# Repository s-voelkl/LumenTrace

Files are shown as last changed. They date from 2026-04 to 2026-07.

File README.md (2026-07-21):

# LumenTrace

A high-performance MCU-based LED racing simulator. Bringing the classic slot car experience to the world of addressable LEDs with real-time physics and advanced light effects.

> [!IMPORTANT]
>
> The **source code** for this project is available on **GitHub**: [github.com/s-voelkl/LumenTrace](https://github.com/s-voelkl/LumenTrace) [voelkl:2026lumentrace]

<div align="center">
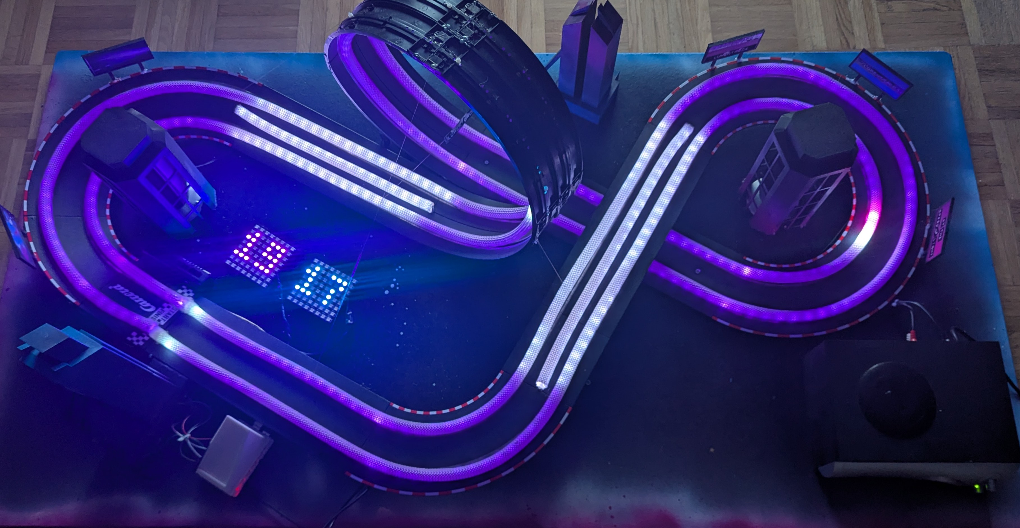
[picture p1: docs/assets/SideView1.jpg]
LumenTrace Game
  
</div>

References are provided in the format `[author:yearidentifier]` and are listed in the [Bibliography](docs/tech-rep/references.bib).

## Used Technologies

- Microcontrollers: Raspberry Pi Pico (Input Controller) and Raspberry Pi 4 (Core Host) [magpi:2024raspberry] with a micro-SD card for data storage.
- Programming Languages: MicroPython [george:2026micropython] for the microcontroller firmware, Python for OOP design, data processing, led display, sound, testing, simulation and visualization.
- Communication Protocols: High-Speed serial communication between Pico and Pi 4 with UART [pena:2020uart,liechti:2020pyserial], LED control via WS2812 [garff:2023rpi].
- Data Storage: Micro-SD card for storing and running the program on the Pi.

<div align="center">
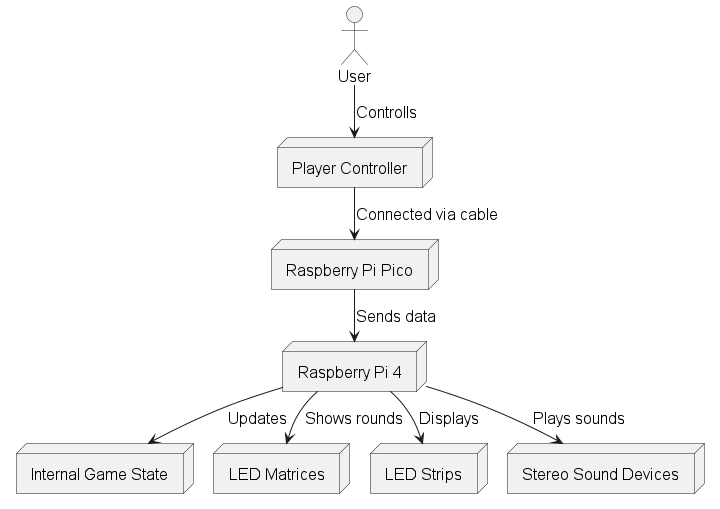
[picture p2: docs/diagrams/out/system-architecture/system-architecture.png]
System Architecture Diagram
  
</div>

## License

This project source code is licensed under the [MIT License](LICENSE). The documentation and assets are licensed under the [Creative Commons Attribution 4.0 International License](docs/LICENSE).

## Maintainers

The contributors and maintainers of this project are:

- Simon Völkl (<s.voelkl2@oth-aw.de>)
- Erik Dombrowsky (<e.dombrowsky@oth-aw.de>)
- Simon Frey (<s.frey@oth-aw.de>)

The project is part of the [Physical Computing Course](https://www.oth-aw.de/forschung/forschungseinrichtungen/labore/fakultaet-elektrotechnik-medien-und-informatik/labor-medieninformatik/physical-computing/) at the [OTH Amberg-Weiden](https://www.oth-aw.de/). The project is supervised by [Prof. Dipl.-Des. Martin Frey](https://www.oth-aw.de/hochschule/ueber-uns/personen/frey-martin/) and [Prof. Dr.-Ing. Ulrich Schäfer](https://www.oth-aw.de/schaefer-ulrich/ueber/).

## Initial Project Requirements

The following represents the original project requirements that evolved and adapted dynamically throughout development:

> Mechanics-free slot car track with: Control system, 3D printing, multiple RGB LED strips, sound, based on Raspberry Pi Pico 2W with PIO.

## Features

- **Realistic Physics Engine** – Experience accurate virtual slot car behavior with collision detection, dynamic acceleration/deceleration, and recovery mechanics that respond to your driving style.
- **Immersive LED Visuals** – Watch your car come alive with adaptive lighting: headlights brighten during acceleration, brake lights glow when decelerating, and dynamic lane indicators guide your racing line.
- **Live Round Counter** – Real-time LED matrix displays show your lap count instantly, keeping you informed of your progress without missing a beat.
- **Intuitive Control System** – Simple button-based controls for throttle and lane switching let you focus on racing, not learning complex mechanics.
- **Spatial Audio Experience** – Engine sounds respond to your speed and acceleration, with stereo positioning that tracks your position on the track for a truly immersive audio environment.
- **Adaptive Track Modules** – Each track section has unique driving characteristics and speed limits. Master different module types to optimize your performance.
- **Customizable Racing Experience** – Adjustable difficulty levels and driving profiles let you tailor the challenge to your skill level, from casual fun to competitive intensity.
- **Multi-Player Racing** – Compete against others in real-time with synchronized physics, collision detection, and dynamic lane management for intense multiplayer action.

## Usage

> [!NOTE]
> **Usage instructions:** For general requirements and usage instructions, please refer to the [Raspberry Pi 4](docs/rpi_4/rpi_4_config.md) and [Raspberry Pi Pico](docs/rpi_pico/rpi_pico_config.md) configuration guides.

**Docker** [merkel:2014docker] is used to provide a consistent, isolated environment for running the LumenTrace application on the Raspberry Pi 4. It automatically handles the installation of required system-level libraries and guarantees necessary privileged access for hardware GPIO [croston:2022raspberry], audio, and UART. By using docker, the application starts up automatically on boot and can be easily adjusted in a system-independent manner.

> [!NOTE]
> **Docker setup:** See the [Docker setup](docs/rpi_4/rpi_4_docker.md) for instructions on how to build and run the Docker container for LumenTrace.

## Hardware

The system is built on a distributed hardware architecture combining a Raspberry Pi 4 (Core Host) and a Raspberry Pi Pico (Input MCU).

- **Raspberry Pi 4 (Core Host):** Runs the main Python application (`src.rpi_4.main`), managing the game logic, physics simulation, LED display buffers, sound mixing, and logging.
- **Raspberry Pi Pico (Input MCU):** Runs MicroPython [george:2026micropython] firmware (`src.rpi_pico.main`) polling inputs from physical controllers (analog throttles via ADCs and digital buttons).
- **Communication:** The Pico transmits the controller states as a serialized format (JSON [json:2026introducing]) to the RPi 4 over UART [pena:2020uart] at high speed, removing the polling overhead from the main host.
- **LED Matrices & Strips:** RPi 4 drives WS2812B LEDs using DMA (PWM on GPIO 18/19), where the LED matrices for lap counting are physically chained before the track strips to minimize occupied hardware channels.
- **Audio:** Real-time engine and event audio is routed out of the Pi to stereo speakers.

<div align="center">
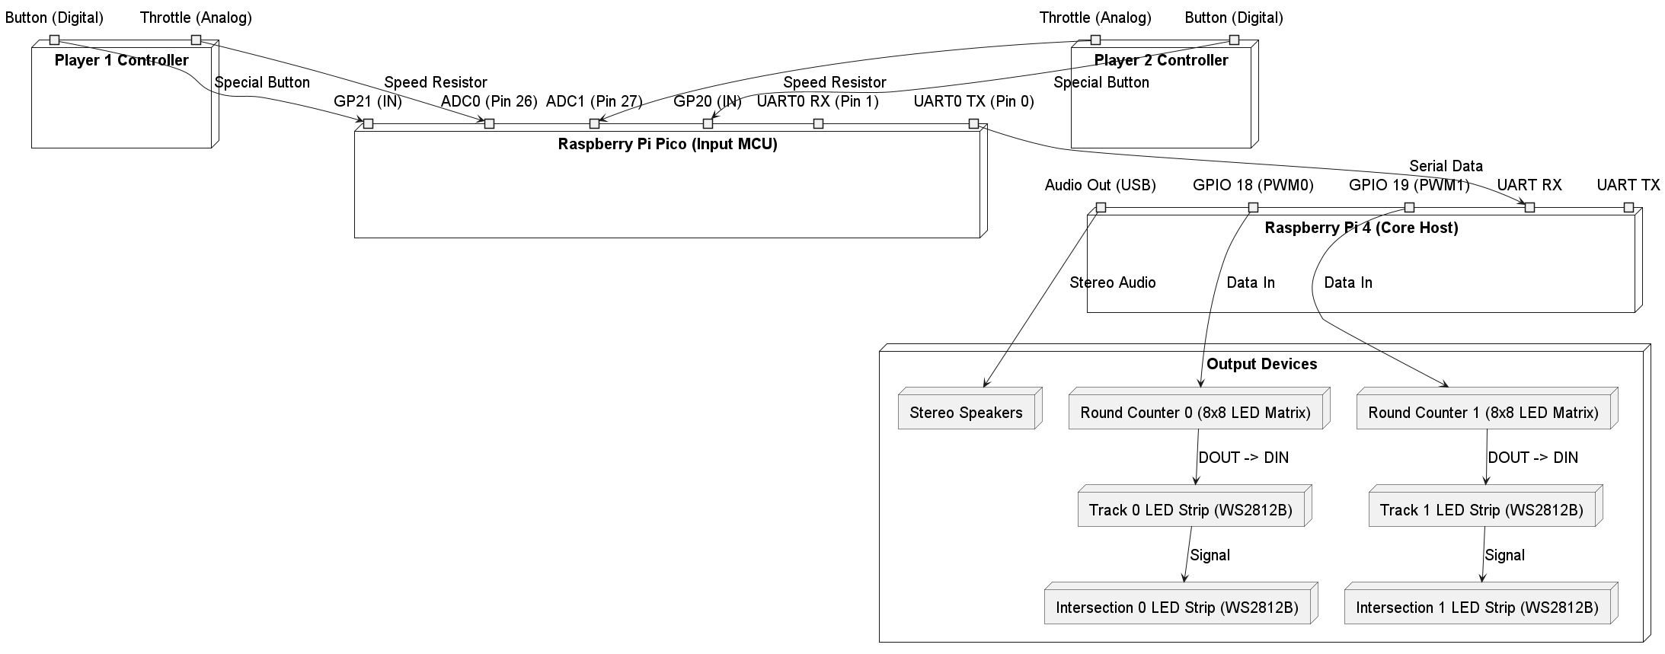
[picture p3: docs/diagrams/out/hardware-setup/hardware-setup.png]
Hardware Setup Diagram
  
</div>

## Architecture

The architecture is designed to be modular and extensible, with clear separation of concerns between different components:

- `Game` package handles the core game logic, including vehicle physics, track management, and players.
- `Simulation` package provides tools for testing and visualizing the game mechanics in Python.
- `Logger` package manages logging and debugging output for log files and MQTT [mqtt:2026mqtt] [light:2026paho]. Our approach to MQTT logging was inspired by the projects [voelkl:2026sensiq] and [voelkl:2026bitebound].
- `Controller` package handles player input and translates it into game actions.
- `Display` package manages the LED effects and visual feedback for the game.
- `Sound` package provides a real-time, threaded audio mixer.

<div align="center">
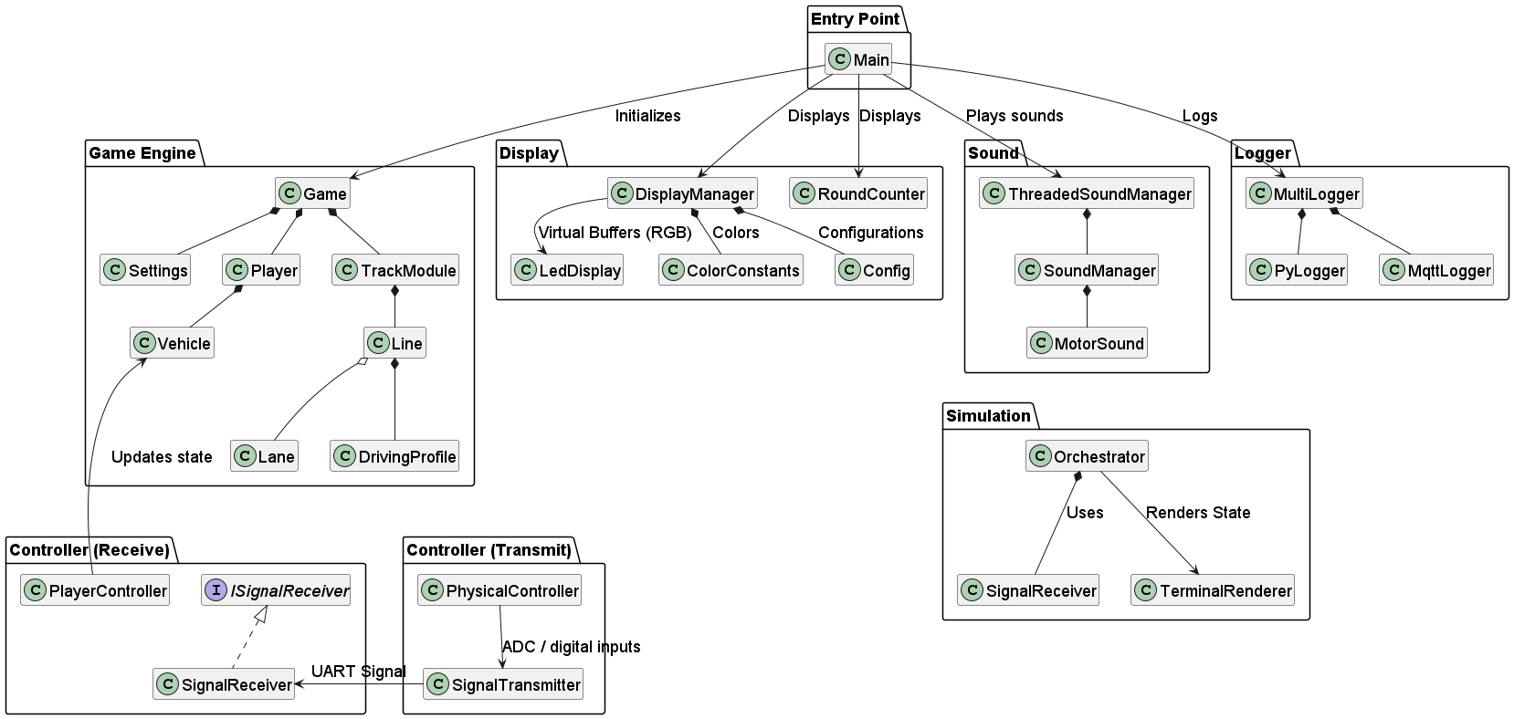
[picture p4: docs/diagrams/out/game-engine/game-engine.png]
Game Engine Architecture
  
</div>
<!-- ![Game Engine Architecture](docs/diagrams/out/game-engine/game-engine.png) -->

## LED Color Management

This project separates LED rendering into two responsibilities: color/buffer management and hardware rendering.

- `src/display/led_display.py`: Maintains per-lane virtual LED buffers and maps them onto physical `PixelStrip` instances. Implements helpers to set single pixels, windows and fill sections with a configurable color ratio.
- `src/display/display_manager.py`: Game-state -> visual logic. Implements the display hierarchy and writes colors into the virtual buffers maintained by the LED display.
- `src/display/color_constants.py`: Central RGB color constants used across the display code.
- `src/display/config.py` (and `DisplayConfig`): Runtime parameters that control blink intervals, round advance timing and other display tuning.

Display hierarchy (applied from low priority -> high priority):

1. **Track module base**: Entire lanes are painted a faint dark gray (ratio ~0.1) and each module's first pixel is emphasized (ratio ~0.3) to make module boundaries visible.
2. **Intersection module**: Track modules with allowed lane changes are painted with a light pink base (ratio ~0.1).
3. **Intersection animation**: When a vehicle is currently on an intersection the lane is temporarily overlaid with light pink (ratio ~0.2) to indicate the interaction.
4. **Start of the track**: The first pixel of every lane is marked as a start/end line (gray).
5. **Round advance**: When a vehicle completes a lap the start pixel blinks between yellow and white for a configured number of ticks.
6. **Inactive vehicles (respawn)**: Vehicles that are inactive or respawning blink between their primary color and gray (40% primary + 60% gray).
7. **Active vehicle**: Final override — vehicle sprite is drawn centered on the vehicle position. Color depends on the driving profile and vehicle speed [meschtscherjakov:2015chaselight]. Speeds near zero use the vehicle's primary color; values beyond thresholds interpolate toward accelerate/decelerate warning colors.
8. **Vehicle front lights**: Overlay front lighting (light gray) for vehicles that are currently accelerating.
9. **Vehicle rear lights**: Overlay rear brake lighting (red) for vehicles that are currently decelerating.

How the strips are controlled:

- Physical output uses the `rpi_ws281x` library (`PixelStrip`, `Color`) [garff:2023rpi]. Two GPIO channels are supported by default: `18` and `19` ([see Library on GitHub](https://github.com/richardghirst/rpi_ws281x))

> [!NOTE]
> **LED Mounting and Physical Chaining:** To map LEDs accurately to the physical track, the main strips were rigidly fastened using zip ties. Because both of the Pi 4's PWM channels were utilized for the primary lanes, the temporary central overtaking lane was physically daisy-chained to the end of a primary lane with connecting wires hidden beneath the track.

- The code uses `VirtualLedStrip` instances to map parts of a physical strip to logical lanes. This abstraction allows the display manager to control each segment (Lap Counter, Main Lane, and Overtaking Lane) independently, resolving the hardware channel constraints and hiding the physical daisy-chain from the game logic.
- At each game tick `Game.display()` calls `DisplayManager.update(game)`. The display manager updates the virtual buffers by writing RGB tuples. Finally `LedDisplay.render()` translates virtual buffers to the physical `PixelStrip` objects and calls `show()`.

Tuning and configuration:

- Colors are defined in `src/display/color_constants.py` so they can be changed globally.
- Timing and blinking behavior is configurable via `DisplayConfig` (e.g. `respawn_tick_color_change`, `round_advance_ticks`, `round_advance_tick_color_change`).
- Module boundary brightness and base-track ratio are implemented as small color ratios applied when filling lanes and pixels.

A current implementation of the LEDs can be found in `src/rpi_4/main.py`.

## Round Counter Hardware Integration

To track player progress, the game integrates 8x8 WS2812B LED matrices to display round numbers (00–99) using a 3x5 font mapping. Initial considerations for small LCD screens were discarded as they lacked readability from a 1-meter distance.

### Initial Bottlenecks

Initially, the round counters were configured on separate physical control lines:

- **Player 1 matrix** on GPIO 10 (SPI)
- **Player 2 matrix** on GPIO 21 (PCM)
- **Track lines** on GPIO 18 and 19 (PWM)

> [!CAUTION]
> **Failed Attempt:** This setup failed due to several hardware and library-level constraints:
>
> - **DMA Conflicts**: Initializing four distinct `PixelStrip` objects on DMA (Direct Memory Access) channel 10 caused register collisions and memory mapping failures (`mmap() failed`).
> - **Peripheral Clashes**: The underlying `rpi_ws281x` C driver cannot mix PWM, SPI, and PCM peripherals concurrently in the same process space.
> - **Channel Caps**: The driver structure is hardware-capped at 2 active physical channels.

### Resolved Design

The solution leverages the existing `VirtualLedStrip` concept by chaining the matrices to the end of the track strips:

> [!TIP]
> **Found Solution:**
>
> 1. **Physical Chaining**: The `Data In` (DI) of each matrix is wired to the `Data Out` (DO) of its corresponding track strip.
> 2. **Single-Driver Coordination**: The `num` parameter of the physical strips is increased to encompass the matrix pixels, keeping the physical control line > count at 2 (GPIO 18 & 19).
> 3. **Index Offsetting**: The `RoundCounter` is refactored to write directly to the track's existing `PixelStrip` starting at the correct pixel offset, > bypassing hardware re-initialization.

## Sound Engineering

LumenTrace features a real-time audio engine that turns the race into an immersive, spatial experience [gardenfors:2003designing]. All sound is mixed live on the Raspberry Pi and played back in stereo [geier:2024sounddevice] [bechtold:2026soundfile], so what you hear reflects what is happening on the track at every moment [gan:2019self].

### Real-time audio mixer

A low-level sound manager (`src/sound/sound_manager.py`) mixes any number of sounds simultaneously through a single stereo output stream. Every sound can be controlled independently while it plays:

- **Volume** – per-sound loudness plus a global master volume.
- **Pitch** – dynamic speed/pitch shifting, used to make the engine rev up and down.
- **Stereo panning** – independent left/right balance so sounds can be placed on the left or right side of the track.

To maximize execution speed and ensure high real-time performance on constrained hardware (like the Raspberry Pi), the audio engine is strictly optimized using a **block-level updates architecture** powered by NumPy vectorization [harris:2020array]:

- **Single Frame Indexing:** Rather than generating index arrays inside loops, a single frame index array (`np.arange`) is created once per callback block.
- **No Cumulative Ramping:** Dynamic playback positions are calculated using linear offsets (`arange_frames * pitch`) instead of sequential cumulative sums (`np.cumsum`), bypassing costly sample-by-sample pitch ramping.
- **Scalar Mixing Operations:** Dynamic parameter arrays are replaced with block-level scalar factors (`left_mult`, `right_mult`). Multiplications in the mixing stage are completed directly as fast scalar-by-array operations, avoiding expensive element-wise array generation and multiplications (such as `np.linspace` calls).
- **Smooth Easing:** The mixer gently adjusts overall volume, pitch, and panning properties block-by-block. This provides smooth, click-free parameter transitions at default block sizes (e.g. 1024 frames, ~23ms) while significantly reducing CPU overhead.

All sounds are referenced through a named catalog (`GameSound`), so each effect has a clear, human-readable name and a single source path.

### Thread Isolation & Concurrency Control

Because real-time audio relies on extremely strict timing guarantees, executing Python-based audio callback routines synchronously alongside high-frequency game ticks, screen rendering, and hardware fetching can lead to Global Interpreter Lock (GIL) starvation and severe lock contention.

> [!CAUTION]
> **Audio Engineering Challenges:** Initially, transmitting audio via the Pi 4's AUX jack produced significant background noise, which was resolved by switching to a USB audio interface. However, integrating the audio playback into the main game loop still caused heavy sound stuttering after ~2 seconds.

To eliminate these bottlenecks, LumenTrace isolates the audio interface using a **Thread-Safe Asynchronous Command Queue** pattern (`src/sound/threaded_sound_manager.py`) and multiprocessing principles [eggen:2019thread]:

- **Non-blocking Wrapper (`ThreadedSoundManager`):** Acts as a transparent proxy wrapping the low-level `SoundManager`. Calling threads (such as `GameTickThread` or input fetchers) never block or wait on the underlying mixer locks.
- **FIFO Command Queue:** Methods like `play()`, `update_sound()`, `stop_sound()`, and `stop_all()` immediately enqueue commands into a non-blocking queue [tsigas:2001simple] as lightweight, fire-and-forget tuples, generating trackable UUIDs instantly on the caller thread.
- **Dedicated Sound Worker Thread:** A background worker thread (`SoundWorkerThread`) continuously consumes the command queue and applies state changes to the actual `SoundManager`. This guarantees that high-frequency engine parameter updates do not block or stutter the physics loop.
- **Persistent Streams across Restarts:** The asynchronous `stop_all` implementation selectively clears active playback instances under lock instead of tearing down the audio stream. This keeps the output stream alive and responsive across multiple game restarts and lobby resets without requiring a full audio stream re-initialization.

> [!TIP]
> **Stability Fix:** Alongside the dedicated audio thread, introducing 1ms sleep intervals within the display logic prevented audio thread starvation, ultimately stabilizing the sound output across concurrent workloads.

### Engine sounds

Each car has its own continuous engine sound (`src/sound/motor_sound.py`) that reacts to how it is being driven:

- **Background rumble** follows the car's current **speed** – the faster the car, the higher and louder the engine note.
- **Acceleration layer** adds extra power and volume while the car is actively **accelerating**, so pressing the throttle is clearly audible.
- **Stereo position** follows the **track module** the car is currently on. Each track module defines a `sound_stereo_ratio_left` value (0.0 = fully right, 0.5 = centered, 1.0 = fully left), letting the engine sound travel between the left and right speakers as the car moves through left and right curves.

### Event sounds

On top of the engine, the game plays positional one-shot effects that respond to key race moments. Where it makes sense, these effects are panned to the position of the car that triggered them:

- **Start sequence** – a "3, 2, 1, GO!" signal plays in sync with the red/yellow/green countdown lights when all players hold their start button.
- **New lap** – a confirmation sound when a car completes a lap.
- **Lane change** – a short cue when a player presses the lane-change button.
- **Crash** – an impact sound when two cars collide or a car falls off the track.
- **Warning** – an alert when a car's speed or acceleration gets close to the limits allowed by the current track module's driving profile, hinting that the car is about to fall.

### Sound Effects Sources

> [!NOTE]
> **Sound Attribution:** All sound effects used in LumenTrace are sourced from free, royalty-free libraries [pixabay:2026pixabay] and are credited below. Please refer to the original sources for licensing details.

- base-engine-1.wav: Created by ourselves.
- startup-sound.mp3: <a href="https://pixabay.com/de/users/make_more_sound-35032787/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">Jesse Grum</a> from <a href="https://pixabay.com/sound-effects//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">Pixabay</a>
- car-crash-1.mp3: <a href="https://pixabay.com/de/users/dragon-studio-38165424/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">DRAGON-STUDIO</a> from <a href="https://pixabay.com//?utm_source=link-attribution&utm_medium=referral&utm_campaign=music&utm_content=376874">Pixabay</a>
- car-crash-2.mp3: <a href="https://pixabay.com/users/dragon-studio-38165424/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">DRAGON-STUDIO</a> from <a href="https://pixabay.com/sound-effects//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">Pixabay</a>
- car-lap-1.mp3: <a href="https://pixabay.com/users/moeeza3-39561198/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">Moeez Ahmad</a> from <a href="https://pixabay.com//?utm_source=link-attribution&utm_medium=referral&utm_campaign=music&utm_content=395038">Pixabay</a>
- car-lap-2.mp3: <a href="https://pixabay.com/users/soundreality-31074404/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">Jurij</a> from <a href="https://pixabay.com//?utm_source=link-attribution&utm_medium=referral&utm_campaign=music&utm_content=151963">Pixabay</a>
- race-finish.mp3: <a href="https://pixabay.com/users/bombinsound-54782632/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">Bomb Sound</a> from <a href="https://pixabay.com/sound-effects//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">Pixabay</a>
- coin-1.mp3: <a href="https://pixabay.com/de/users/u_u9ahoqos39-45535899/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">u_u9ahoqos39</a> from <a href="https://pixabay.com//?utm_source=link-attribution&utm_medium=referral&utm_campaign=music&utm_content=233860">Pixabay</a>
- coin-2.mp3: <a href="https://pixabay.com/users/driken5482-45721595/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">Driken Stan</a> from <a href="https://pixabay.com/sound-effects//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">Pixabay</a>
- warning-1.mp3: <a href="https://pixabay.com/users/dragon-studio-38165424/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">DRAGON-STUDIO</a> from <a href="https://pixabay.com//?utm_source=link-attribution&utm_medium=referral&utm_campaign=music&utm_content=386172">Pixabay</a>
- warning-2.mp3: <a href="https://pixabay.com/users/freesound_community-46691455/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">freesound_community</a> from <a href="https://pixabay.com//?utm_source=link-attribution&utm_medium=referral&utm_campaign=music&utm_content=104576">Pixabay</a>
- game-initialization.mp3: <a href="https://pixabay.com/users/dragon-studio-38165424/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">DRAGON-STUDIO</a> from <a href="https://pixabay.com/sound-effects//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">Pixabay</a>
- vibe-1-retro.mp3: <a href="https://pixabay.com/users/tg14_studios-55924971/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">TG14_Studios</a> from <a href="https://pixabay.com//?utm_source=link-attribution&utm_medium=referral&utm_campaign=music&utm_content=541395">Pixabay</a>
- vibe-2-retro.mp3: <a href="https://pixabay.com/users/freesound_community-46691455/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">freesound_community</a> from <a href="https://pixabay.com/sound-effects//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">Pixabay</a>
- vibe-3-retro.mp3: <a href="https://pixabay.com/users/freesound_community-46691455/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">freesound_community</a> from <a href="https://pixabay.com//?utm_source=link-attribution&utm_medium=referral&utm_campaign=music&utm_content=41048">Pixabay</a>
- punch-1.mp3: From <a href="https://pixabay.com/sound-effects/retro-hurt-sound-03-474780/">Pixabay</a>

## Game Mechanics

The game mechanics are implemented in `src/game` and are designed to provide a realistic and engaging racing experience like in the original slot car games [skaar:2025slot].

### Acceleration and Friction

- Controller input `forward_press` is mapped to vehicle acceleration each game tick. The mapping is configured as inputs [42000, 65536] to outputs [0, 100] with linear interpolation [zheng:2018feature].
- Friction is applied continuously and reduces current speed by a configurable percentage [kane:2022tire].
- Positive and negative movement are supported. If acceleration would invert speed direction in one step, speed is clamped to `0` first to keep transitions stable.

Acceleration mapping formula: $acceleration(forwardPress) = \frac{forwardPress - 42000}{65536 - 42000} * 100$

Sensor measurement transmission must be trustful [voelkl:2026sensiq] for the system handling the incoming data. Although, roughly every 20th controller transmission is lost or unreadable, the game engine is designed to handle this gracefully. Having an update rate of 50Hz, a single lost tick is not critical, the game engine just continues using the last known controller state.

### Speed Update and Limits

- Speed is updated every tick as: `speed += acceleration * acceleration_multiplier`
- Speed is clamped to `[-max_speed, +max_speed]`.
- This allows realistic throttle behavior while preventing unstable values at high update rates.
- A goal is to specify the friction and acceleration multipliers such that the vehicle can't possibly exceed the `max_speed` at all.

### Position and Round (Lap) Handling

- Position is updated from speed using the active game-tick interval.
- Each lane has its own total track length (sum of line lengths across modules).
- When position exceeds lane length, position wraps around and `round` is incremented and the position is reset.
- Reverse movement is also handled, including safe behavior for negative movement near lap boundaries.

### Lane Change

> [!NOTE]
> **Overtaking Mechanics Selection:** We evaluated multiple overtaking approaches: intersecting lanes (ruled out by vertical LED height), converging lanes (abrupt gameplay), and a unidirectional overtaking lane (lacked bidirectional switching). We ultimately chose a **temporary bidirectional center lane** because it offered the optimal balance between playability and realism.
>
> *Challenges solved:* The temporary lane eventually ends, potentially causing unavoidable out-of-bound crashes. We solved this by restricting lane changes beyond a specific point, forcing an automatic merge back to a main lane. We also implemented a cooldown distance (`lane_change_window`) to prevent rapid, successive lane changes and erratic switching.

- Lane changes are triggered by pressing the `special_1` button.
- A lane change is only allowed if the `driving_profile` of the current line has `lane_change_allowed = True`. This is typically used for intersection modules.
- By default, there are two main lanes: the left lane and the right lane. Intersections introduce a temporary middle lane to facilitate the switch.
- A manual lane change from the outer lanes to the middle lane can be initiated anywhere on the module, except for the last `lane_change_window` units before the end of the module.
- After pressing the button, the vehicle switches to the middle lane.
- From the middle lane, the player can switch to the target outer lane manually by pressing the button again, provided the vehicle has travelled at least `lane_change_window` units on the middle lane.
- The vehicle continues on the middle lane until it reaches the end of the module (specifically, `lane_change_window` units before the end). At that point, it automatically switches to the target outer lane, completing the lane change smoothly if the player hasn't already changed lanes manually.

### Position Conversion During Lane Change

- When the vehicle switches to or from the middle lane, it keeps its relative progress within the current track module.
- Conversion is proportional:
  - progress = `source_position / source_line_length`
  - target_position = `progress * target_line_length`
- This keeps cars visually and physically aligned when lane geometries have different lengths.

### Falling, Collision, and Respawn

- A vehicle falls immediately when its current speed or acceleration violates the driving profile of the active line:
  - `speed` must remain within `[min_speed, max_speed]`
  - `acceleration` must remain within `[min_acceleration, max_acceleration]`

> [!NOTE]
> **Track Profile Constraints / Subdivided Modules:** To make difficulty scale smoothly without applying constraints too abruptly upon module entry, specific modules were mathematically subdivided. **Curves** have an Entry (slight restriction), Apex (strongest restriction), and Exit (reduced restriction). **Loops** have an Incline Entry (gravity decelerates), Inverted Apex (high minimum speed required to avoid falling), and Decline Exit (gravity accelerates).

- Collision detection is evaluated for vehicles on the same lane.
  - If two vehicles are within collision distance, the vehicle in front falls.
  - The collision happens, if the position distance between the `settings.__vehicle_crash_distance` is violated.

> [!NOTE]
> **Collision Gameplay Dynamics:** While a real-world collision would likely derail both vehicles, this heavily impacts gameplay negatively. Taking inspiration from other arcade video games, we implemented a system simulating a rear-quarter impact: The leading vehicle loses control and crashes, while the trailing vehicle maintains its trajectory unharmed.

### Respawn System

> [!NOTE]
> **Fair Respawn Logic & The Looping Problem:** Several respawn rules were evaluated:
>
> 1. *Respawn at Start Line:* Harsh penalty causing players to fall too far behind with no chance to interact.
> 2. *Respawn at Exact Crash Location:* Too forgiving, and it introduced the "Looping Problem" (respawning at a standstill inside a loop causes an immediate consecutive crash, as vehicles cannot build the needed momentum).
> 3. *Respawn at Start of Current Module:* Selected for balanced penalization.
>
> A dynamic fallback system handles blocked placements: If a respawn spot is occupied (which would cause an immediate collision upon respawn), the game sequentially checks alternative lanes, then falls back purely to previous modules to grant collision-free placement with enough track length to build momentum for upcoming loops.

- Fallen vehicles become inactive and enter a respawn state (`settings.respawn_ticks`, `vehicle.respawn_ticks`, `vehicle.active`).
- While `vehicle.active` is `False`, vehicles are ignored in the race.
- After the `vehicle.respawn_ticks` count down to `0`, the vehicle attempts to respawn:
  - If the module where the vehicle fell is a LOOPING module, step back one module to avoid respawning in the same looping section (unless it's the only module).
  - Try `position = 0` on the preferred lane within the target respawn module. If not available, try other unoccupied lanes on that module. Unoccupied means no active vehicle is on the module.
  - If no lane is available on the target module, fallback to the previous modules, checking all lanes from outer (most active vehicles) to inner.
  - The vehicle speed and acceleration are reset to `0`, `vehicle.respawn_ticks` to `0`, and its lane change state is cleared.
  - If no lane is available across all candidate modules, the vehicle remains inactive and tries again in the next tick.
- Respawn does not increment `vehicle.round`.

## Design

The design of the LumenTrace system is modular and extensible, allowing for easy integration of new features and components [voelkl:2026bitebound]. In general, the physical design is based on the following components:

- A black wooden plate (150cm × 80cm) as the base for the track layout, sprayed with *blue*, *purple*, and *white* colors for a visually appealing background. All components were rigidly fastened using screws, cyanoacrylate adhesive, and double-sided tape for transportability. The loop module was additionally reinforced with fishing line to reduce vibrations and prevent fractures.
- Carrera GO!!! [carrera:2026carrera] track modules for the physical track layout.
- 2 LED Stripes (WS2812B) for the track lighting and visual effects, mainly in light purple and gray.
- 2 Vehicles in strong blue and purple colors.
- 2 LED Matrizes for round counting in the colors of the vehicles.
- 3D-printed objects as visual enhancements, custom towers to conceal the Raspberry Pi 4, Pico, and internal wiring, and custom audio enclosures to stealthily house the stereo speakers and subwoofer (printed in segments) without breaking the sci-fi aesthetic.

**LED Strip Design Rationale:** The LED stripes do not directly illuminate the user but are housed within a translucent plastic channel, further wrapped with a white fabric strip in a cylindrical configuration. This design approach diffuses light in all directions, creating a uniform and pleasant ambient lighting experience throughout the track environment. Standard LED strips would lack the mechanical flexibility required to conform to the track's varying curvatures and would fail to distribute light evenly across all viewing angles. Additionally, power consumption was carefully constrained, as the system is powered directly from the Raspberry Pi; exceeding safe current limits would necessitate thicker cabling and an external high-capacity power supply, both of which would compromise system safety and transportability. The implementation employs two WS2812B addressable LED strips, each equipped with 50 Neopixel LEDs per meter, totaling 250 LEDs across the entire track lighting system.

The resulting design is a **retro-futuristic** blue-purple racing environment with a focus on immersive lighting and sound effects.

<div align="center">
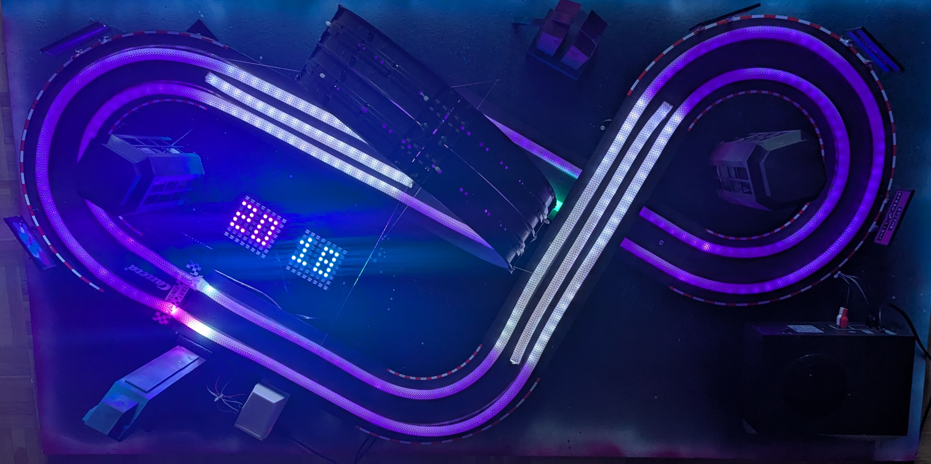
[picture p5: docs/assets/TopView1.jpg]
LumenTrace Top View
  
</div>

### 3D-Printed Objects

All 3D-printed objects were designed in Blender, Fusion 360, TinkerCAD, retrieved from Online Sources, or generated by AI. The files are available in the `3d-models` folder, see the [documentation file](3d-models/3d-models.md) for details.

## Local Simulation and Unit Tests

> [!NOTE]
> **Simulation Runner:** For fast manual validation of game logic, a text-based simulation runner is available at `src/dev/simulation.py`.
> Execution is possible with: `python -m src.dev.main`

A simulation dashboard was developed during the development phase to visualize the game state in real-time without the need for physical hardware. As the code has evolved, the simulation *might not be fully up-to-date* with the current game logic, but it still serves as a useful tool for debugging and understanding the system's behavior.

The simulation dashboard displays:

- Global settings (`max_speed`, friction, lane-change timing, respawn timing, etc.)
- Full player and vehicle telemetry (lane, position, speed, acceleration, lap, respawn state)
- Full track module list including per-lane driving profiles
- Current player module context (`module_index:track_type@local_position`)
- ASCII lane visualization with module boundaries and live player markers

Additionally, unit tests were created to validate the logic of specific components during the development phase, as described in the [test document](tests/tests.md).

<div align="center">
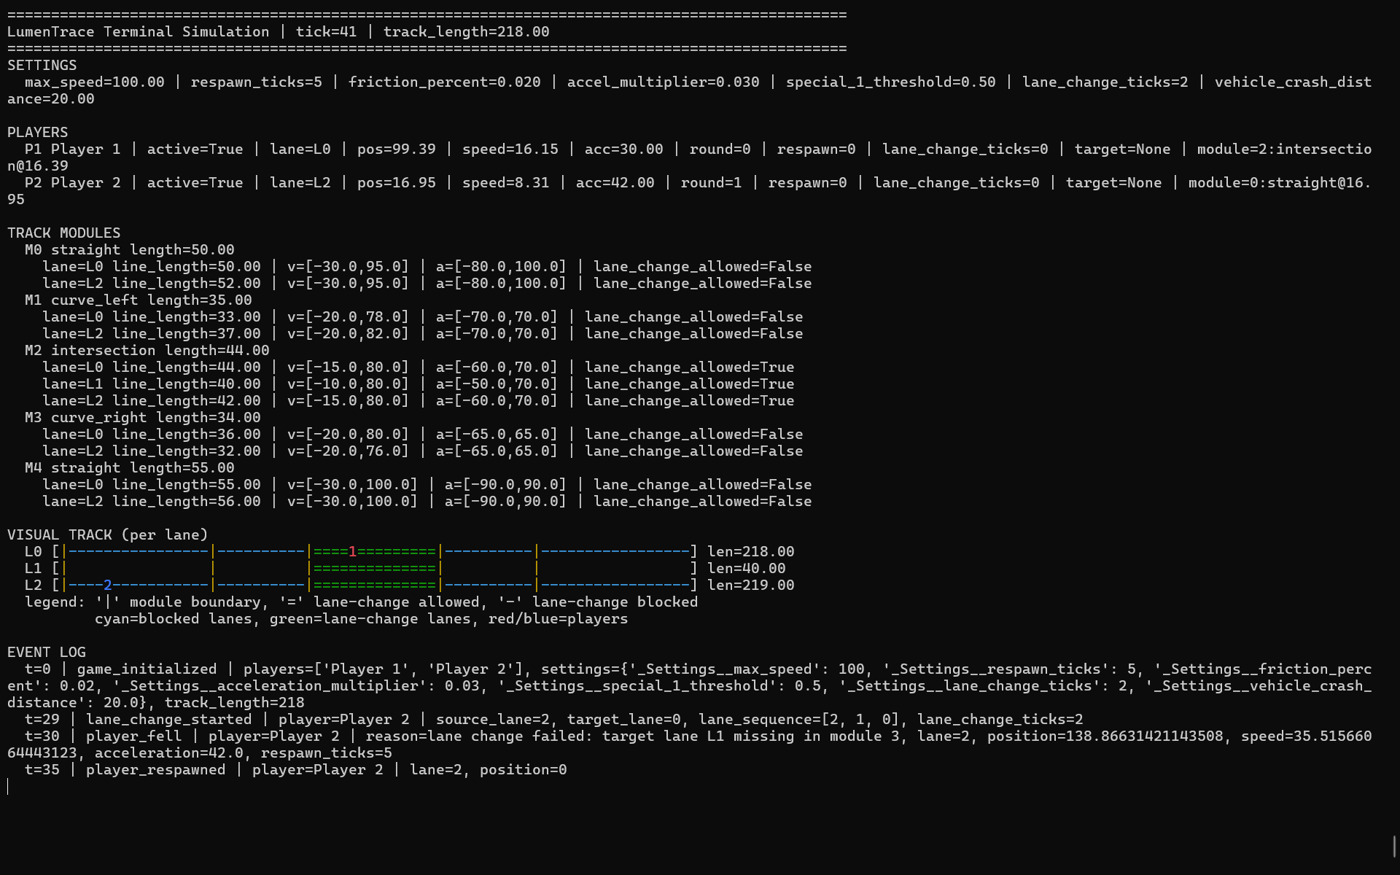
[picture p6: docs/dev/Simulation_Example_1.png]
Simulation Example
  
</div>

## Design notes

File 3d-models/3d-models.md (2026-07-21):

# 3D Models — LumenTrace

## Overview

The 3D model collection supports LumenTrace's physical infrastructure [voelkl:2026lumentrace], combining functional mechanical components with decorative environmental assets. Models are designed for 3D printing in a cohesive sci-fi aesthetic, integrating seamlessly with the racing simulation environment and audio system.
Not all of the proposed models were used in the final build, as some were replaced with alternative solutions during development or were not able to be produced due to time, resource and real-world constraints.

## Model Categories

### Mechanical Components

Functional parts required for the racing track and LED integration, including LED strip mounting fixtures, connectors, and control cable housings. Even though these components are engineered for precision fit and durability under repeated use, they were not used in the final product, as better alternatives were found and implemented.

### Environmental Decoration

Scenery and decorative structures that establish the immersive sci-fi environment surrounding the race track. These include landscape elements, architectural structures, lighting fixtures, and industrial-themed accents that enhance visual immersion without affecting gameplay.

### Audio Equipment Integration

Custom enclosures and housings for the 2.1-channel stereo speaker system, designed to complement the overall aesthetic. These cases provide protection for the audio components while ensuring optimal sound projection and integration with the track environment.

## Design and Production

All 3D-printed objects were designed in Blender, Fusion 360, TinkerCAD, retrieved from Online Sources, or generated by AI. The files are available in the folders `scad` and `stl`.

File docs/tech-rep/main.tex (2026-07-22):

\documentclass[10pt,journal,final,a4paper]{IEEEtran}

% --- 1. Mathematik & Symbole ---
\usepackage{amsmath} 
\usepackage{amssymb}
\usepackage{amsfonts}

% --- 2. Code-Blöcke (Zuerst laden wegen fvextra/lineno-Interaktionen) ---
% \usepackage{minted} 
\usepackage{listings}

% --- 3. Text & Sprache (csquotes MUSS nach minted/fvextra geladen werden) ---
\usepackage{csquotes} 

% --- 4. Tabellen & Grafiken ---
\usepackage{color,array}
\usepackage{graphicx}
\usepackage{multirow} 
\usepackage{booktabs} 
\usepackage{float}
\usepackage{siunitx}
\usepackage{tabularx}

% --- 5. IEEEtran Layout-Helfer (algorithmic gelöscht, da nicht vorhanden/benötigt) ---
\usepackage[caption=false,font=normalsize,labelfont=sf,textfont=sf]{subfig}
\usepackage{textcomp}
\usepackage{stfloats}
\usepackage{verbatim}
\usepackage{balance}

% --- 6. Links & Referenzen (Immer ganz ans Ende der Präambel) ---
\usepackage[colorlinks,urlcolor=blue,linkcolor=blue,citecolor=blue]{hyperref}
\usepackage{orcidlink} % benötigt hyperref, daher danach laden
\usepackage[capitalise,nameinlink,noabbrev]{cleveref} % MUSS als letztes geladen werden

% --- IEEEtran spezifische Definitionen ---
\hyphenation{op-tical net-works semi-conduc-tor IEEE-Xplore}
\def\BibTeX{{\rm B\kern-.05em{\sc i\kern-.025em b}\kern-.08em
    T\kern-.1667em\lower.7ex\hbox{E}\kern-.125emX}}

\newtheorem{theorem}{Theorem}
\newtheorem{lemma}{Lemma}
\setcounter{page}{1}

\begin{document}

\title{LumenTrace: A Mechanics-Free LED Slot Car Racing Game with Real-Time Physics and Immersive Audiovisual Feedback} 

% TODO FOR PUBLICATION: Remove Physical Computing Lecture from author footnote, add ORCID links to all authors.
\author{Simon Völkl\,\orcidlink{0009-0005-5334-9673}, 
        Erik Dombrowsky, 
        and Simon Frey%
\thanks{The authors are with the Department of Electrical Engineering, Media, and Computer Science, Ostbayerische Technische Hochschule Amberg-Weiden, 92224 Amberg, Germany (e-mail: s.voelkl2@oth-aw.de; e.dombrowsky@oth-aw.de; s.frey@oth-aw.de). The project is part of the Physical Computing Course at OTH Amberg-Weiden and is supervised by Prof. Dipl.-Des. Martin Frey and Prof. Dr.-Ing. Ulrich Schäfer.}%
}

% \markboth{TECHNICAL REPORT, 07 2026}
% TODO FOR PUBLICATION: Update date to actual submission date, remove information from lecture.
\markboth{TECHNICAL REPORT FOR PHYSICAL COMPUTING LECTURE AT OTH AMBERG-WEIDEN, 07 2026}
{Völkl \MakeLowercase{\textit{et al.}}: LumenTrace}

\maketitle

\begin{abstract}
    % \textbf{Background:} 
    Classic slot car systems offer an engaging tactile racing experience, yet they remain bound to physical vehicles on mechanical rails and treat light and sound as secondary embellishments. Simultaneously, minimalist LED racers reduce gameplay to button pressing and omit realistic physics, spatial audio and advanced track features.
    % \textbf{Objective:} 
    LumenTrace aims to unite the physical realism and playability of slot cars with the mechanical simplicity and immersive, state-driven audiovisual feedback that individually addressable LEDs make possible.
    % \textbf{Methods:} 
    The system is built on a distributed Raspberry~Pi Pico and Raspberry~Pi~4 architecture. A real-time physics engine models acceleration, friction, collision detection, and crash recovery from throttle and button inputs transmitted over a high-speed UART link. A priority-based LED rendering pipeline displays adaptive, state-dependent track and vehicle effects, complemented by a stereo audio mixer.
    % \textbf{Results:} 
    The system meets its real-time thread budgets and low-latency requirements, resulting in positive user feedback during playtests, though it lacks cost-effectiveness for open-source developers. 
    % \textbf{Conclusion:} 
    LumenTrace closes the gap between commercial slot car systems and minimalist LED racers, while providing highly performant, maintainable and safe system architecture. Future work focuses on cost reduction, improved playability, and game extensions.
\end{abstract}

\begin{IEEEkeywords}
    Distributed Embedded Systems, LED Racing Game, Microcontroller, Real-Time Physics Engine, Slot Car Racing, Spatial Audio, WS2812B
\end{IEEEkeywords}

% \tableofcontents

\section{Introduction}
\label{sec:introduction}

\IEEEPARstart{S}{lot} car racing has entertained enthusiasts for decades, but its classic form ties the experience to physical vehicles running on mechanical rails, where light and sound serve merely as peripheral embellishments. 
LumenTrace reimagines this concept as a mechanics-free racing simulator in which each vehicle is represented directly as a moving point of light on an individually addressable light-emitting diode (LED) strip. 
Built on a distributed architecture of a Raspberry~Pi Pico and a Raspberry~Pi~4~\cite{magpi:2024raspberry}, the system couples a real-time physics engine with a priority-based LED rendering pipeline and a spatial audio mixer to deliver an immersive, state-driven racing experience without any moving mechanical parts. 
The complete source code and documentation are publicly available in the project's GitHub repository~\cite{voelkl:2026lumentrace}.

\begin{figure*}[tb]
    \centering
    
    \caption{LumenTrace: at the speed of light. Full-scale setup of the LED racing game showing the track, vehicles, controllers, and audiovisual system.}
    \label{fig:lumentrace-setup}
\end{figure*}

\subsection{Motivation}
\label{subsec:motivation}

Classic slot car systems deliver an engaging tactile racing experience, but they remain bound to physical vehicles running on mechanical rails. In these systems, light and sound are treated as peripheral add-ons rather than as core gameplay elements: engine sounds are typically monotone and decoupled from the vehicle's actual speed, and illuminated track sections merely blink in fixed patterns instead of responding to the race state~\cite{carrera:2026light}. Even highly digitalized products such as Carrera Digital~132~\cite{carrera:2026digital}, Anki Overdrive~\cite{anki:2026overdrive} or Scalextric ARC~PRO~\cite{scalextric:2026arc} retain physical cars and use audiovisual feedback only as a secondary layer.

LED-based racing games take the opposite approach and represent each vehicle directly as a moving light on an individually addressable strip~\cite{openledrace:2023article,pereira:2023applying}. This removes all moving parts, yet existing projects stay deliberately minimalistic: gameplay is reduced to button mashing, and features such as a realistic physics model, spatially positioned audio, bidirectional lane changing, collision recovery, and modular track profiles are absent. As detailed in~\Cref{sec:related-work}, no existing system combines the physical realism and playability of slot cars with the mechanical simplicity and immersive, state-driven audiovisual feedback that addressable LEDs make possible. LumenTrace is motivated by closing precisely this gap.

\subsection{Problem Statement}
\label{subsec:problem-statement}

The central problem addressed by LumenTrace is the absence of a racing system that simultaneously provides the realistic physics and competitive playability of commercial slot cars and the mechanical simplicity and expressive, state-driven audiovisual feedback of addressable LED strips. 
Commercial slot car systems retain physical vehicles on mechanical rails and relegate light and sound to fixed, speed-decoupled embellishments, whereas existing LED racers reduce gameplay to acceleration pulses and omit a realistic physics model, spatial audio, bidirectional lane changing, collision recovery, and modular track profiles. LumenTrace therefore sets out to design and implement a mechanics-free LED slot car simulator that unifies these two design spaces on a low-latency, maintainable, and safe distributed embedded architecture.

\subsection{Contributions}
\label{subsec:contributions}

LumenTrace contributes a mechanics-free LED slot car simulator that unifies the strengths of both worlds on a distributed Raspberry~Pi Pico and Raspberry~Pi~4 architecture~\cite{magpi:2024raspberry}. 
At its core is a real-time physics engine that models acceleration, friction, speed clamping, collision detection, and crash recovery, driven by analog throttle and digital button inputs transmitted over a high-speed Universal Asynchronous Receiver/Transmitter (UART) link~\cite{pena:2020uart}. On top of this, a priority-based LED rendering pipeline paints the track and vehicles with layered, state-dependent effects, including adaptive vehicle colors, headlights, and brake lights that give the driver ambient feedback about speed~\cite{meschtscherjakov:2015chaselight}, together with round counters realized through physically chained WS2812B matrices~\cite{garff:2023rpi}. 
A vectorized, thread-isolated stereo audio mixer adds per-vehicle engine sounds whose pitch and stereo position follow the car's speed and track position, complemented by positional event sounds. Playability is extended beyond prior LED racers through a temporary bidirectional overtaking lane and modular track modules with individual driving profiles. Finally, the system is packaged for reproducible deployment via Docker~\cite{merkel:2014docker} and ships with a hardwareless simulation interface for development and testing without physical hardware. 

\subsection{Document Outline}
\label{subsec:document-outline}
% TODO FOR PUBLICATION: Remove project management!

The remainder of this report is organized as follows.~\Cref{sec:related-work} surveys commercial slot car systems and open-source LED racing projects.~\Cref{sec:system-requirements-and-architecture} specifies the functional and non-functional requirements and derives the distributed system architecture.~\Cref{sec:hardware-implementation} details the microcontroller setup, the UART communication interface, and the physical design.~\Cref{sec:software-implementation-and-game-mechanics} describes the software architecture and the physics-based game mechanics, while~\Cref{sec:multimedia-subsystems} covers the priority-based LED rendering pipeline and the real-time audio mixer.~\Cref{sec:project-management} reports on the project management and task distribution,~\Cref{sec:evaluation} evaluates the resulting system, and~\Cref{sec:conclusion-and-future-work} concludes and outlines future work.

\section{Related Work}
\label{sec:related-work}

LumenTrace sits at the intersection of two established domains: commercial slot car racing systems and open-source LED strip games. This section surveys both landscapes to contextualize the design decisions presented in the remainder of this report.

\subsection{Existing Slot Car Systems}
\label{subsec:existing-slot-car-systems}

Commercial systems have steadily added electronics while keeping physical cars on mechanical rails. Carrera Hybrid~\cite{carrera:2026hybrid} pushes toward a more digitalized and realistic racing simulation with collisions, overtaking, and modular track assembly. Carrera Digital~132~\cite{carrera:2026digital} offers button-triggered lane changes, lap counters, start lights, driver displays, and wireless controllers, but the vehicles remain fully physical rather than simulated. Scalextric ARC~PRO~\cite{scalextric:2026arc} adds an app-based interface with pit stops, lap-time tracking, weather conditions, and multiple race modes, while reducing the controller to a brake and a lane-change button. Anki Overdrive~\cite{anki:2026overdrive} abandons fixed slots in favor of app-controlled autonomous cars on magnetically connectable, modular track segments.

Across these systems, light and sound serve as secondary embellishments rather than integral gameplay elements. Many hobbyist Carrera GO!!!~\cite{carrera:2026carrera} layouts add track-side lighting such as traffic signals, small LCD readouts, or vehicle head- and tail-lights, yet these effects are neither integrated into the race flow nor used to illuminate the lanes themselves. The Carrera GO!!! Light and Sound Looping Set~\cite{carrera:2026light} is representative: roughly 16~LEDs on each side of the looping blink red and white as a car passes, accompanied by a fixed engine sound effect. Both the blinking and the sound are static and remain decoupled from the actual vehicle speed. Even in the most digital products, audio is dominated by the mechanical friction noise of the miniature cars and is limited to short indicator cues at the start and on completing a lap.

\subsection{LED-Based Projects and Racing Games}
\label{subsec:led-based-projects-and-racing-games}

A parallel line of work explores addressable LED strips as minimalist, one-dimensional game displays driven by simple controllers. Line Wobbler~\cite{baumgarten:2023line} is an award-winning one-dimensional dungeon crawler whose custom controller consists of a spring and a circa \SI{5}{\meter} LED strip; it has been widely exhibited in museums and has inspired follow-up projects such as the Arduino-based crawler TWANG~\cite{critters:2020twang}. These titles demonstrate the appeal of novel input mechanics and physical space, yet they remain single-player experiences without competitive racing elements. 

The most directly related project is the open-source Open LED Race (OLR) developed since 2019~\cite{pereira:2023applying}. OLR simulates a slot car track on a WS2812/WS2813 strip, representing each player as a colored light that advances by one acceleration pulse per button press, and supports up to four cars with optional slopes and gravity, a pit lane, and an electric-car mode requiring recharging~\cite{openledrace:2023article,openledrace:2025project}. The project has evolved through numerous community forks: extended gravity, sound, and lighting effects~\cite{arminjo:2025open}, a layout with 3D-printed track elements focussing on design~\cite{hackerspace:2024open}, an added 16\,$\times$\,16 LED matrix display~\cite{framboise:2024open}, a TinyGo reimplementation~\cite{esteban:2019ledrace}, and wireless ESP-based remote controllers~\cite{gmag11:2020ledrace}.

LumenTrace shares OLR's foundational ingredients of controller input, addressable LED strips, and microcontroller-based execution, but deliberately targets a different point in the design space. It omits OLR features such as gravity slopes, pit-lane recharging, and the electric-car mode, and instead introduces a realistic physics model, bidirectional lane changing, collision detection with crash recovery, priority-based immersive lighting, spatial audio, and modular track profiles. In doing so, LumenTrace bridges the realism and playability of commercial slot car systems with the flexibility and expressive audiovisual potential of LED-based games.

\section{System Requirements and Architecture}
\label{sec:system-requirements-and-architecture}

This section defines the functional and non-functional requirements that guided the development of LumenTrace and derives the system architecture that satisfies them.

\subsection{System Requirements}
\label{subsec:system-requirements}

The system requirements define both functional capabilities and non-functional performance constraints that ensure LumenTrace meets user expectations and technical standards.

\subsubsection*{Functional Requirements}

The initial project scope centered on developing a mechanics-free digital slot car racing system with a real-time control system, individually addressable red, green, and blue (RGB) LED strips for track and vehicle visualization, basic sounds, and utilizing the Raspberry Pi Pico~2~W microcontroller with PIO. Additionally, emphasis on design and playability was laid out to ensure an engaging user experience.

\subsubsection*{Non-Functional Requirements}

The system was designed to meet the following quality and performance attributes:

\begin{itemize}
    \item \textit{Performance:}
    The system must render at greater than \SI{24}{\hertz} for human-perceivable smoothness. Controller inputs must be processed with minimal latency (less than \SI{100}{\milli\second} end-to-end) to provide responsive, immediate feedback during gameplay.
    
    \item \textit{Scalability:}
    The modular software architecture must support straightforward extension with new track modules, driving profiles, light and sound effects without requiring core system modifications.
    
    \item \textit{Safety:}
    All electrical hazards must be mitigated through proper insulation and power management. Mechanical components must be designed to eliminate sharp edges and pinch points accessible to users.
    
    \item \textit{Reliability and Availability:}
    The system must gracefully handle errors and automatically recover or restart. Cold boot initialization must complete within \SI{120}{\second} to minimize user wait time.
    
    \item \textit{Maintainability:}
    The codebase must be well-documented with clear separation of concerns. Hardware and software components must be independently testable and replaceable without system-wide redesign. A simulation interface must be provided for development and testing without requiring physical hardware.
    
    \item \textit{Usability:}
    The user interface must be intuitive and require minimal learning. Controller operation, track physics, and audiovisual feedback must be immediately comprehensible to new players. The game difficulty must be accessible to casual users while remaining engaging for experienced players.
\end{itemize}

\subsection{High-Level Architecture}
\label{subsec:high-level-architecture}

LumenTrace is built on a distributed two-tier architecture that splits the workload between an input-gathering microcontroller and a central core host~\cite{magpi:2024raspberry}, as depicted in~\Cref{fig:system-architecture}. The input controller captures the physical user commands and streams them over a serial connection to the main processing unit. The core host then executes the central application to resolve the game state and drive the output devices.

This separation of concerns offloads the latency-critical, high-frequency input sampling from the core host, allowing it to dedicate its computational resources to processing game state and real-time feedback without incurring polling overhead. Structuring the system into independent, well-defined subsystems also keeps it modular, maintainable, and scalable.

\begin{figure}[h]
    \centering
    
    \caption{High-level system architecture of LumenTrace, showing the distributed setup with the Raspberry~Pi Pico as input microcontroller and the Raspberry~Pi~4 as core host.}
    \label{fig:system-architecture}
\end{figure}

\section{Hardware Implementation}\label{sec:hardware-implementation}

This section describes the hardware realization of LumenTrace, covering the distinct roles of the two microcontrollers, the serial communication interface between them, and the physical construction of the track and controllers.

\subsection{Microcontroller Setup}
\label{subsec:microcontroller-setup}

As illustrated in~\Cref{fig:hardware-setup}, the specific hardware configuration establishes the low-level execution environments for both devices. The Raspberry~Pi Pico acts as the dedicated input microcontroller running MicroPython firmware~\cite{george:2026micropython}. It permanently and latency-free samples the physical controllers, utilizing its internal 12-bit analog-to-digital converters (ADCs) channels to read the analog throttles and its General Purpose Input/Output (GPIO) pins to detect digital button presses.

Conversely, the Raspberry~Pi~4 functions as the core host, booting its operating system and the main Python application from a micro-SD card to enable fully autonomous physical startup. The Pi~4 processes the inputs transmitted by the Pico to maintain the internal game state and execute physics ticks. It translates this game state into audiovisual feedback by actuating the LED strips and matrices~\cite{garff:2023rpi}, and by driving the stereo audio mixer.

\begin{figure*}[tb]
    \centering
    
    \caption{Hardware setup of LumenTrace: The Raspberry~Pi Pico handles controller inputs and transmits them to the Raspberry~Pi~4, which drives the output devices.}
    \label{fig:hardware-setup}
\end{figure*}

\subsection{Communication Interface}
\label{subsec:communication-interface}

The Pico and the Pi~4 communicate over a high-speed UART link~\cite{pena:2020uart,liechti:2020pyserial}. On every polling cycle, the Pico serializes the current state of all connected controllers into a compact JavaScript Object Notation (JSON) structure~\cite{json:2026introducing} and transmits it to the Pi~4. Delegating input acquisition and serialization to the Pico relieves the core host from polling overhead, so that it can consume the most recent controller state directly instead of sampling the hardware itself. As shown in~\Cref{fig:controller-json}, each controller entry reports a unique \texttt{controller\_id}, the raw analog throttle value \texttt{adc\_0}, and the digital button state \texttt{dig\_0}.

\begin{figure}[h]
    \centering
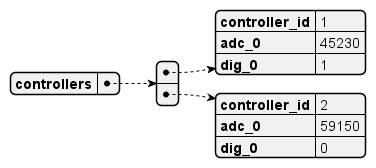
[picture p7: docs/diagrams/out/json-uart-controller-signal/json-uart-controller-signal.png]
    
    \caption{Example of the JSON structure transmitted from the Pico to the Pi~4 over UART, containing the current state of two controllers.}
    \label{fig:controller-json}
\end{figure}

At an update rate of \SI{50}{\hertz}, the protocol tolerates sporadic transmission losses: roughly every twentieth packet is dropped or unreadable, yet a single missing update is uncritical because the game engine simply continues with the last known controller state until the next valid packet arrives.

\subsection{Physical Design and Controllers}
\label{subsec:physical-design-and-controllers}

The physical setup is built on a black wooden base plate of \SI{150}{\centi\meter}~$\times$~\SI{80}{\centi\meter}, spray-painted in blue, purple, and white to create a retro-futuristic backdrop. 
The track layout reuses Carrera~GO!!!~\cite{carrera:2026carrera} track modules, along with two \SI{5}{\meter} highly diffusing LED strips carrying \num{50} LEDs per meter (\num{250} LEDs in total), to visualize the lanes, vehicles and intersections. All components were rigidly fastened using screws, cyanoacrylate adhesive, and double-sided tape to preserve transportability, and the looping module was additionally reinforced with fishing line to prevent fractures.

The original Carrera~GO!!! hand controllers were modified from their built-in variable resistors into signal sources for the Pico. Each throttle is wired as a voltage divider feeding one of the Pico's ADC channels, yielding the raw analog value transmitted as \texttt{adc\_0}, while an added push button provides the digital lane-change signal (\texttt{dig\_0}). 

Custom 3D-printed enclosures, styled to match the sci-fi aesthetic, conceal the Raspberry~Pi~4, the Pico, the internal wiring, and house the stereo speakers. Beyond their visual role, these enclosures also serve a safety function: together with the only \SI{3}{\ampere} power draw per LED strip, they cover the electronics to prevent user contact and eliminate sharp edges and pinch points. The full physical design of the system is shown in~\Cref{fig:physical-design}.

\begin{figure}[h]
    \centering
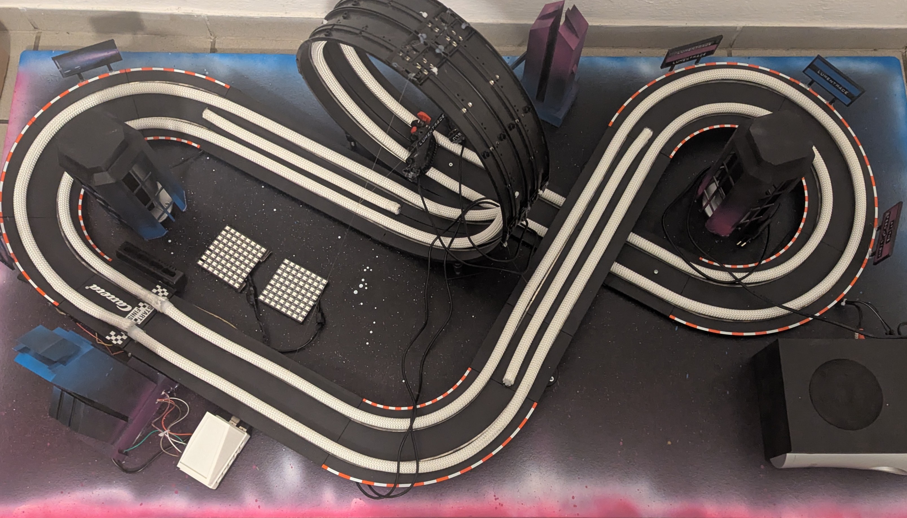
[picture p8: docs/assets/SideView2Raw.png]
    
    \caption{Full physical design of the LumenTrace system in a properly lighted environment.}
    \label{fig:physical-design}
\end{figure}

\section{Software Implementation and Game Mechanics}
\label{sec:software-implementation-and-game-mechanics}

This section describes the modular software architecture of the core application and the physics-based game mechanics it implements.

\subsection{Software Architecture}
\label{subsec:software-architecture}

The core application on the Raspberry~Pi~4 follows an object-oriented design and is decomposed into loosely coupled Python packages, each with a well-defined responsibility, as illustrated in~\Cref{fig:game-engine}. 
The \texttt{Game} package holds the core game logic, comprising vehicle physics, track management, and players. 
The \texttt{Controller} package translates player controller input into game state changes, while the \texttt{Display} package manages the LED effects and visual feedback. 
The \texttt{Sound} package provides the real-time, threaded audio mixer, and the \texttt{Logger} package centralizes debugging output to log files and MQTT~\cite{mqtt:2026mqtt,light:2026paho}. Finally, the \texttt{Simulation} package enables testing and visualization of the game mechanics without physical hardware. This separation of concerns keeps the system modular, maintainable, and straightforward for further extensions.

Python was chosen as the implementation language to maximize development velocity, readability, and access to mature hardware, audio, and testing libraries within the given project timeframe, accepting the Global Interpreter Lock (GIL) as a known trade-off against lower-level alternatives such as C/C++. 

Because real-time audio and high-frequency physics impose strict timing guarantees, the application is partitioned into independent threads to mitigate contention on the GIL~\cite{eggen:2019thread}; where thread-level parallelism proved insufficient, the audio path is further decoupled behind an asynchronous command queue rather than migrated to multiprocessing, keeping the shared game state simple and lock-free across subsystems. The physics loop runs at \SI{50}{\hertz}, the LED display pipeline at \SI{33}{\hertz}, and controller input polling at \SI{50}{\hertz}. 

The latency-critical physics thread is strictly separated from the peripheral driver calls of the controller and display subsystems, and the audio interface is further isolated behind an asynchronous command queue~\cite{tsigas:2001simple}, as detailed in~\Cref{subsec:real-time-audio-mixer}.

\begin{figure*}[tb]
    \centering
    
    \caption{Object-oriented software architecture of the LumenTrace core application, showing the modular package design.}
    \label{fig:game-engine}
\end{figure*}

\subsection{Controller Inputs and Speed Calculation}
\label{subsec:controller-inputs-and-speed-calculation}

Each \SI{20}{\milli\second}, the raw analog throttle value forwardPress reported by the Pico is mapped to a vehicle acceleration through linear interpolation~\cite{zheng:2018feature}, scaling the input range $[42000, 65536]$ onto the output range $[0, 100]$ of the acceleration \(a\):
\begin{equation}
    a(\text{forwardPress}) = \frac{\text{forwardPress} - 42000}{65536 - 42000} \cdot 100.
\end{equation}
The speed \(v\) is then integrated per tick as 
\begin{equation}
    v \mathrel{+}= a \cdot a_\text{mult}
\end{equation}
and clamped to the range \([-v_\text{max}, +v_\text{max}]\) to prevent unstable values at high update rates, where \(a_\text{mult}\) is a configurable acceleration multiplier, and \(v_\text{max}\) is the maximum speed limit for both driving directions.
To emulate realistic driving behavior, an adjustable friction coefficient~\cite{kane:2022tire} continuously dampens the current speed 
\begin{equation}
    v \mathrel{*}= (1 - \text{friction}).
\end{equation}

\subsection{Physics}
\label{subsec:physics}
% TODO: This could be written clearer for better understanding.

LumenTrace models several physics-based mechanics that emulate the behavior of classic slot cars~\cite{skaar:2025slot}. 
The vehicle position is derived from speed using the active game-tick interval. When the position exceeds the length of the full track lane, the \textit{lap counter} is incremented, and the position wraps around to zero. 

\textit{Lane changing} is realized through a temporary bidirectional center lane introduced by intersection modules. A change is only permitted when the driving profile of the current line allows it, but never within the final \texttt{laneChangeWindow} units before a module ends. A vehicle first switches from an outer lane to the middle lane and, after travelling at least one \texttt{laneChangeWindow}, may manually merge onto the target outer lane; otherwise the vehicle merges automatically before the module ends. During a switch, relative progress within the module is preserved by proportional conversion, where the target position equals the source progress ratio scaled by the target line length, keeping vehicles visually and physically aligned across lanes of differing lengths or radii.

\textit{Falling} is triggered immediately when a vehicle's speed or acceleration violates the driving profile of the active line, whose constraints are subdivided across curve and looping segments so that difficulty scales smoothly rather than abruptly at module entry. \textit{Collision detection} is evaluated per lane using a distance metric: if two vehicles come within a configured crash distance, the leading vehicle loses control and falls while the trailing vehicle continues unharmed, simulating a rear-quarter impact that preserves playability.

After a crash, a multi-stage \textit{respawn} procedure grants a collision-free placement with enough track to rebuild momentum for a possible looping in following modules. Fallen vehicles become inactive for a fixed number of respawn ticks and are ignored by the race. On respawn from a position inside a looping, a step back by one module is performed to avoid an immediate consecutive crash; the vehicle then attempts position zero on its preferred lane, falling back to other unoccupied lanes and, if necessary, to the track start. If no lane is available, the vehicle stays inactive and retries on the next tick until a position is free. Speed, acceleration, and the lane-change state are reset.

\subsection{Deployment}
\label{subsec:deployment}

For reproducible and hardware-independent operation, the LumenTrace application is packaged as a Docker container~\cite{merkel:2014docker} on the Raspberry~Pi~4. Running in privileged mode, the container bundles all system-level dependencies and grants the direct hardware access required for GPIO, LED, UART, and audio peripherals~\cite{croston:2022raspberry}, ensuring consistent behavior across deployments. Privileged mode is a deliberate security trade-off: it effectively disables container isolation and grants the container full access to host devices, which is acceptable for this self-contained, single-purpose appliance on a dedicated, non-networked device, but would need to be replaced by fine-grained device and capability mappings (e.g., explicit \texttt{--device} and \texttt{--cap-add} rules) in any multi-tenant or network-exposed deployment. A systemd unit binds the container to the host lifecycle, starting it automatically on boot and restarting it on failure, which satisfies the cold-boot and reliability requirements from~\Cref{subsec:system-requirements}.

\subsection{Simulation and Testing}
\label{subsec:simulation-and-testing}

To validate the game logic without physical hardware, LumenTrace ships a text-based simulation runner that renders the full game state live in the terminal, including player and vehicle telemetry and an ASCII lane visualization. It is complemented by a \texttt{pytest}-based unit test suite~\cite{krekel:2026pytest} covering the core game rules, controller inputs and output devices. Together, they satisfy the maintainability requirement of independent, hardwareless testability from~\Cref{subsec:system-requirements}.

\section{Multimedia Subsystems: LED and Audio Control}
\label{sec:multimedia-subsystems}

This section covers the two multimedia subsystems of LumenTrace: the priority-based LED rendering pipeline and the real-time stereo audio mixer, together with the hardware constraints that shaped their design.

\subsection{LED Rendering}
\label{subsec:led-rendering}

Driving the two round-counter matrices together with the two track strips initially required four independent \texttt{PixelStrip} objects of the \texttt{rpi\_ws281x} library on separate control lines (GPIO~10/SPI, GPIO~21/PCM, and GPIO~18/19/PWM). This approach failed because the underlying C driver~\cite{garff:2023rpi} cannot mix PWM, SPI, and PCM peripherals concurrently within a single process, is hardware-capped at two active channels, and produced DMA register collisions and memory-mapping failures when initializing multiple strips on the same DMA channel.

The bottleneck was resolved by physically daisy-chaining all LED components onto the two PWM channels only. Along each of the two channels, the signal from the Pi~4's GPIO first drives the round-counter matrix, then the main lane strip, and finally the additional intersection strip, with the connecting wires hidden beneath the track, as depicted in~\Cref{fig:hardware-setup}.

A display manager translates the game state into visual output on the track LED strips by composing several layers from low to high priority, so that higher-priority effects override lower ones. The hierarchy is applied in the following order:

\begin{enumerate}
    \item \textit{Track module base:} faint purple main lanes.
    \item \textit{Intersection module:} lanes on intersection modules with a light pink overlay.
    \item \textit{Intersection animation:} stronger pink overlay for indicating a possible lane change.
    \item \textit{Start line:} starting position with a white overlay.
    \item \textit{Round advance:} blinking starting position on lap completion.
    \item \textit{Inactive vehicles:} respawning vehicles displayed as dimmed gray.
    \item \textit{Active vehicle:} custom vehicle color with a speed-dependent color interpolation as speed warning~\cite{meschtscherjakov:2015chaselight}.
    \item \textit{Front lights:} white headlights, disabled by default.
    \item \textit{Rear lights:} red brake lights when no throttle is applied.
\end{enumerate}

To decouple this logic from the constrained hardware, the display layer builds on a virtual led abstraction that maps predefined segments of a physical strip onto logical lanes. This lets the display manager address the lap counter, main lane, and overtaking lane independently while hiding the physical daisy-chain and the two-channel limitation from the game logic. At each tick, the display manager writes RGB tuples into per-lane virtual buffers, and renders them onto the physical \texttt{PixelStrip} objects of the \texttt{rpi\_ws281x} library.

\subsection{Real-Time Audio Mixer}
\label{subsec:real-time-audio-mixer}

Audio in LumenTrace is mixed live and played back in stereo so that the soundscape reflects the race state at every moment~\cite{gardenfors:2003designing,gan:2019self}. 
A low-level sound manager combines sounds through a single output stream, controlling per-sound volume, dynamic pitch, and stereo panning independently~\cite{geier:2024sounddevice,bechtold:2026soundfile,harris:2020array}. Each vehicle owns a continuous engine sound whose pitch and loudness follow its speed, gains an additional layer while accelerating, and pans between the speakers according to the current track module's defined stereo ratio, complemented by positional one-shot effects, e.g., for the start sequence, laps, lane changes, crashes, and warnings~\cite{pixabay:2026pixabay}.

\textit{Problem:} initially, routing audio through the Pi's AUX jack produced significant background noise, which was resolved by switching to a USB audio interface. Moreover, executing the Python audio callbacks synchronously alongside high-frequency game ticks, rendering, and hardware polling caused GIL starvation and lock contention that manifested as severe sound stuttering after just a few seconds running the game. 
\textit{Solution:} the audio interface is isolated behind a thread-safe asynchronous command queue~\cite{tsigas:2001simple,eggen:2019thread}. A non-blocking sound manager proxy enqueues sound commands as fire-and-forget entries without ever blocking the caller, and a dedicated worker thread applies them to the underlying mixer. Together with minimal \SI{1}{\milli\second} sleep intervals in the display loop that prevent audio-thread starvation, this stabilized the output under concurrent workloads.

% TODO FOR PUBLICATION: Remove project management!
\section{Project Management}
\label{sec:project-management}

The LumenTrace project was executed by a three-person team, with each member contributing to different aspects of the project. 
The lead developers for each component are indicated in~\Cref{tab:task_distribution}, while a reviewer was assigned to each task to ensure hardware and software quality. 

The development of LumenTrace followed an incremental path, prioritizing a basic architecture and core functionality before implementing additional features and working on enhancements. 
The project was structured into four distinct milestones to manage dependencies and verify integration at each phase.

\begin{itemize}
    \item \textit{Milestone 1: Proof of Concept (POC):}
          Establishment of the physical Carrera GO!!!~\cite{carrera:2026carrera} track, development of Raspberry Pi Pico firmware using MicroPython, implementation of analog controller input reading, establishment of UART serial communication, and design of the JSON-based data serialization and parsing.

    \item \textit{Milestone 2: Base Game Implementation:}
          Software architecture with modular packages, core physics engine with acceleration, friction, and speed clamping, vehicle lane management and position tracking, collision detection via distance metrics, multithreaded game loop architecture, LED strip control, display rendering pipeline with priority-based layer system, modular track design with individual driving profiles, settings system, unit testing framework, and centralized logging via file and MQTT interfaces.

    \item \textit{Milestone 3: Enhancements and Feature Expansion:}
          Advanced physics for lane changes, respawn system, intersection modules, virtual LED strip abstraction for hardware constraint resolution, round counters, vehicle lighting effects including headlights, rear brake lights, and identification lights, real-time vectorized stereo audio mixer with volume and stereo panning controls, threaded sound manager, per-vehicle engine sounds with speed-responsive pitch, event-driven sound effects, Docker containerization, 3D-printed controller enclosures and component styling, and performance optimization to prevent thread starvation.

    \item \textit{Milestone 4: Documentation and Finalization:}
          Comprehensive technical report with architecture diagrams and system analysis, usage guides, technical report documentation, and project preparation for submission.
\end{itemize}

The division of responsibilities between the three team members is outlined in~\Cref{tab:task_distribution}. In general, Simon Völkl focused on the software implementation, Erik Dombrowsky concentrated on the hardware wiring and physical setup, while Simon Frey contributed mainly to the 3D printing and styling of the components. 

\begin{table*}[htb]
    \centering
    \caption{Task Distribution Matrix}
    \label{tab:task_distribution}
    \footnotesize
    \setlength{\tabcolsep}{4pt}
    \begin{tabularx}{0.68\linewidth}{p{2.5cm} p{4.5cm} c c c}
        \toprule
        \textbf{Milestone} & \textbf{Task} & \textbf{S. Völkl} & \textbf{E. Dombrowsky} & \textbf{S. Frey} \\
        \midrule
        \multirow{5}{2.5cm}{\textbf{M1: POC}}
            & Physical Track Setup & Lead & Lead & - \\
            & Controller Modification & Review & Lead & - \\
            & Pico Setup & Review & Lead & - \\
            & JSON Schema Serialization & Lead & Lead & - \\
            & JSON Schema Parsing & Lead & Review & - \\
            & Microcontroller Wiring with UART & Review & Lead & - \\
        \midrule
        \multirow{11}{2.5cm}{\textbf{M2: Base Game}}
            & Software Architecture & Lead & Review & - \\
            & Logging & Lead & Review & - \\
            & Unit Testing & Lead & - & - \\
            & Console Simulation & Lead & - & - \\
            & Physics Engine & Lead & Review & - \\
            & Track Modules with Driving Profiles & Lead & Lead & Lead \\
            & Settings System & Lead & Review & - \\
            & Vehicle Lane Management & Lead & Review & Review \\
            & Collision Detection & Lead & Review & - \\
            & Multithreading & Lead & Review & - \\
            & LED Strip Control & Lead & Lead & Lead \\
        \midrule
        \multirow{12}{2.5cm}{\textbf{M3: Enhancements}}
            & Advanced Physics & Lead & Review & Review \\
            & Respawn System & Lead & Review & Review \\
            & Physical Intersection Modules & Review & Lead & - \\
            & Virtual LED Strips & Lead & Review & - \\
            & Round Counter Wiring & Review & Lead & Lead \\
            & Round Counter Logic & Lead & Review & - \\
            & Vehicle Lighting Effects & Lead & Review & Review \\
            & Sound Samples & Lead & Lead & Lead \\
            & Sound Engineering & Lead & Lead & - \\
            & Docker Containerization & Lead & - & - \\
            & 3D Printing/Styling & Review & Lead & Lead \\
        \midrule
        \multirow{2}{2.5cm}{\textbf{M4: Documentation}}
            & Technical Report & Lead & Review & Review \\
            & Presentation Preparation & Lead & Lead & Review \\
            & Usage Guides & Lead & - & - \\
        \bottomrule
    \end{tabularx}
\end{table*}

\section{Evaluation}
\label{sec:evaluation}

This section evaluates LumenTrace against its non-functional requirements from~\Cref{subsec:system-requirements}, assessing real-time performance, user experience, cost, and remaining limitations.

\subsection{Performance Analysis}
\label{subsec:performance-analysis}

The LumenTrace system achieves real-time performance across all critical subsystems, meeting or exceeding the specified non-functional requirements.

The system operates three independent processing threads at target frequencies of \SI{50}{\hertz} for the game engine physics, \SI{33}{\hertz} for the LED display pipeline, and \SI{50}{\hertz} for controller input polling. These frequencies are configured setpoints rather than instrumented measurements; they were selected to exceed the human perception threshold of circa \SI{24}{\hertz}~\cite{chen:2007review,pazhoohi:2021effect} and produced smooth, flicker-free visual output perceived as continuous motion during operation. A rigorous quantitative characterization of the frequencies actually sustained under load, including their timing jitter, remains future work.

Controller inputs demonstrate minimal end-to-end latency from physical button press through UART transmission, game logic processing, and LED display update. The system responds in \SI{70}{\milli\second} to \SI{100}{\milli\second} to throttle and lane-change commands with no perceptible delay; these figures were obtained by counting frames during a live run rather than through instrumented profiling. This responsiveness is maintained even during occasional UART transmission failures, which were estimated at approximately \SI{5}{\percent} of packets by counting dropped or unreadable packets over a live run, as the system prioritizes the most recent controller state rather than queuing stale data. A precise, instrumented measurement of the end-to-end latency and packet-loss rate is planned for future evaluation.

The optional file and MQTT logging subsystems introduce measurable performance overhead due to I/O blocking and possible network latencies. Logging should remain disabled in production environments, else performance degradation and occasional \SI{50}{\milli\second}--\SI{200}{\milli\second} lag spikes during log message transmission can occur; these spikes were observed by systematically measuring execution times during live runs. Deferred asynchronous logging could mitigate this overhead in future iterations.

\subsection{User Experience and Feedback}
\label{subsec:user-experience-and-feedback}

The feedback reported here is anecdotal rather than the result of a controlled user study. It was gathered informally from the three developers and a small, unstructured group of casual observers who played the game during development, without a defined task protocol, participant sampling, or standardized questionnaire. Under these conditions, the combination of immersive LED lighting effects, spatially-positioned audio, and responsive physics was consistently perceived as compelling and engaging. The retro-futuristic aesthetic, with its purple and blue color scheme and sci-fi-styled 3D-printed components, resonated well with both casual observers and competitive players. Iterative refinements to speed limit transitions and audio volume levels were reported to improve overall player satisfaction and reduce jarring gameplay moments. A formal usability evaluation with a defined participant sample, structured tasks, and validated questionnaires (e.g., the System Usability Scale) is required to substantiate these observations and to operationalize the usability requirement from~\Cref{subsec:system-requirements}; conducting it is left to future work. Although the system currently relies on Carrera GO!!!~\cite{carrera:2026carrera} track modules, custom modules are planned for future development to enhance flexibility and independence from proprietary track systems. For museum exhibitions or trade show presentations, further concealment of cables is recommended to ensure safety and prevent potential malfunctions like loose connections.

\subsection{Cost Analysis}
\label{subsec:cost-analysis}

\Cref{tab:cost_analysis} summarizes the approximate hardware cost of the LumenTrace prototype per component. A total cost of \textbf{310\,\texteuro} was calculated, indicating a relatively high-cost prototype. Further cost reductions could be achieved by switching to lower-cost LED strips, creating custom track modules, or sourcing components in bulk.   

\begin{table}[htb]
    \centering
    \caption{Hardware Cost Overview}
    \label{tab:cost_analysis}
    \footnotesize
    \begin{tabular}{l r l r}
        \toprule
        \textbf{Component}                       & \textbf{Unit Cost}          & \textbf{Quantity} & \textbf{Total Cost} \\
        \midrule
        Raspberry Pi 4 (Core Host)               & 40\,\texteuro            & 1 & 40\,\texteuro \\
        Raspberry Pi Pico (Input MCU)            & 5\,\texteuro             & 1 & 5\,\texteuro \\
        32GB Micro-SD card                       & 16\,\texteuro            & 1 & 16\,\texteuro \\
        USB sound card                           & 8\,\texteuro             & 1 & 8\,\texteuro \\
        WS2812B diffusing LED strip              & 57\,\texteuro            & 2 & 114\,\texteuro \\
        WS2812B 8x8 LED matrix                   & 4\,\texteuro             & 2 & 8\,\texteuro \\
        Stereo speakers (and subwoofer)          & 25\,\texteuro            & 1 & 25\,\texteuro \\
        Carrera GO!!! track module               & 1\,\texteuro             & 20 & 20\,\texteuro \\
        Carrera GO!!! controller                 & 10\,\texteuro            & 2 & 20\,\texteuro \\
        Wooden base plate                        & 10\,\texteuro            & 1 & 10\,\texteuro \\
        3D-printing PLA filament                 & 6\,\texteuro             & 1 & 6\,\texteuro \\
        Wiring and mounting equipment            & 2\,\texteuro             & 3 & 6\,\texteuro \\
        Paint (spray and brush)                  & 8\,\texteuro             & 4 & 32\,\texteuro \\
        \midrule
        \textbf{Total}                           &                          &   & \textbf{310\,\texteuro}    \\
        \bottomrule
    \end{tabular}
\end{table}

\subsection{Challenges and Limitations}
\label{subsec:challenges-and-limitations}

% TODO: Further limitations?
Beyond the display, audio, and logging bottlenecks addressed earlier, a few conceptual limitations remain. 
The vertical height of the diffusing LED channel ruled out physically intersecting overtaking lanes, which is why overtaking relies on a temporary bidirectional center lane rather than true crossing paths. 
The abrupt transitions between the speed limits of adjacent track modules can still provoke unavoidable crashes when a vehicle enters a stricter profile at excessive speed, a shortcoming, which a smoothed limit interpolation could mitigate. 
The system is further bound to the two physical LED channels imposed by the \texttt{rpi\_ws281x} driver~\cite{garff:2023rpi}, which the daisy-chained virtual LED design accommodates but does not eliminate, capping the number of independently wired strips.
These constraints do not affect core gameplay but define the current envelope of the prototype.
Enabling others to participate on the project, as in the OLR project~\cite{openledrace:2025project}, would require a more cost-effective and modular system design.

\section{Conclusion and Future Work}
\label{sec:conclusion-and-future-work}

LumenTrace demonstrates that the tactile appeal of classic slot car racing can be reproduced without moving parts by representing each vehicle as a light on an addressable LED strip. On a distributed Raspberry~Pi Pico and Raspberry~Pi~4 architecture~\cite{magpi:2024raspberry}, the system unifies a real-time physics engine featuring acceleration, friction, collision detection, and crash recovery, a priority-based LED rendering pipeline with adaptive, state-driven effects~\cite{meschtscherjakov:2015chaselight}, and a vectorized, thread-isolated stereo audio mixer that positions engine and event sounds in space. Packaged for reproducible deployment via Docker~\cite{merkel:2014docker} and validated through a hardwareless simulation interface and unit tests, the prototype meets its performance targets and delivers a smooth, immersive, and low-latency racing experience that closes the gap between commercial slot car systems and minimalist LED racers.

Besides cost reduction and playability enhancements, future work on the system should include a rigorous empirical evaluation, comprising instrumented measurements of the sustained thread frequencies, end-to-end latency, and packet-loss rate under load, as well as a formal usability study with a defined participant sample and standardized questionnaires. 
Beyond evaluation, additional game features are envisioned. 
Physical controllers with vibration modules would add haptic feedback, while the collected MQTT telemetry could be visualized on a companion web or mobile dashboard~\cite{voelkl:2026sensiq,voelkl:2026bitebound}. 
Gameplay could be enriched with special abilities beyond the overtaking lane, such as nitro boosts or projectiles, collectible coins, and additional game modes with environmental effects like storms or rain~\cite{scalextric:2026arc}. On the technical side, AI opponents trained with reinforcement learning, smoothed speed-limit transitions to prevent abrupt collisions, further ambient enhancements through additional 3D-printed components, and custom, magnetically connectable track modules~\cite{anki:2026overdrive} would extend both playability and independence from proprietary track systems.

% --- References ---
% The \balance command ensures that the two columns on the last
% page end cleanly at the same height. Uncomment as soon as the text is finished!
\balance 
\bibliographystyle{IEEEtran}
\bibliography{references}

\end{document}

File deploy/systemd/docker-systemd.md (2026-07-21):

# Docker and Systemd Integration Architecture

LumenTrace uses Docker [merkel:2014docker] for containerized deployment and systemd for service management on the Raspberry Pi 4 [magpi:2024raspberry], ensuring consistent runtime environments and automated lifecycle control.

## Docker Architecture

**Container Image**: Built from Python 3.14 slim with native C extensions (GPIO/LED libraries) and ALSA audio support. Dependencies are cached independently to accelerate rebuilds.

**Runtime Configuration**:

- Runs in privileged mode with access to `/dev` hierarchy for GPIO, SPI, UART, and PCM control
- Volume mounts: `/dev:/dev`, `/dev/snd:/dev/snd`, `/run/dbus:/run/dbus` (read-only)
- Cgroup device rules restrict access to ALSA (device 116) and USB devices (device 189)
- Environment: `ALSA_CARD=0` (USB sound card), optional PulseAudio socket

**Image Optimization**: `.dockerignore` excludes documentation, logs, archived code, tests, and development modules while preserving ``assets/`` (sound files)

## Systemd Service Integration

The `lumentrace.service` unit file manages the Docker container as a system service:

- **Type**: `oneshot` — executes `docker compose up -d` on start and `docker compose down` on stop
- **Dependencies**:
  - `Requires=docker.service` (hard dependency)
  - `After=docker.service network-online.target` (ordering)
- **Working Directory**: `/home/lumentrace/Documents/repos/LumenTrace`
- **Boot Integration**: `WantedBy=multi-user.target` enables auto-start; `RemainAfterExit=yes` maintains active state
- **Restart Policy**: Configured in docker-compose.yaml as `restart: unless-stopped`

## Hardware Access and Device Binding

The container accesses Raspberry Pi hardware through Linux device files:

- **GPIO**: GPIO 18/19 (LED control), GPIO 10 (SPI), GPIO 21 (PCM) via `/dev/mem` and `/dev/gpiomem`
- **Serial**: UART to Pico controller via `/dev/ttyAMA0` or `/dev/ttyUSB0`
- **Audio**: ALSA through `/dev/snd/*` devices for USB sound card output
- **Privilege**: Container runs as root to maintain necessary device access permissions

## Deployment Characteristics

**Service Model**: Single-service, stateless deployment with one instance per Raspberry Pi. Container restarts are automatic via Docker's restart policy; systemd monitors the docker-compose process for overall health.

**Resource Management**: Memory limits are disabled due to Raspberry Pi 4 cgroup constraints. Device access is controlled through fine-grained cgroup rules. The container shares the host network namespace for UART and GPIO control.

**Resilience**: Auto-restart on failure, boot-time dependency ordering, graceful shutdown via `ExecStop`, and state isolation through fresh container restarts prevent state pollution.

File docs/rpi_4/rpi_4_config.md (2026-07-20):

# Raspberry Pi 4 Config

## OS

- Raspberry Pi OS (64-bit): A port of Debian Trixie with Raspberry Pi Desktop (Recommended).
- Micro-SD: 32 GB.
- Country/Capital: Germany/Berlin
- Timezone: Europe/Berlin
- Keyboard Layout: de
- WLAN: Use "BND-Spionage 5" (SimonV)
- Enable SSH: Yes, with password (`lumentrace`)
- Raspberry Pi Connect: Yes, using a Raspberry Pi account. See private message for login credentials.

## Connection (SSH)

- Hostname: `lumentrace`
- Username: `lumentrace`
- Password: `lumentrace`
- ssh lumentrace@lumentrace

## Code Execution

- Navigate to folder: `cd /home/lumentrace/Documents/repos/LumenTrace`
- Create virtual environment: `python3 -m venv .venv`
- Activate virtual environment: `source .venv/bin/activate`
- Install pip packages: `pip install -r ./src/rpi_4/requirements.txt`
- Verify package list: `pip list`
- Run application: `sudo .venv/bin/python -m src.rpi_4.main` (Crucial for physical memory access required by the `rpi_ws281x` library)

```shell
source .venv/bin/activate
sudo .venv/bin/python -m src.rpi_4.main
```

## Hardware Preparation (SPI & PCM)

The round counters use **GPIO 10 (SPI)** and **GPIO 21 (PCM)**. You must configure your Raspberry Pi host to enable these modules and prevent onboard audio drivers from blocking them.

### 1. Enable SPI (Player 1 Round Counter)

Run `sudo raspi-config` on the host, go to **Interface Options** -> **SPI**, select **Yes** to enable it, and reboot.
Alternatively, verify that the following parameter is present in `/boot/firmware/config.txt`:

```ini
dtparam=spi=on
```

### 2. Disable Onboard Audio (Player 2 Round Counter / PCM)

Onboard audio drives analog jack/PWM sounds via PCM, which conflicts with GPIO 21 [3]. Open `/boot/firmware/config.txt` on the host:

```bash
sudo nano /boot/firmware/config.txt
```

Locate `dtparam=audio=on` and change it to `off`:

```ini
dtparam=audio=off
```

Reboot the Raspberry Pi to apply changes.

---

## Installations

### Sound with USB Sound Card

Disabling onboard audio means your USB Sound Card will shift to default index **0** instead of **3**.

```bash
# List all audio devices to verify that USB Audio is now Card 0
aplay -l

# Set your USB sound card as the system default:
echo "defaults.pcm.card 0" | sudo tee -a /etc/asound.conf
echo "defaults.ctl.card 0" | sudo tee -a /etc/asound.conf

# Verify the changes
cat /etc/asound.conf

# Test audio output on Raspberry Pi (before Docker)
sudo speaker-test -c 2 -t sine -f 1000 -l 1 -D sysdefault:CARD=2
```

For instructions on how to install and run the application with **Docker**, please see:
[docs/rpi_4/rpi_4_docker.md](rpi_4_docker.md)

## Hardware Set

- Raspberry Pi 4 Model B 4GB RAM, with 4 mounted heatsinks, original packaging included
- Official USB-C Power Supply
- Two-part enclosure (black base, transparent top cover)
- Raspberry Pi HDMI D/Male to HDMI A/Male 1m cable
- Power supply to USB-C cable, 15.3W black, original packaging included
- Raspberry Pi Micro-SD card 16GB with SD adapter
- Manuals (2x)

From Makerspace:

- SanDisk Extreme 32GB V30 U3 A1 with adapter --> inserted in RPI 4

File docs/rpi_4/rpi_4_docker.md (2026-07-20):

# Docker on Raspberry Pi 4

This document describes how to use Docker to run LumenTrace on a Raspberry Pi 4. Docker provides a consistent, isolated environment and automatically handles system-level dependencies and privileged hardware access.

## Installation

To install Docker and Docker Compose on your Raspberry Pi:

```bash
sudo apt update && sudo apt upgrade -y
curl -fsSL https://get.docker.com -o get-docker.sh
sudo sh get-docker.sh
```

After installation, reboot the Raspberry Pi and verify the version:

```bash
docker --version
docker compose version
```

## Usage

Use the following commands to stop, remove, build, and start the Docker container. The `-d` flag runs the container in detached mode.

```bash
sudo docker compose -f docker-compose.yaml stop
sudo docker compose -f docker-compose.yaml down
sudo docker compose -f docker-compose.yaml build
sudo docker compose -f docker-compose.yaml up -d
```

## Autostart on Boot

To ensure LumenTrace starts automatically after a reboot, enable the Docker daemon and use the provided systemd service.

1. **Enable Docker daemon:**

    ```bash
    sudo systemctl enable docker
    sudo systemctl start docker
    ```

2. **Install and enable the systemd unit:**

    Ensure the container is built and started once (as described above), then run:

    ```bash
    sudo cp deploy/systemd/lumentrace.service /etc/systemd/system/lumentrace.service
    sudo systemctl daemon-reload
    sudo systemctl enable lumentrace.service
    sudo systemctl start lumentrace.service
    ```

3. **Verify status:**

    ```bash
    sudo systemctl status lumentrace.service
    sudo docker compose -f docker-compose.yaml ps
    ```

> [!IMPORTANT]
> If your repository path is not `/home/lumentrace/Documents/repos/LumenTrace`, update the `WorkingDirectory`, `ExecStart`, and `ExecStop` paths in `deploy/systemd/lumentrace.service` before copying the file.

## Audio Troubleshooting

If the game starts without sound:

1. **Check Logs:**

    ```bash
    sudo docker compose -f docker-compose.yaml logs lumentrace | grep -i "audio\|device"
    ```

2. **Verify Device Access:**

    ```bash
    # List audio devices inside the container
    sudo docker compose -f docker-compose.yaml exec -T lumentrace aplay -l

    # Test audio output (sine wave)
    sudo docker compose -f docker-compose.yaml exec -T lumentrace speaker-test -c 2 -t sine -f 1000 -l 1
    ```

3. **Fix "Playback open error: -524":**
    If audio device files cannot be accessed, restart the container to reapply device mount permissions:

    ```bash
    sudo docker compose -f docker-compose.yaml restart
    ```

4. **Rebuild from Scratch:**

    ```bash
    sudo docker compose -f docker-compose.yaml build --no-cache
    ```

For general system-level audio configuration (USB sound cards, etc.), see [docs/rpi_4/rpi_4_config.md](docs/rpi_4/rpi_4_config.md#sound-mit-usb-soundkarte).

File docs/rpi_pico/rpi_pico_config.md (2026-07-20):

# Raspberry Pi Pico Config

Run Thonny on Raspberry Pi 4, with a USB connection to the Raspberry Pi Pico (standard variant). In Thonny, select "MicroPython (Raspberry Pi Pico)" as the interpreter, then run the file `src/rpi_pico/pico_config.py` to configure the Raspberry Pi Pico. This will set up the necessary configurations for the Pico to communicate with the Raspberry Pi 4.

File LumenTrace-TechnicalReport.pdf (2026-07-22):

TECHNICAL REPORT FOR PHYSICAL COMPUTING LECTURE AT OTH AMBERG-WEIDEN, 07 2026 | 1

# LumenTrace: A Mechanics-Free LED Slot Car Racing Game with

# Real-Time Physics and Immersive Audiovisual Feedback

Simon Volkl ¨ , Erik Dombrowsky, and Simon Frey

Abstract—Classic slot car systems offer an engaging tactile racing experience, yet they remain bound to physical vehicles on mechanical rails and treat light and sound as secondary embellishments. Simultaneously, minimalist LED racers reduce gameplay to button pressing and omit realistic physics, spatial audio and advanced track features. LumenTrace aims to unite the physical realism and playability of slot cars with the mechanical simplicity and immersive, state-driven audiovisual feedback that individually addressable LEDs make possible. The system is built on a distributed Raspberry Pi Pico and Raspberry Pi 4 architecture. A real-time physics engine models acceleration, friction, collision detection, and crash recovery from throttle and button inputs transmitted over a high-speed UART link. A priority-based LED rendering pipeline displays adaptive, state-dependent track and vehicle effects, complemented by a stereo audio mixer. The system meets its real-time thread budgets and low-latency requirements, resulting in positive user feedback during playtests, though it lacks cost-effectiveness for open-source developers. LumenTrace closes the gap between commercial slot car systems and minimalist LED racers, while providing highly performant, maintainable and safe system architecture. Future work focuses on cost reduction, improved playability, and game extensions.

Index Terms—Distributed Embedded Systems, LED Racing Game, Microcontroller, Real-Time Physics Engine, Slot Car Racing, Spatial Audio, WS2812B

I. INTRODUCTION
S

LOT car racing has entertained enthusiasts for decades, but its classic form ties the experience to physical vehicles running on mechanical rails, where light and sound serve merely as peripheral embellishments. LumenTrace reimagines this concept as a mechanics-free racing simulator in which each vehicle is represented directly as a moving point of light on an individually addressable light-emitting diode (LED) strip. Built on a distributed architecture of a Raspberry Pi Pico and a Raspberry Pi 4 [1], the system couples a real-time physics engine with a priority-based LED rendering pipeline and a spatial audio mixer to deliver an immersive, state-driven racing experience without any moving mechanical parts. The complete source code and documentation are publicly available in the project’s GitHub repository [2].

A. Motivation
Classic slot car systems deliver an engaging tactile racing experience, but they remain bound to physical vehicles running

The authors are with the Department of Electrical Engineering, Media, and Computer Science, Ostbayerische Technische Hochschule Amberg-Weiden, 92224 Amberg, Germany (e-mail: s.voelkl2@oth-aw.de; e.dombrowsky@oth-aw.de; s.frey@oth-aw.de). The project is part of the Physical Computing Course at OTH Amberg-Weiden and is supervised by Prof. Dipl.-Des. Martin Frey and Prof. Dr.-Ing. Ulrich Schafer. ¨

on mechanical rails. In these systems, light and sound are treated as peripheral add-ons rather than as core gameplay elements: engine sounds are typically monotone and decoupled from the vehicle’s actual speed, and illuminated track sections merely blink in fixed patterns instead of responding to the race state [3]. Even highly digitalized products such as Carrera Digital 132 [4], Anki Overdrive [5] or Scalextric ARC PRO [6] retain physical cars and use audiovisual feedback only as a secondary layer.
LED-based racing games take the opposite approach and represent each vehicle directly as a moving light on an individually addressable strip [7], [8]. This removes all moving parts, yet existing projects stay deliberately minimalistic: gameplay is reduced to button mashing, and features such as a realistic physics model, spatially positioned audio, bidirectional lane changing, collision recovery, and modular track profiles are absent. As detailed in Section II, no existing system combines the physical realism and playability of slot cars with the mechanical simplicity and immersive, state-driven audiovisual feedback that addressable LEDs make possible. LumenTrace is motivated by closing precisely this gap.
B. Problem Statement
The central problem addressed by LumenTrace is the absence of a racing system that simultaneously provides the realistic physics and competitive playability of commercial slot cars and the mechanical simplicity and expressive, state-driven audiovisual feedback of addressable LED strips. Commercial slot car systems retain physical vehicles on mechanical rails and relegate light and sound to fixed, speed-decoupled embellishments, whereas existing LED racers reduce gameplay to acceleration pulses and omit a realistic physics model, spatial audio, bidirectional lane changing, collision recovery, and modular track profiles. LumenTrace therefore sets out to design and implement a mechanics-free LED slot car simulator that unifies these two design spaces on a low-latency, maintainable, and safe distributed embedded architecture.
C. Contributions
LumenTrace contributes a mechanics-free LED slot car simulator that unifies the strengths of both worlds on a distributed Raspberry Pi Pico and Raspberry Pi 4 architecture [1]. At its core is a real-time physics engine that models acceleration, friction, speed clamping, collision detection, and crash recovery, driven by analog throttle and digital button inputs transmitted over a high-speed Universal Asynchronous Receiver/Transmitter (UART) link [9]. On top of this, a priority-based LED rendering pipeline paints the track and

TECHNICAL REPORT FOR PHYSICAL COMPUTING LECTURE AT OTH AMBERG-WEIDEN, 07 2026 | 2


Fig. 1. LumenTrace: at the speed of light. Full-scale setup of the LED racing game showing the track, vehicles, controllers, and audiovisual system.

vehicles with layered, state-dependent effects, including adaptive vehicle colors, headlights, and brake lights that give
the driver ambient feedback about speed [10], together with round counters realized through physically chained WS2812B matrices [11]. A vectorized, thread-isolated stereo audio mixer adds per-vehicle engine sounds whose pitch and stereo position follow the car’s speed and track position, complemented by positional event sounds. Playability is extended beyond prior LED racers through a temporary bidirectional overtaking lane and modular track modules with individual driving profiles. Finally, the system is packaged for reproducible deployment via Docker [12] and ships with a hardwareless simulation interface for development and testing without physical hardware.
D. Document Outline
The remainder of this report is organized as follows. Section II surveys commercial slot car systems and open-source LED racing projects. Section III specifies the functional and non-functional requirements and derives the distributed system architecture. Section IV details the microcontroller setup, the UART communication interface, and the physical design. Section V describes the software architecture and the physics-based game mechanics, while Section VI covers the priority-based LED rendering pipeline and the real-time audio mixer. Section VII reports on the project management and task distribution, Section VIII evaluates the resulting system, and Section IX concludes and outlines future work.

II. RELATED WORK
LumenTrace sits at the intersection of two established domains: commercial slot car racing systems and open-source LED strip games. This section surveys both landscapes to contextualize the design decisions presented in the remainder of this report.
A. Existing Slot Car Systems
Commercial systems have steadily added electronics while keeping physical cars on mechanical rails. Carrera Hybrid [13] pushes toward a more digitalized and realistic racing simulation with collisions, overtaking, and modular track assembly. Carrera Digital 132 [4] offers button-triggered lane changes, lap counters, start lights, driver displays, and wireless controllers, but the vehicles remain fully physical rather than simulated. Scalextric ARC PRO [6] adds an app-based interface with pit stops, lap-time tracking, weather conditions, and multiple race modes, while reducing the controller to a brake and a lane-change button. Anki Overdrive [5] abandons fixed slots in favor of app-controlled autonomous cars on magnetically connectable, modular track segments.
Across these systems, light and sound serve as secondary embellishments rather than integral gameplay elements. Many hobbyist Carrera GO!!! [14] layouts add track-side lighting such as traffic signals, small LCD readouts, or vehicle headand tail-lights, yet these effects are neither integrated into the race flow nor used to illuminate the lanes themselves. The Carrera GO!!! Light and Sound Looping Set [3] is representative: roughly 16 LEDs on each side of the looping blink red and white as a car passes, accompanied by a fixed engine sound effect. Both the blinking and the sound are static and remain decoupled from the actual vehicle speed. Even in the most digital products, audio is dominated by the mechanical friction noise of the miniature cars and is limited to short indicator cues at the start and on completing a lap.
B. LED-Based Projects and Racing Games
A parallel line of work explores addressable LED strips as minimalist, one-dimensional game displays driven by simple controllers. Line Wobbler [15] is an award-winning one-dimensional dungeon crawler whose custom controller consists

TECHNICAL REPORT FOR PHYSICAL COMPUTING LECTURE AT OTH AMBERG-WEIDEN, 07 2026 | 3

of a spring and a circa 5 m LED strip; it has been widely
exhibited in museums and has inspired follow-up projects
such as the Arduino-based crawler TWANG [16]. These titles demonstrate the appeal of novel input mechanics and physical space, yet they remain single-player experiences without competitive racing elements.
The most directly related project is the open-source Open LED Race (OLR) developed since 2019 [8]. OLR simulates a slot car track on a WS2812/WS2813 strip, representing each player as a colored light that advances by one acceleration pulse per button press, and supports up to four cars with optional slopes and gravity, a pit lane, and an electric-car mode requiring recharging [7], [17]. The project has evolved through numerous community forks: extended gravity, sound, and lighting effects [18], a layout with 3D-printed track elements focussing on design [19], an added 16 × 16 LED matrix display [20], a TinyGo reimplementation [21], and wireless ESP-based remote controllers [22].
LumenTrace shares OLR’s foundational ingredients of controller input, addressable LED strips, and microcontrollerbased execution, but deliberately targets a different point in the design space. It omits OLR features such as gravity slopes, pit-lane recharging, and the electric-car mode, and instead introduces a realistic physics model, bidirectional lane changing, collision detection with crash recovery, priority-based immersive lighting, spatial audio, and modular track profiles. In doing so, LumenTrace bridges the realism and playability of commercial slot car systems with the flexibility and expressive audiovisual potential of LED-based games.

III. SYSTEM REQUIREMENTS AND ARCHITECTURE

This section defines the functional and non-functional requirements that guided the development of LumenTrace and derives the system architecture that satisfies them.

A. System Requirements

The system requirements define both functional capabilities and non-functional performance constraints that ensure LumenTrace meets user expectations and technical standards. Functional Requirements: The initial project scope centered on developing a mechanics-free digital slot car racing system with a real-time control system, individually addressable red, green, and blue (RGB) LED strips for track and vehicle visualization, basic sounds, and utilizing the Raspberry Pi Pico 2 W microcontroller with PIO. Additionally, emphasis on design and playability was laid out to ensure an engaging user experience.
Non-Functional Requirements: The system was designed to meet the following quality and performance attributes:
- Performance: The system must render at greater than 24 Hz for human-perceivable smoothness. Controller inputs must be processed with minimal latency (less than 100 ms end-to-end) to provide responsive, immediate feedback during gameplay.
- Scalability: The modular software architecture must support straightforward extension with new track modules, driving profiles, light and sound effects without requiring core system modifications.
- Safety: All electrical hazards must be mitigated through proper insulation and power management. Mechanical components must be designed to eliminate sharp edges and pinch points accessible to users.
- Reliability and Availability: The system must gracefully handle errors and automatically recover or restart. Cold boot initialization must complete within 120 s to minimize user wait time.
- Maintainability: The codebase must be well-documented with clear separation of concerns. Hardware and software components must be independently testable and replaceable without system-wide redesign. A simulation interface must be provided for development and testing without requiring physical hardware.
- Usability: The user interface must be intuitive and require minimal learning. Controller operation, track physics, and audiovisual feedback must be immediately comprehensible to new players. The game difficulty must be accessible to casual users while remaining engaging for experienced players.
B. High-Level Architecture
LumenTrace is built on a distributed two-tier architecture that splits the workload between an input-gathering microcontroller and a central core host [1], as depicted in Figure 2. The input controller captures the physical user commands and streams them over a serial connection to the main processing unit. The core host then executes the central application to resolve the game state and drive the output devices.
This separation of concerns offloads the latency-critical, high-frequency input sampling from the core host, allowing it to dedicate its computational resources to processing game state and real-time feedback without incurring polling overhead. Structuring the system into independent, well-defined subsystems also keeps it modular, maintainable, and scalable.

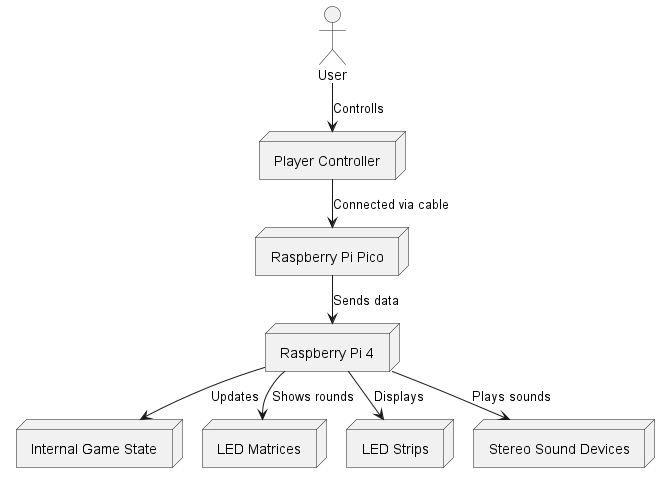
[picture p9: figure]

Fig. 2. High-level system architecture of LumenTrace, showing the distributed setup with the Raspberry Pi Pico as input microcontroller and the Raspberry Pi 4 as core host.

TECHNICAL REPORT FOR PHYSICAL COMPUTING LECTURE AT OTH AMBERG-WEIDEN, 07 2026 | 4

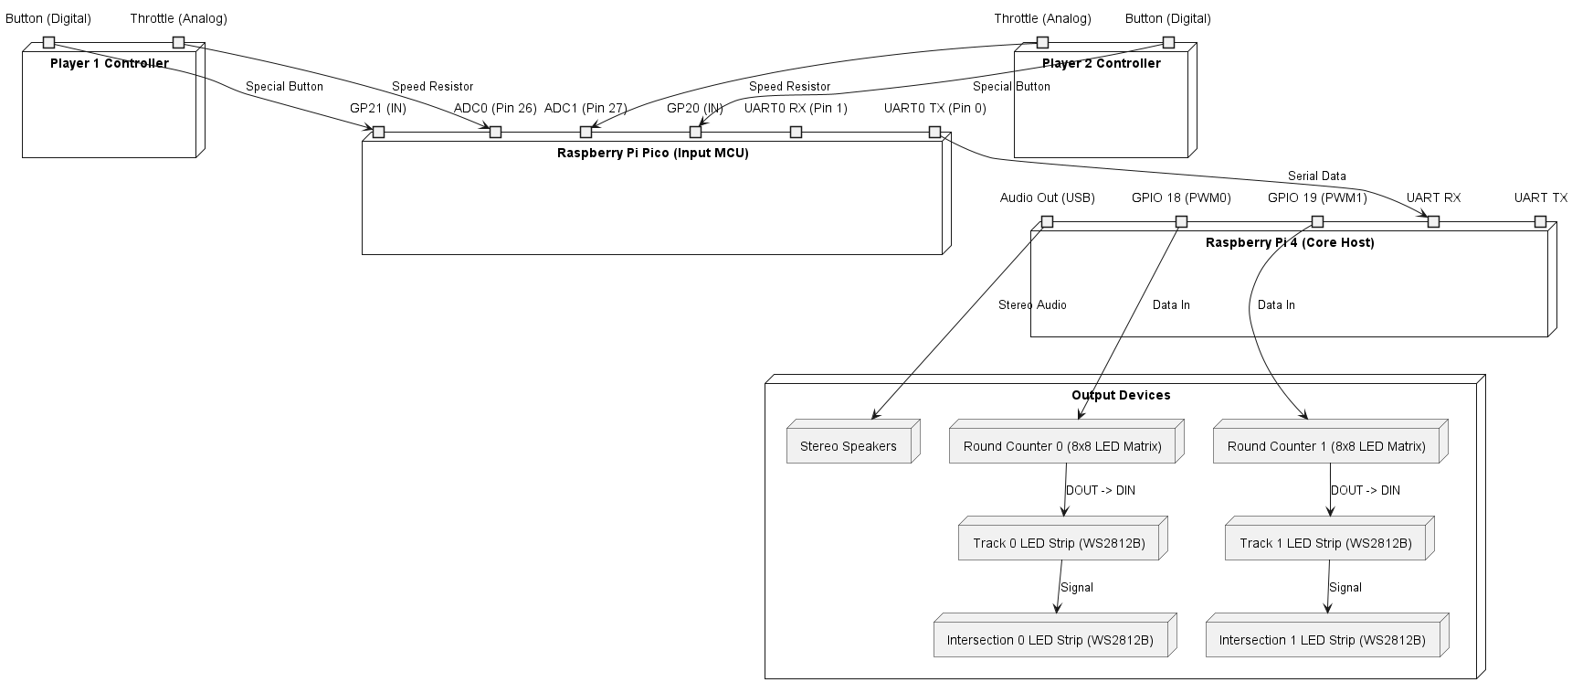
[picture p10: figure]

Fig. 3. Hardware setup of LumenTrace: The Raspberry Pi Pico handles controller inputs and transmits them to the Raspberry Pi 4, which drives the output devices.

IV. HARDWARE IMPLEMENTATION

This section describes the hardware realization of Lumen-Trace, covering the distinct roles of the two microcontrollers, the serial communication interface between them, and the physical construction of the track and controllers.

A. Microcontroller Setup

As illustrated in Figure 3, the specific hardware configuration establishes the low-level execution environments for both devices. The Raspberry Pi Pico acts as the dedicated input microcontroller running MicroPython firmware [23]. It permanently and latency-free samples the physical controllers, utilizing its internal 12-bit analog-to-digital converters (ADCs) channels to read the analog throttles and its General Purpose Input/Output (GPIO) pins to detect digital button presses. Conversely, the Raspberry Pi 4 functions as the core host, booting its operating system and the main Python application from a micro-SD card to enable fully autonomous physical startup. The Pi 4 processes the inputs transmitted by the Pico to maintain the internal game state and execute physics ticks. It translates this game state into audiovisual feedback by actuating the LED strips and matrices [11], and by driving the stereo audio mixer.

B. Communication Interface

The Pico and the Pi 4 communicate over a high-speed UART link [9], [24]. On every polling cycle, the Pico serializes the current state of all connected controllers into a compact JavaScript Object Notation (JSON) structure [25] and transmits it to the Pi 4. Delegating input acquisition and serialization to the Pico relieves the core host from polling overhead, so that it can consume the most recent controller state directly instead of sampling the hardware itself. As shown in Figure 4, each controller entry reports a unique controller_id, the raw analog throttle value adc_0, and the digital button state dig_0.

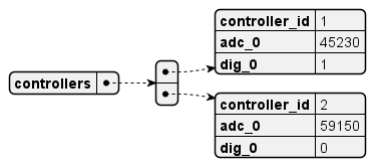
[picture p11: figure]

Fig. 4. Example of the JSON structure transmitted from the Pico to the Pi 4 over UART, containing the current state of two controllers.

At an update rate of 50 Hz, the protocol tolerates sporadic transmission losses: roughly every twentieth packet is dropped or unreadable, yet a single missing update is uncritical because the game engine simply continues with the last known controller state until the next valid packet arrives.

C. Physical Design and Controllers

The physical setup is built on a black wooden base plate of 150 cm × 80 cm, spray-painted in blue, purple, and white to create a retro-futuristic backdrop. The track layout reuses Carrera GO!!! [14] track modules, along with two 5 m highly diffusing LED strips carrying 50 LEDs per meter (250 LEDs in total), to visualize the lanes, vehicles and intersections. All components were rigidly fastened using screws, cyanoacrylate adhesive, and double-sided tape to preserve transportability, and the looping module was additionally reinforced with fishing line to prevent fractures.
The original Carrera GO!!! hand controllers were modified from their built-in variable resistors into signal sources for the Pico. Each throttle is wired as a voltage divider feeding one

TECHNICAL REPORT FOR PHYSICAL COMPUTING LECTURE AT OTH AMBERG-WEIDEN, 07 2026 | 5

of the Pico’s ADC channels, yielding the raw analog value
transmitted as adc_0, while an added push button provides
the digital lane-change signal (dig_0).
Custom 3D-printed enclosures, styled to match the sci-fi aesthetic, conceal the Raspberry Pi 4, the Pico, the internal wiring, and house the stereo speakers. Beyond their visual role, these enclosures also serve a safety function: together with the only 3 A power draw per LED strip, they cover the electronics to prevent user contact and eliminate sharp edges and pinch points. The full physical design of the system is shown in Figure 5.


Fig. 5. Full physical design of the LumenTrace system in a properly lighted environment.

V. SOFTWARE IMPLEMENTATION AND GAME MECHANICS
This section describes the modular software architecture of the core application and the physics-based game mechanics it implements.
A. Software Architecture
The core application on the Raspberry Pi 4 follows an object-oriented design and is decomposed into loosely coupled Python packages, each with a well-defined responsibility, as illustrated in Figure 6. The Game package holds the core game logic, comprising vehicle physics, track management, and players. The Controller package translates player controller input into game state changes, while the Display package manages the LED effects and visual feedback. The Sound package provides the real-time, threaded audio mixer, and the Logger package centralizes debugging output to log files and MQTT [26], [27]. Finally, the Simulation package enables testing and visualization of the game mechanics without physical hardware. This separation of concerns keeps the system modular, maintainable, and straightforward for further extensions.
Python was chosen as the implementation language to maximize development velocity, readability, and access to mature hardware, audio, and testing libraries within the given project timeframe, accepting the Global Interpreter Lock (GIL) as a known trade-off against lower-level alternatives such as C/C++.
Because real-time audio and high-frequency physics impose strict timing guarantees, the application is partitioned into independent threads to mitigate contention on the GIL [28]; where thread-level parallelism proved insufficient, the audio path is further decoupled behind an asynchronous command queue rather than migrated to multiprocessing, keeping the shared game state simple and lock-free across subsystems. The physics loop runs at 50 Hz, the LED display pipeline at 33 Hz, and controller input polling at 50 Hz.
The latency-critical physics thread is strictly separated from the peripheral driver calls of the controller and display subsystems, and the audio interface is further isolated behind an asynchronous command queue [29], as detailed in Section VI-B.
B. Controller Inputs and Speed Calculation
Each 20 ms, the raw analog throttle value forwardPress reported by the Pico is mapped to a vehicle acceleration through linear interpolation [30], scaling the input range [42000, 65536] onto the output range [0, 100] of the acceleration a:
a(forwardPress) = forwardPress − 42000
65536 − 42000
- 100. (1)

The speed v is then integrated per tick as

v += a · amult | (2)

and clamped to the range [−vmax, +vmax] to prevent unstable values at high update rates, where amult is a configurable acceleration multiplier, and vmax is the maximum speed limit for both driving directions. To emulate realistic driving behavior, an adjustable friction coefficient [31] continuously dampens the current speed

v ∗= (1 − friction). | (3)
C. Physics
LumenTrace models several physics-based mechanics that emulate the behavior of classic slot cars [32]. The vehicle position is derived from speed using the active game-tick interval. When the position exceeds the length of the full track lane, the lap counter is incremented, and the position wraps around to zero.
Lane changing is realized through a temporary bidirectional center lane introduced by intersection modules. A change is only permitted when the driving profile of the current line allows it, but never within the final laneChangeWindow units before a module ends. A vehicle first switches from an outer lane to the middle lane and, after travelling at least one laneChangeWindow, may manually merge onto the target outer lane; otherwise the vehicle merges automatically before the module ends. During a switch, relative progress within the module is preserved by proportional conversion, where the target position equals the source progress ratio scaled by the target line length, keeping vehicles visually and physically aligned across lanes of differing lengths or radii.
Falling is triggered immediately when a vehicle’s speed or acceleration violates the driving profile of the active line, whose constraints are subdivided across curve and looping segments so that difficulty scales smoothly rather than abruptly at module entry. Collision detection is evaluated per lane using

TECHNICAL REPORT FOR PHYSICAL COMPUTING LECTURE AT OTH AMBERG-WEIDEN, 07 2026 | 6

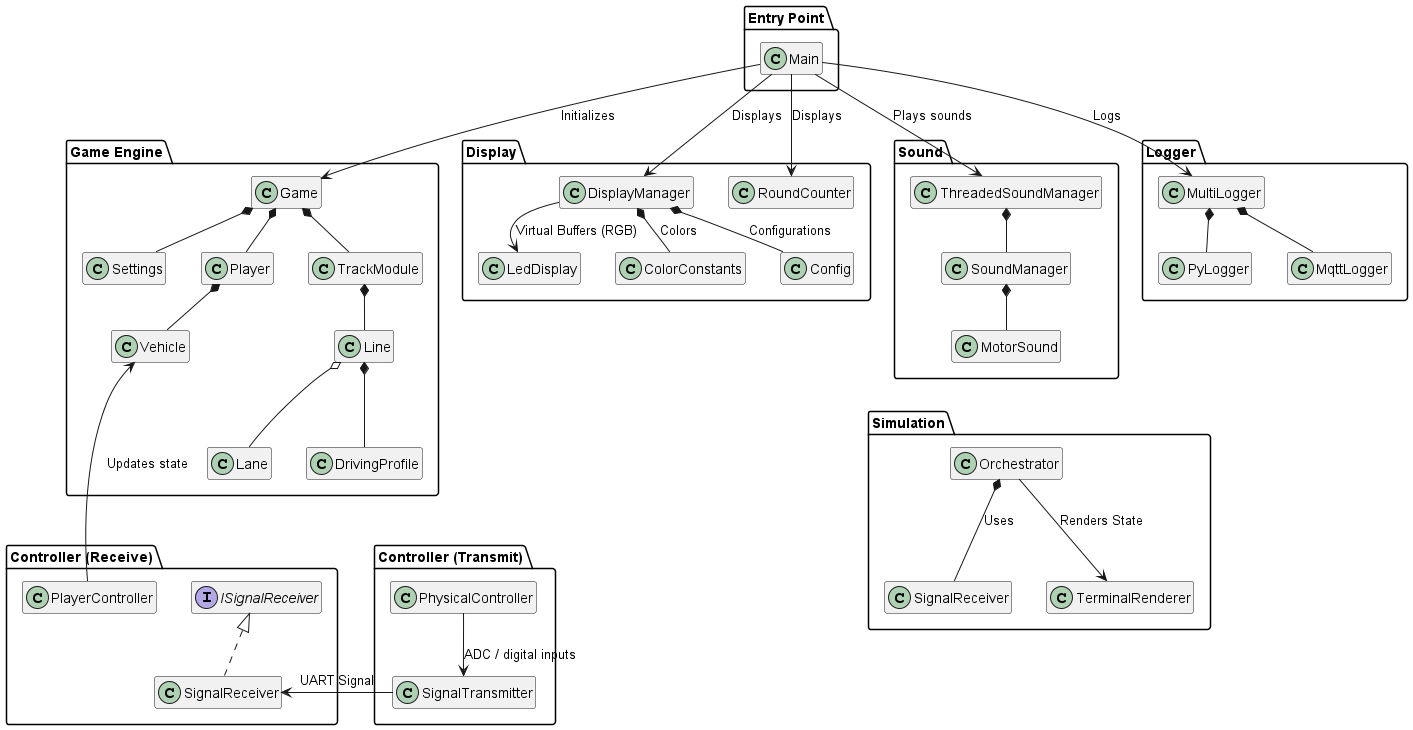
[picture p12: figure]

Fig. 6. Object-oriented software architecture of the LumenTrace core application, showing the modular package design.

a distance metric: if two vehicles come within a configured
crash distance, the leading vehicle loses control and falls while
the trailing vehicle continues unharmed, simulating a rearquarter impact that preserves playability.
After a crash, a multi-stage respawn procedure grants a collision-free placement with enough track to rebuild momentum for a possible looping in following modules. Fallen vehicles become inactive for a fixed number of respawn ticks and are ignored by the race. On respawn from a position inside a looping, a step back by one module is performed to avoid an immediate consecutive crash; the vehicle then attempts position zero on its preferred lane, falling back to other unoccupied lanes and, if necessary, to the track start. If no lane is available, the vehicle stays inactive and retries on the next tick until a position is free. Speed, acceleration, and the lane-change state are reset.
D. Deployment
For reproducible and hardware-independent operation, the LumenTrace application is packaged as a Docker container [12] on the Raspberry Pi 4. Running in privileged mode, the container bundles all system-level dependencies and grants the direct hardware access required for GPIO, LED, UART, and audio peripherals [33], ensuring consistent behavior across deployments. Privileged mode is a deliberate security trade-off: it effectively disables container isolation and grants the container full access to host devices, which is acceptable for this self-contained, single-purpose appliance on a dedicated, non-networked device, but would need to be replaced by fine-grained device and capability mappings (e.g., explicit --device and --cap-add rules) in any multitenant or network-exposed deployment. A systemd unit binds the container to the host lifecycle, starting it automatically on boot and restarting it on failure, which satisfies the cold-boot and reliability requirements from Section III-A.
E. Simulation and Testing

To validate the game logic without physical hardware, LumenTrace ships a text-based simulation runner that renders the full game state live in the terminal, including player and vehicle telemetry and an ASCII lane visualization. It is complemented by a pytest-based unit test suite [34] covering the core game rules, controller inputs and output devices. Together, they satisfy the maintainability requirement of independent, hardwareless testability from Section III-A.

VI. MULTIMEDIA SUBSYSTEMS: LED AND AUDIO CONTROL

This section covers the two multimedia subsystems of LumenTrace: the priority-based LED rendering pipeline and the real-time stereo audio mixer, together with the hardware constraints that shaped their design.

A. LED Rendering

Driving the two round-counter matrices together with the two track strips initially required four independent PixelStrip objects of the rpi_ws281x library on separate control lines (GPIO 10/SPI, GPIO 21/PCM, and GPIO 18/19/PWM). This approach failed because the underlying C driver [11] cannot mix PWM, SPI, and PCM peripherals concurrently within a single process, is hardware-capped at two active channels, and produced DMA register collisions

TECHNICAL REPORT FOR PHYSICAL COMPUTING LECTURE AT OTH AMBERG-WEIDEN, 07 2026 | 7

and memory-mapping failures when initializing multiple strips
on the same DMA channel.
The bottleneck was resolved by physically daisy-chaining all LED components onto the two PWM channels only. Along each of the two channels, the signal from the Pi 4’s GPIO first drives the round-counter matrix, then the main lane strip, and finally the additional intersection strip, with the connecting wires hidden beneath the track, as depicted in Figure 3.
A display manager translates the game state into visual output on the track LED strips by composing several layers from low to high priority, so that higher-priority effects override lower ones. The hierarchy is applied in the following order:
1) Track module base: faint purple main lanes.
2) Intersection module: lanes on intersection modules with a light pink overlay.
3) Intersection animation: stronger pink overlay for indicating a possible lane change.
4) Start line: starting position with a white overlay.
5) Round advance: blinking starting position on lap completion.
6) Inactive vehicles: respawning vehicles displayed as dimmed gray.
7) Active vehicle: custom vehicle color with a speeddependent color interpolation as speed warning [10].
8) Front lights: white headlights, disabled by default.
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

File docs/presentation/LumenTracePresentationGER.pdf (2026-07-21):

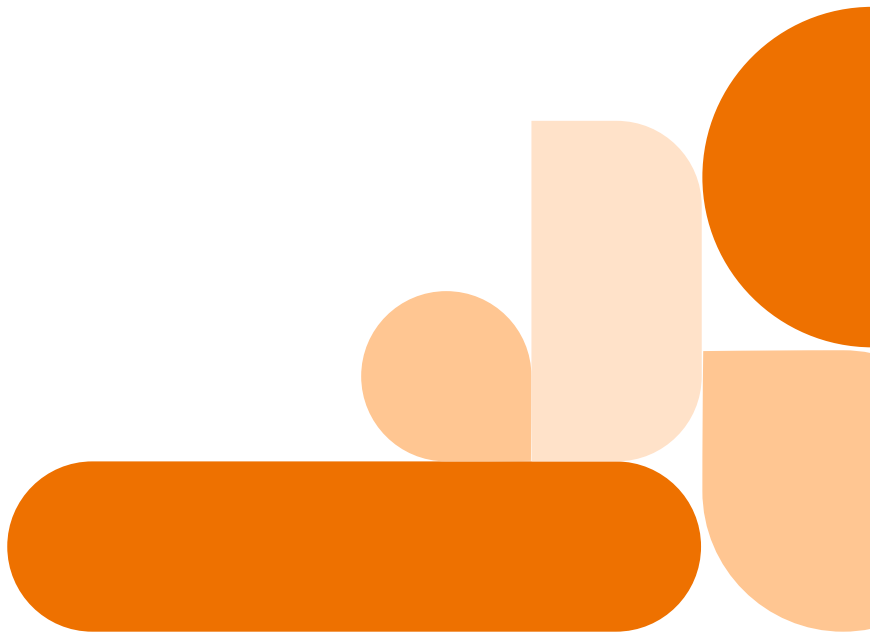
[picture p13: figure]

© 2024 OTH Amberg-Weiden

# LUMENTRACE AT THE SPEED OF LIGHT

Simon Völkl, Erik Dombrowsky, Simon Frey

Physical Computing | OTH Amberg-Weiden

Repository: github.com/s-voelkl/LumenTrace

Simon Völkl, Johannes Schieder | BiteBound

Quellen: Bild Carrera Bahn https://th.bing.com/th/id/R.87136c5a2e1a8c6b8662643d5c8fb11a?rik=JOzO0v0DOGJLzQ&pid=ImgRaw&r=0; Bild Kurvenelement https://static.fnacstatic.com/multimedia/Images/AE/AE/6C/42/4353198-1505-1540-1/tsp20201120194810/Carrera-Go-courbe-morceau-de-la-piste-1-90-degres-2-pieces.jpg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

Mechanik-freie Carrera-Bahn mit:

- Steuerung
- 3D-Druck
- 3-4 RGB-LED-Streifen
- Sound
- Auf Basis eines Raspberry Pi Pico 2W mit PIO

## Anforderungen und Ground Truth

## Showcase

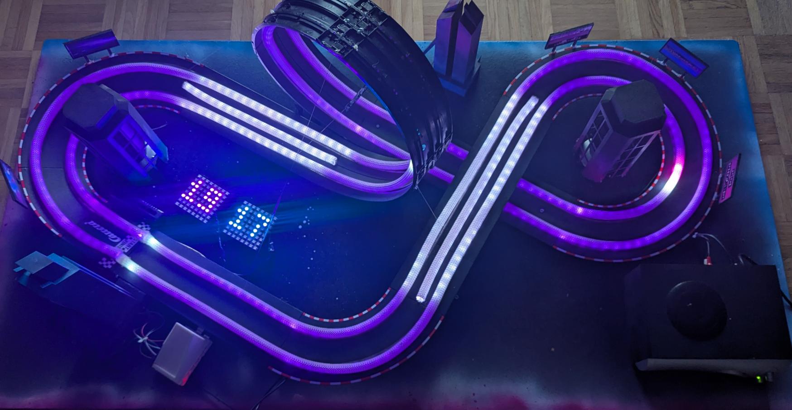
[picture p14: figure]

## Systemarchitektur

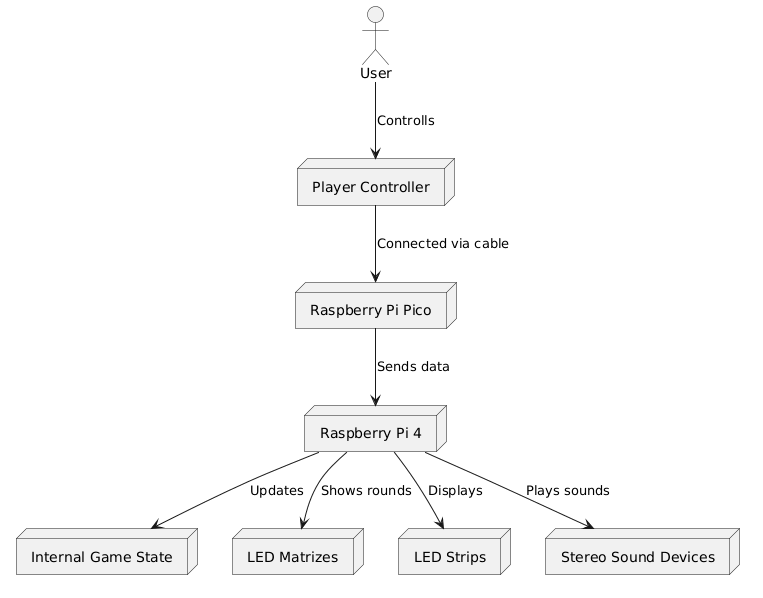
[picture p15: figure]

## Softwarearchitektur

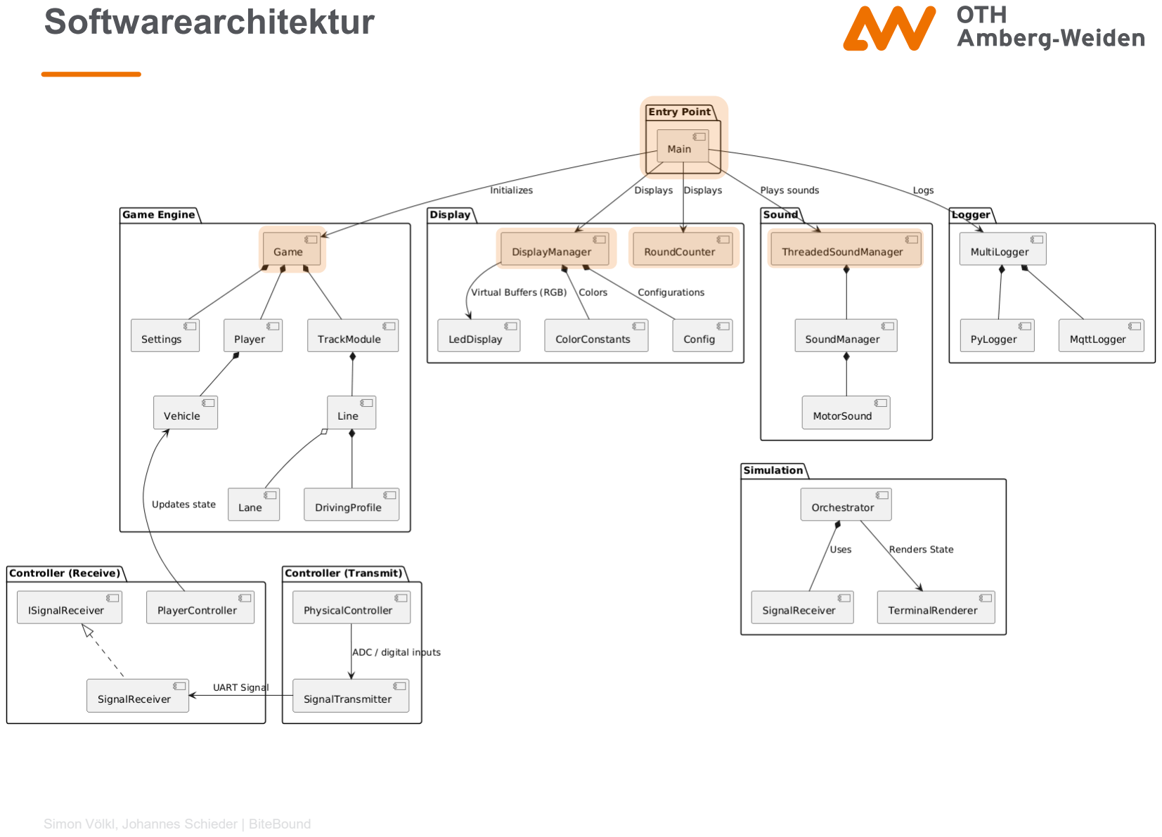
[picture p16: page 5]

## Hardwareaufbau

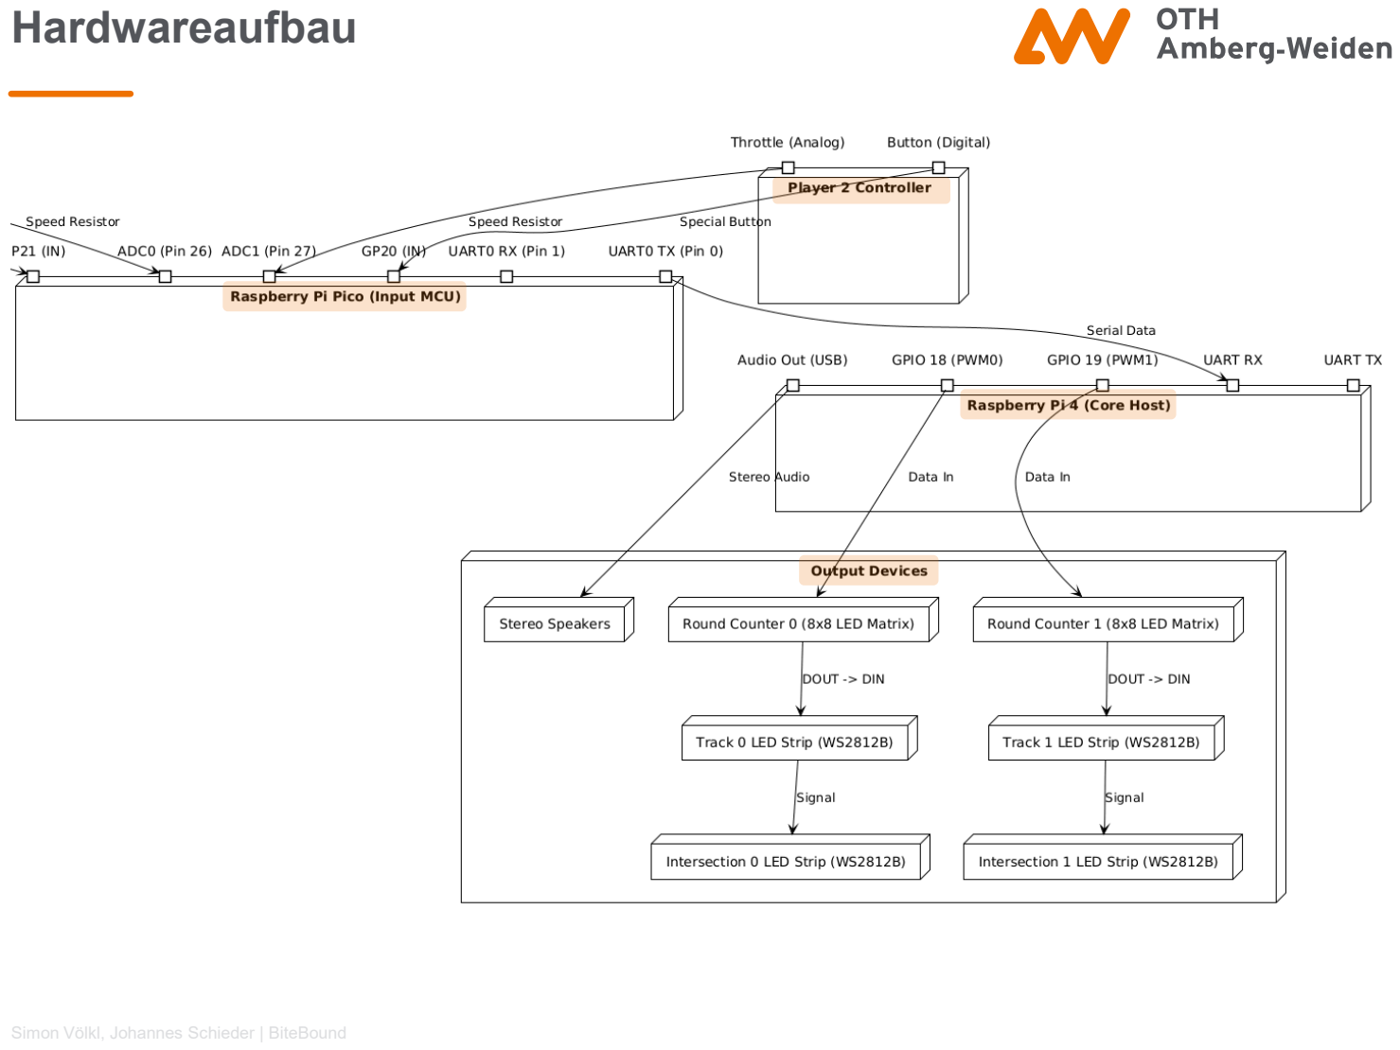
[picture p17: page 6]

## 3D-Druck

4 Meilensteine

## Projektmanagement

Proof of Concept

Enhancements
- Sound

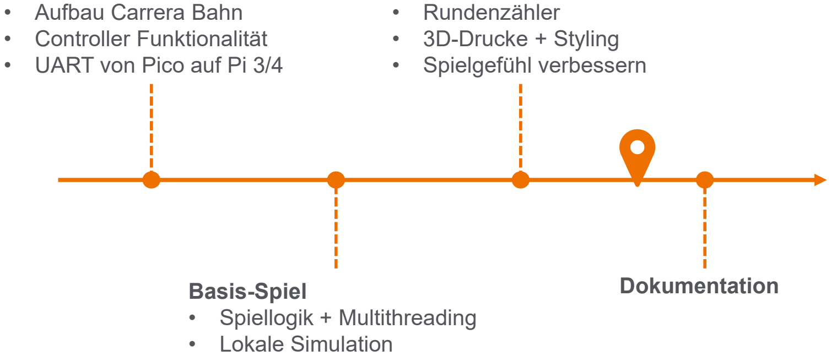
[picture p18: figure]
• Aufbau Carrera Bahn • Controller Funktionalität • UART von Pico auf Pi 3/4; • Rundenzähler • 3D-Drucke + Styling • Spielgefühl verbessern; Basis-Spiel; Dokumentation; • Spiellogik + Multithreading • Lokale Simulation

- Ansteuerung LED-Strips

- Physische Controller mit Vibrationsmodul für haptisches Feedback
- Display der MQTT-Telemetriedaten auf Webpanel
- Spezialfähigkeiten (außerhalb der Überholspuren, z.B. Nitro, Feuerball, …)
- Münzen zum Einsammeln
- Spielmodi/Umgebungseffekte (Sturm, Regen, …)
- KI-Gegner (Reinforcement Learning)
- Weitere Ambience-Effekte (3D-Drucke, Scheinwerfer, Sound in den Modulen, …)
- Eigene Module (Carrera-Unabhängigkeit, Abzweigungen, …)
- Geglättete Geschwindigkeitslimits gegen abrupte Kollisionen
- Business Case entwickeln
- …

## Future Work

© 2024 OTH Amberg-Weiden

# LUMENTRACE AT THE SPEED OF LIGHT

Simon Völkl, Erik Dombrowsky, Simon Frey

Physical Computing | OTH Amberg-Weiden

Repository: github.com/s-voelkl/LumenTrace

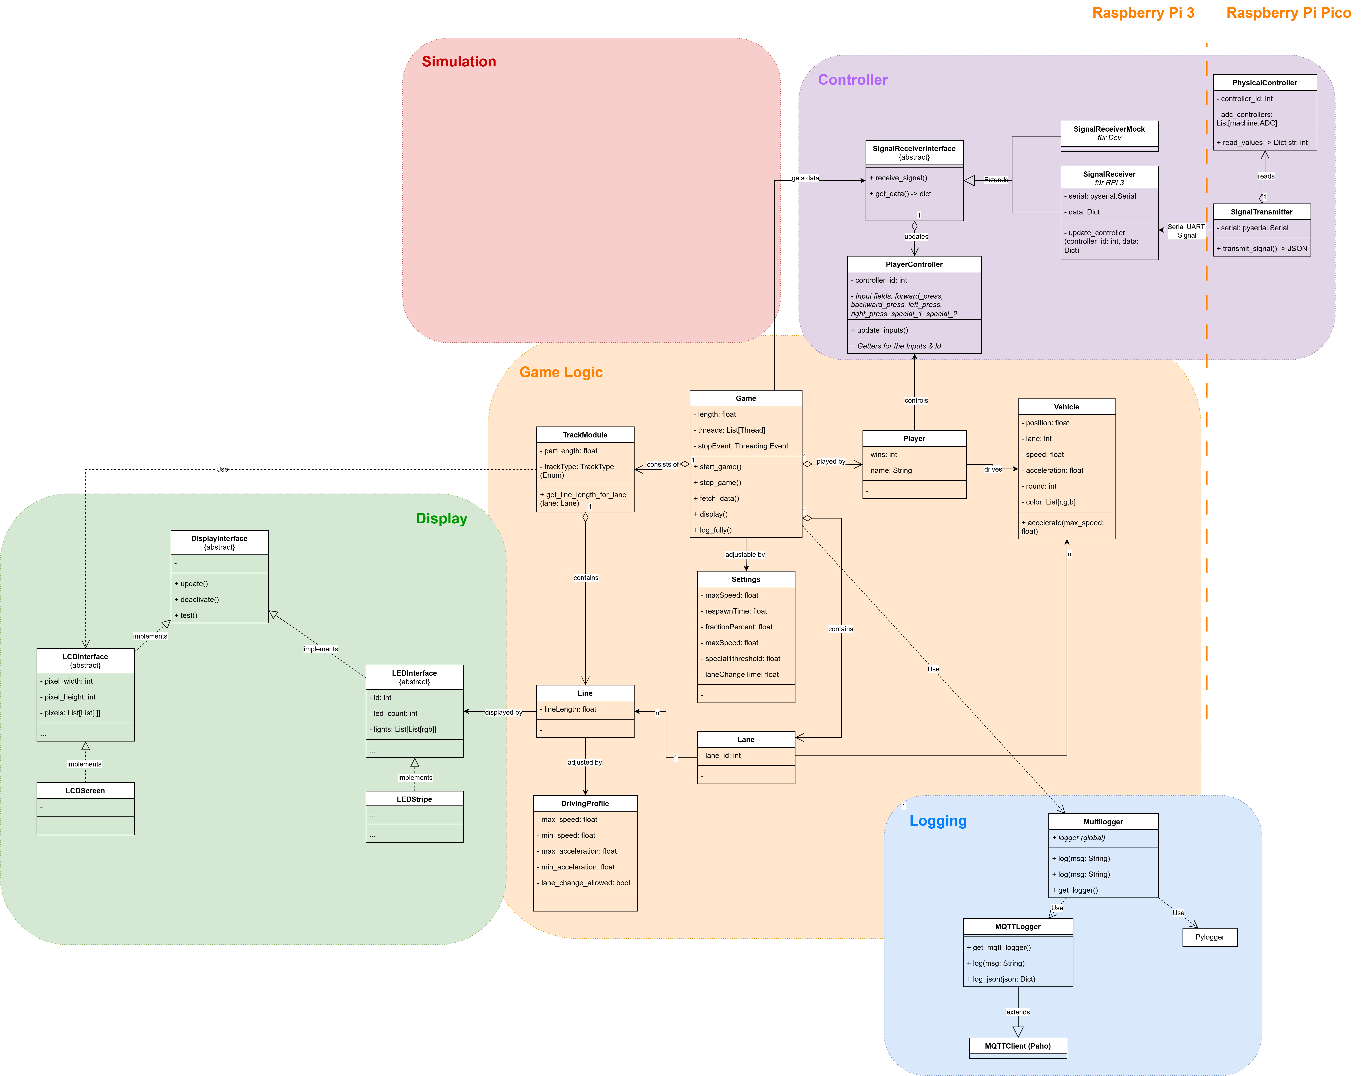
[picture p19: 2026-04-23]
docs/architecture.png

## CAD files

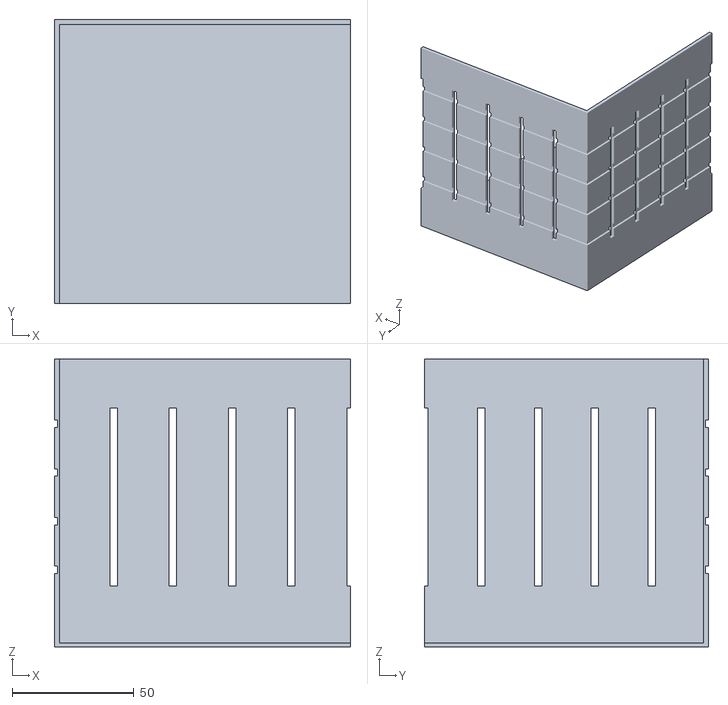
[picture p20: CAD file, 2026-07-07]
3d-models/stl/subcover_q1.stl
121.5 x 116.5 x 118.1

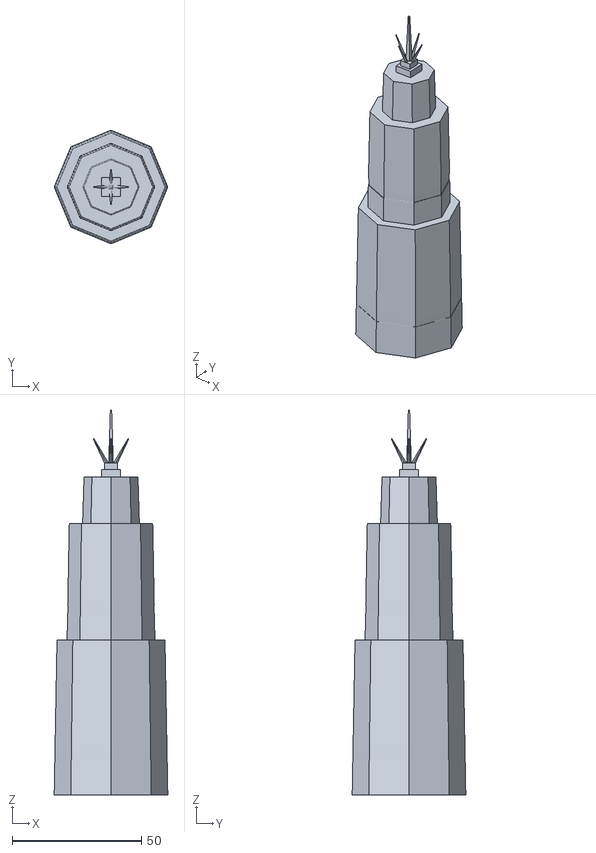
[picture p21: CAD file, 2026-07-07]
3d-models/stl/building_t5.stl
44.0 x 44.0 x 149.0

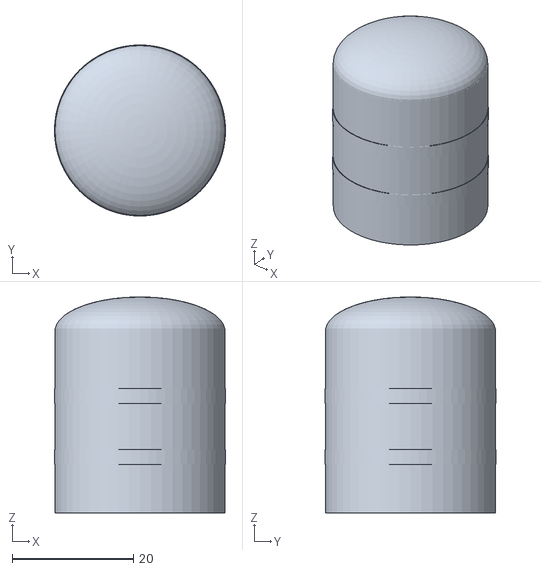
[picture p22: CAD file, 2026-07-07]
3d-models/stl/sf_tank.stl
28.2 x 28.2 x 35.6

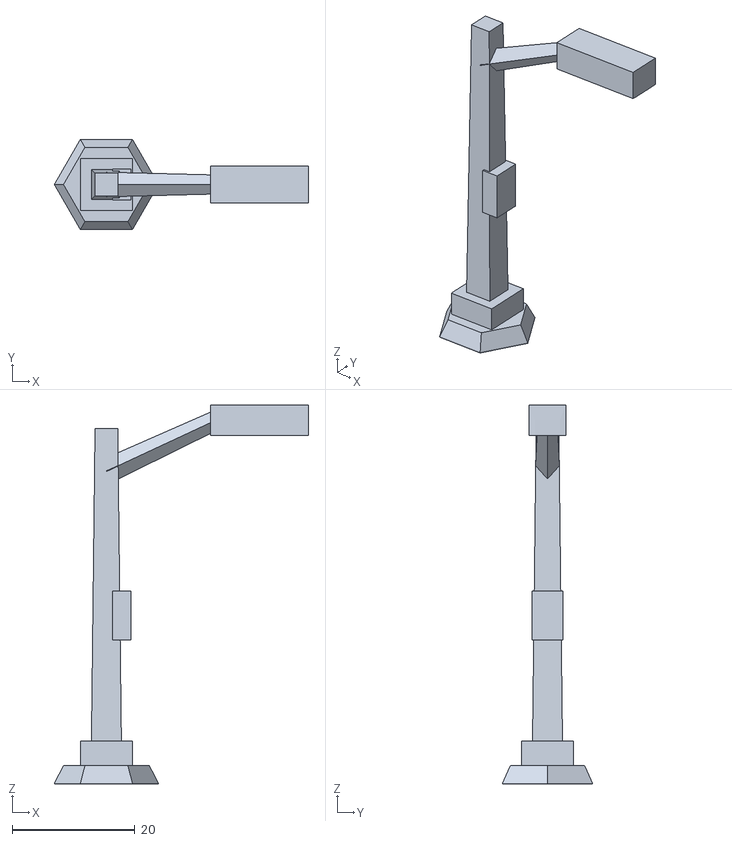
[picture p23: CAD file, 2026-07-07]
3d-models/stl/lamp_a.stl
41.5 x 14.7 x 61.8

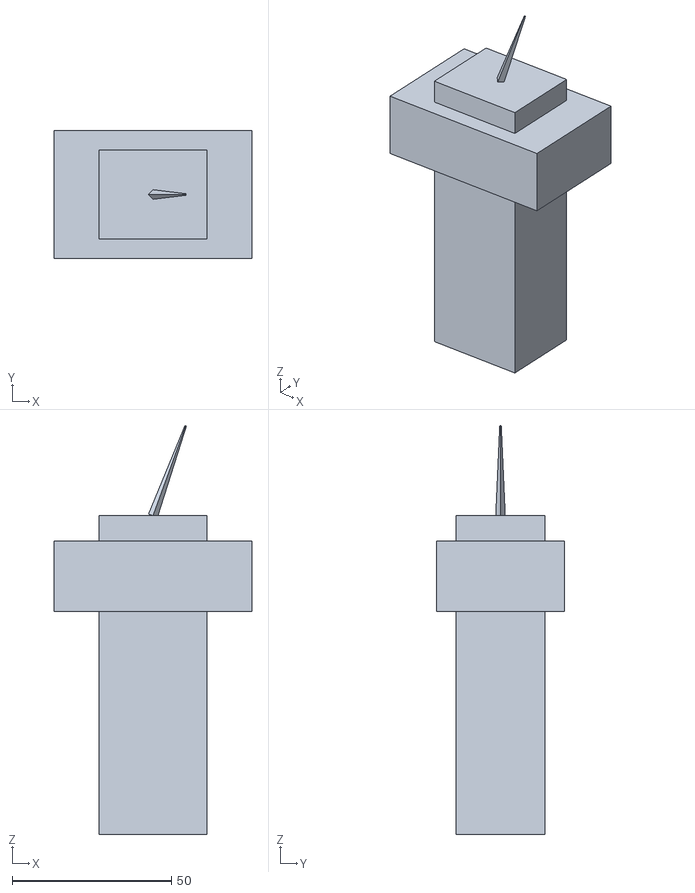
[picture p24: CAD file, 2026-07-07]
3d-models/stl/sf_cantilever_tower.stl
62.0 x 40.0 x 128.3

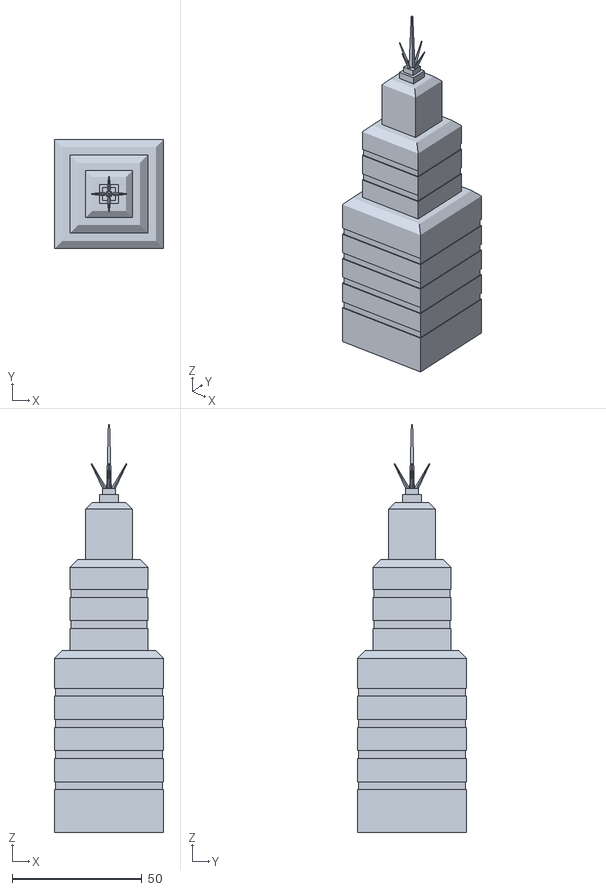
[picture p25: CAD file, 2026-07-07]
3d-models/stl/building_t1.stl
42.0 x 42.0 x 157.0

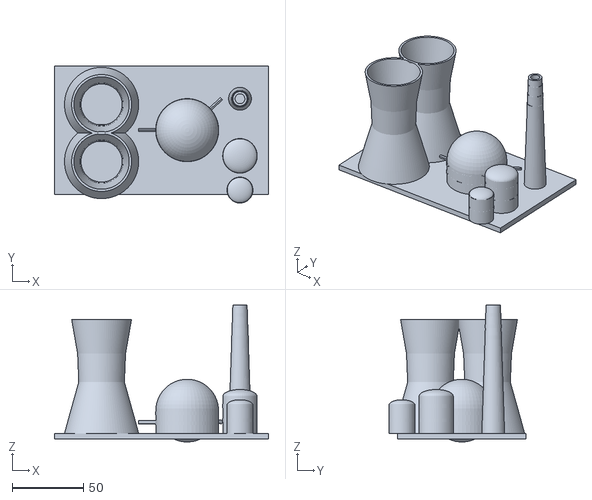
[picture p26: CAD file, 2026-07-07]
3d-models/stl/sf_power_plant.stl
150.0 x 96.1 x 96.0

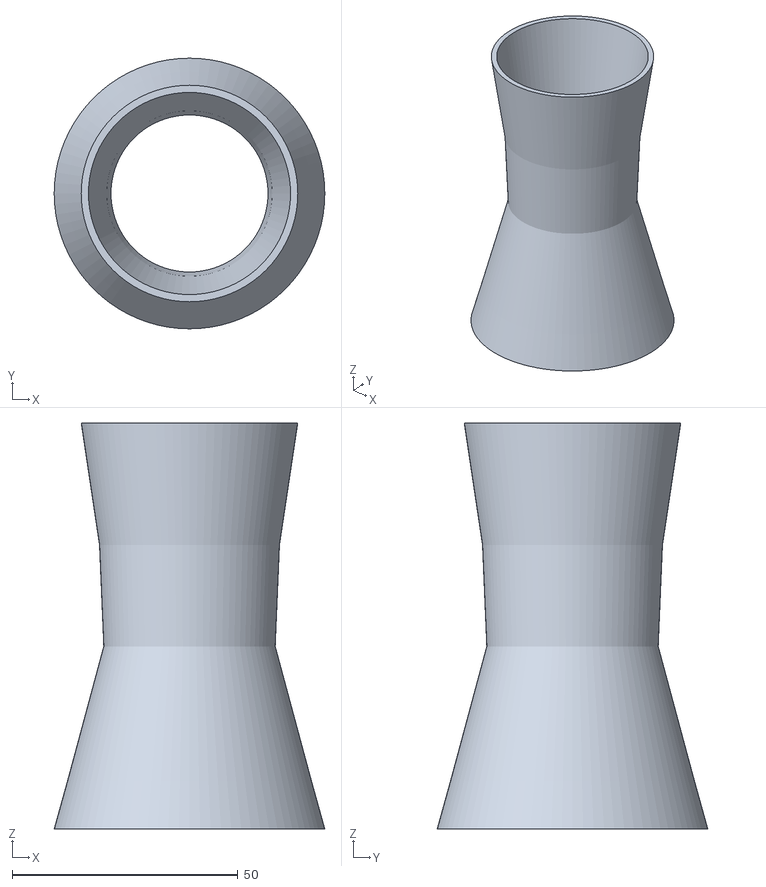
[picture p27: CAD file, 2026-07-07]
3d-models/stl/sf_cooling_tower.stl
60.0 x 60.0 x 90.0

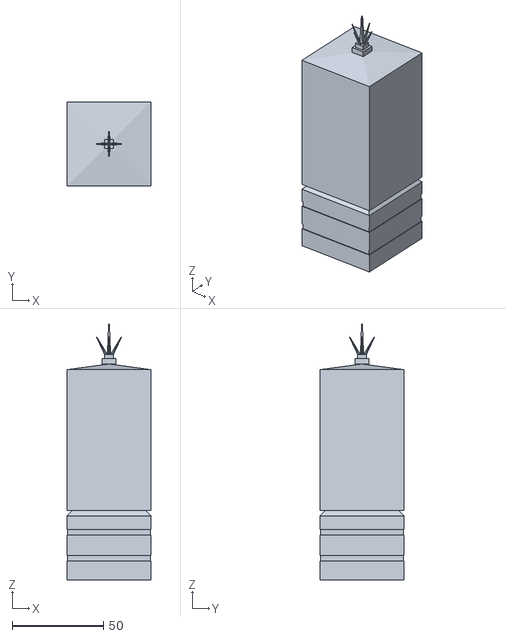
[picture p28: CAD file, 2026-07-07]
3d-models/stl/building_t7.stl
46.0 x 46.0 x 140.0

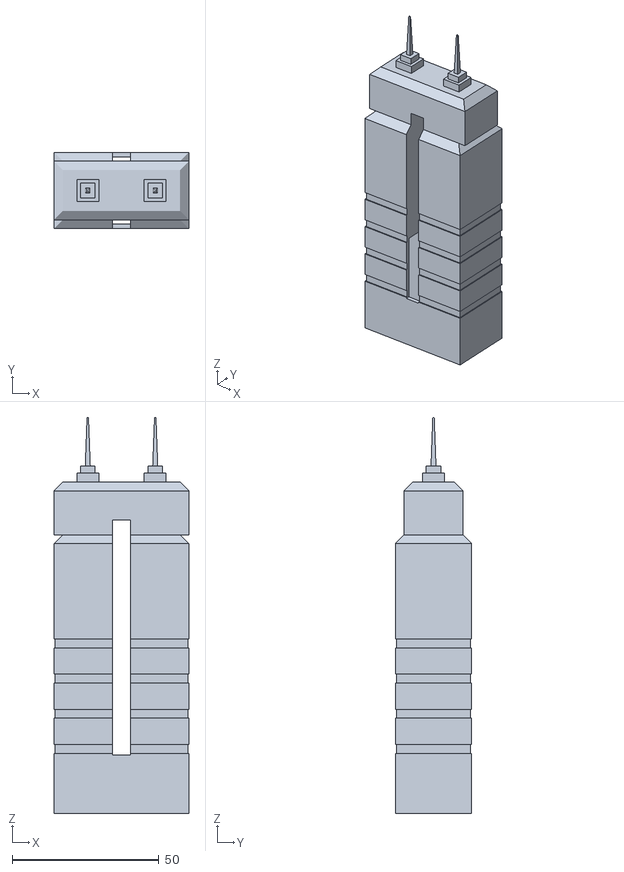
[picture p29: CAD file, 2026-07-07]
3d-models/stl/building_t4.stl
46.0 x 26.0 x 135.0

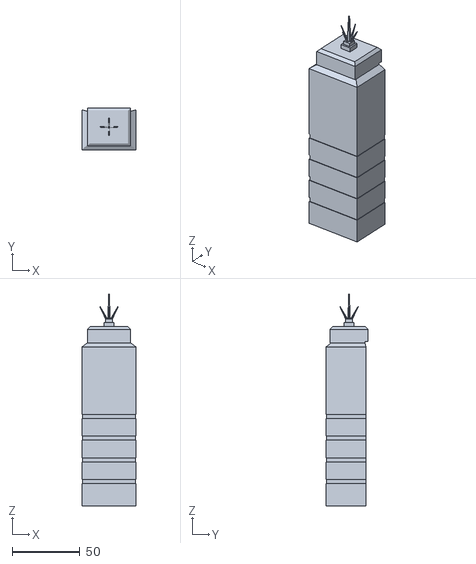
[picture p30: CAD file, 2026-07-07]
3d-models/stl/building_t6.stl
40.0 x 31.0 x 156.0

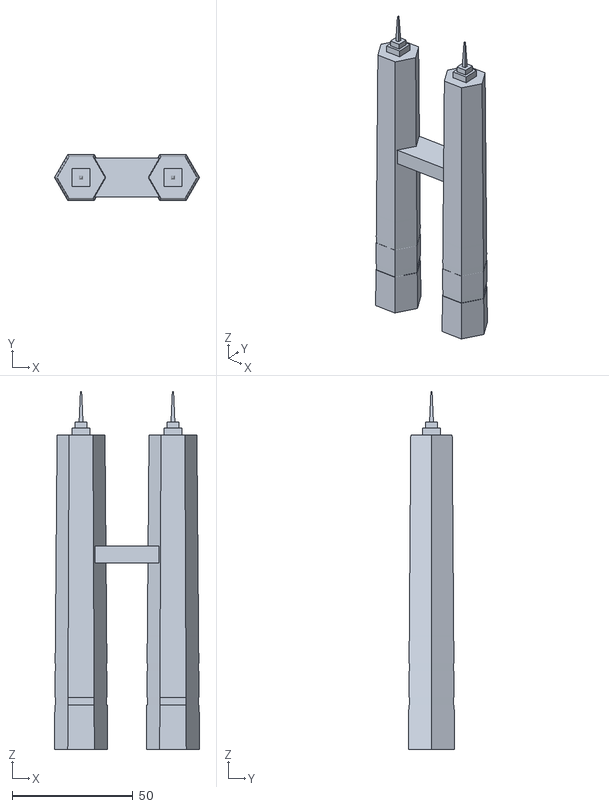
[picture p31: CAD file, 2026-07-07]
3d-models/stl/building_t8.stl
60.0 x 19.1 x 148.0

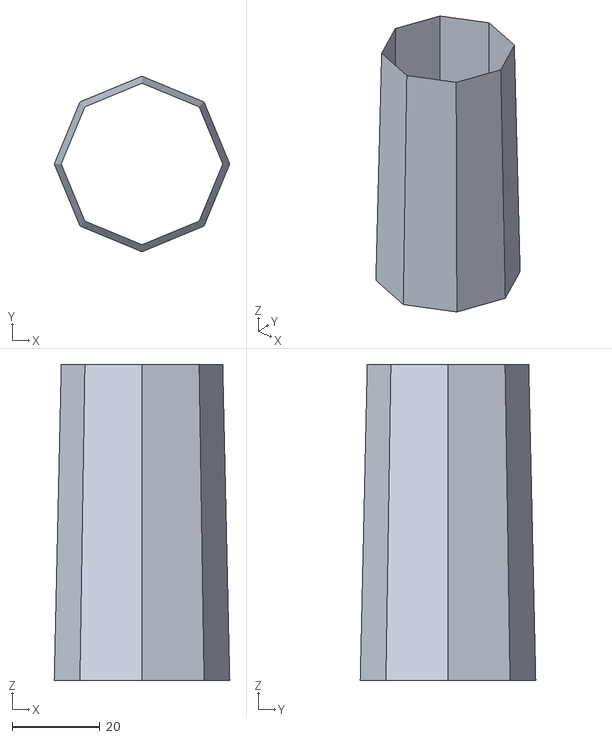
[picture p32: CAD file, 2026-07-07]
3d-models/stl/building_t3.stl
40.0 x 40.0 x 72.0

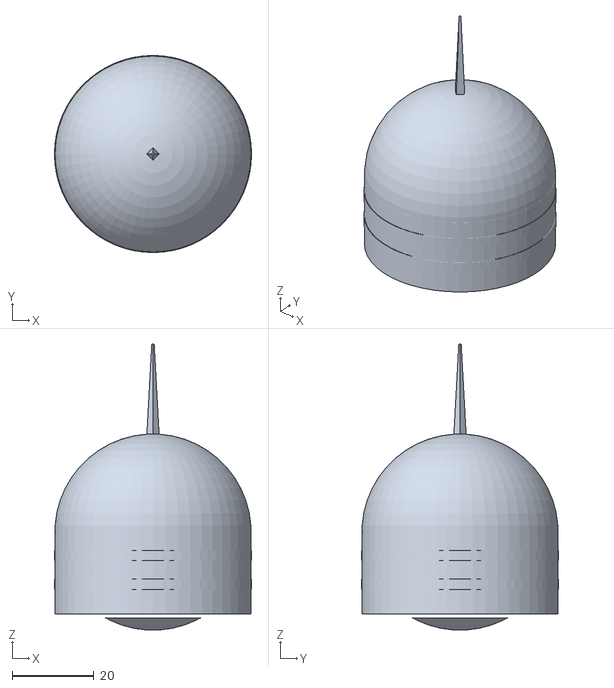
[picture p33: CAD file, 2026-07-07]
3d-models/stl/sf_reactor_spire.stl
48.2 x 48.2 x 69.9

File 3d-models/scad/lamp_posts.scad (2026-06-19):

// --- LumenTrace Cyberpunk Street Lamp Posts ---
// Kantige Sci-Fi-Strassenlaternen als Deko entlang der Bahn auf der
// schwarzen Platte. Passend zum Skyline-Stil (skyline_buildings.scad).
// Alle Masse in Millimetern (mm). Massstab passend zur Carrera-Bahn.
//
// Jede Laterne hat eine NUT bzw. eingelassene Flaeche als "LED-Leuchte".
// Mit transparentem Filament gedruckt leuchtet sie im Bahn-Ambiente mit.
// Alle Masten eckig (Diamant-/Quadrat-Querschnitt) fuer den kantigen Look.

// ============================ PARAMETER ============================
post_h      = 55;     // Hoehe des Mastes
post_w      = 5;      // Mast-Schluesselweite (eckig)
base_w      = 14;     // Grundplatte Breite
base_h      = 3;      // Grundplatte Hoehe
arm_len     = 22;     // Auslegerlaenge
glow_depth  = 0.8;    // Tiefe der Leucht-Nut
$fn         = 32;

// Welche Laterne: "lamp_a" | "lamp_b" | "lamp_c" | "all"
show_lamp = "all";

// ============================ HELFER ===============================

// Eckiger Mast (Diamant-Querschnitt), leicht verjuengt.
module post(h = post_h, w = post_w) {
    rotate([0, 0, 45])
        cylinder(h = h, d1 = w*1.41, d2 = w*1.05, $fn = 4);
}

// Kantige Grundplatte mit abgeschraegten Ecken + Tech-Sockel.
module base() {
    hull() {
        cylinder(h = base_h, d = base_w, $fn = 6);
        cylinder(h = 0.1, d = base_w + 3, $fn = 6);
    }
    // Tech-Sockel
    translate([0, 0, base_h]) rotate([0,0,45])
        cylinder(h = 4, d = post_w*2.4, $fn = 4);
}

// Leuchtkopf-Box mit eingelassener Glow-Flaeche an der Unterseite.
module lamp_head(l = 16, w = 6, t = 5) {
    difference() {
        // kantiger Kopf, vorne angeschraegt
        hull() {
            cube([l, w, t], center = true);
            translate([l/2, 0, -t/4]) cube([0.1, w-2, t/2], center = true);
        }
        // Glow-Nut unten
        translate([0, 0, -t/2 + glow_depth/2 - 0.01])
            cube([l - 3, w - 2, glow_depth], center = true);
    }
}

// ============================ LATERNEN =============================

// Lamp A — Klassischer Ausleger (single arm), kantig
module lamp_a() {
    union() {
        base();
        translate([0, 0, base_h]) post();
        // Auslegerarm schraeg nach oben
        translate([0, 0, post_h - 4]) {
            rotate([0, 65, 0])
                cylinder(h = arm_len, d1 = 4, d2 = 3, $fn = 4);
            // Leuchtkopf am Armende (rotate Z->X: x=h*sin, z=h*cos)
            arm_end_x = arm_len * sin(65);
            arm_end_z = arm_len * cos(65);
            translate([arm_end_x + 5, 0, arm_end_z - 1])
                lamp_head();
        }
        // kleine Tech-Box am Mast
        translate([post_w/2, 0, post_h*0.5]) cube([3, 5, 8], center = true);
    }
}

// Lamp B — Doppelausleger (beidseitig), symmetrisch
module lamp_b() {
    union() {
        base();
        translate([0, 0, base_h]) post(post_h + 6);
        for (m = [0, 1]) mirror([m, 0, 0])
            translate([0, 0, post_h]) {
                rotate([0, 72, 0])
                    cylinder(h = arm_len*0.8, d1 = 3.5, d2 = 2.5, $fn = 4);
                ax = arm_len*0.8 * sin(72);
                az = arm_len*0.8 * cos(72);
                translate([ax + 4, 0, az - 1]) lamp_head(13, 5, 4);
            }
        // Querstrebe / Funkmodul oben
        translate([0, 0, post_h + 6]) cube([4, 4, 6], center = true);
        translate([0, 0, post_h + 12]) rotate([0,0,45]) cylinder(h = 8, d1 = 2, d2 = 0.4, $fn = 4);
    }
}

// Lamp C — Monolith-Pylon mit vertikaler Leuchtleiste (sehr cyberpunk)
module lamp_c() {
    pw = 8; ph = 50;
    union() {
        base();
        difference() {
            // kantiger Pylon, oben schraeg angeschnitten
            difference() {
                translate([0, 0, base_h]) rotate([0,0,45])
                    cylinder(h = ph, d1 = pw*1.5, d2 = pw*1.1, $fn = 4);
                // schraeger Kopfschnitt
                translate([0, 0, base_h + ph - 6])
                    rotate([20, 0, 0]) translate([-20,-20,0]) cube([40,40,20]);
            }
            // vertikale Leucht-Nut auf zwei Seiten
            for (a = [0, 90])
                rotate([0,0,a])
                    translate([0, pw*0.6, base_h + ph/2])
                        cube([2.5, glow_depth*2, ph*0.7], center = true);
        }
        // auskragendes Tech-Modul
        translate([pw*0.6, 0, base_h + ph*0.4])
            cube([6, 8, 12], center = true);
    }
}

// ============================ AUSGABE =============================
if      (show_lamp == "lamp_a") lamp_a();
else if (show_lamp == "lamp_b") lamp_b();
else if (show_lamp == "lamp_c") lamp_c();
else {
    lamp_a();
    translate([45, 0, 0]) lamp_b();
    translate([90, 0, 0]) lamp_c();
}

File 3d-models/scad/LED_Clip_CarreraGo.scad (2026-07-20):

// --- Carrera Go LED Clip (Flach & Offen / Sichtfeld-Style) ---
// Alle Maße in Millimetern (mm). 
// Passt diese Werte an eure exakten Messungen an!

// --- PARAMETER ---
// 1. Der Pin für die Carrera-Schiene
slot_width = 4.0;      // Breite der Rille (Carrera Go ca. 3mm)
slot_depth = 5.0;      // Wie tief der Pin in die Rille ragt
clip_length = 5.0;     // Wie lang der Clip in Fahrtrichtung ist

// 2. Der LED-Streifen (Horizontal liegend)
strip_width_flat = 13.0; // Breite des flach liegenden Streifens (meist 10-12mm)
strip_thickness = 1.0;  // Dicke des Streifens inkl. Klebeband/Chips
// Diese Nase greift *nur* die alleräußerste Kante des Streifens!
snap_lip_width = 2;  // Wie weit die Nase nach innen ragt (sehr fein)

// 3. Stabilität & Toleranz
wall = 1.6;            // Wandstärke der Basisplatte (die auf der Fahrbahn liegt)
gap_clearance = 0.5;   // Minimaler Freiraum zum Streifen für Toleranz

// --- GENERATOR (Völlig neu konstruiert) ---
module led_clip_flat_sichtfeld() {
    union() {
        // 1. Der Pin (Steckt in der Bahn)
        // Zentriert um den Ursprung für Symmetrie
        translate([0, 0, -slot_depth/2])
            cube([slot_width, clip_length, slot_depth], center=true);
            
        // 2. Die flache Basis (Liegt auf der Fahrbahn auf)
        // Muss breiter sein als der Pin und der Streifen, um Stabilität zu geben
        translate([0, 0, wall/2])
            cube([strip_width_flat + 2*wall + 2*gap_clearance, clip_length, wall], center=true);
            
        // 3. Die sehr niedrigen Halterwände (knapp über Streifendicke)
        wall_height = strip_thickness + gap_clearance; // Etwas höher als Dicke für Halt
        
        // Rechte Wand
        translate([(strip_width_flat/2 + gap_clearance + wall/2), 0, wall + wall_height/2])
            cube([wall, clip_length, wall_height], center=true);
            
        // Linke Wand
        translate([-(strip_width_flat/2 + gap_clearance + wall/2), 0, wall + wall_height/2])
            cube([wall, clip_length, wall_height], center=true);
            
        // 4. Die ultra-feinen Halte-Nasen (Klick-Mechanismus oben)
        // Diese greifen nur die alleräußerste PCB-Kante!
        lip_thickness = 0.8;
        
        // Rechte Nase
        translate([(strip_width_flat/2 + gap_clearance - snap_lip_width/2), 0, wall + wall_height - lip_thickness/2])
            cube([snap_lip_width, clip_length, lip_thickness], center=true);
            
        // Linke Nase
        translate([-(strip_width_flat/2 + gap_clearance - snap_lip_width/2), 0, wall + wall_height - lip_thickness/2])
            cube([snap_lip_width, clip_length, lip_thickness], center=true);
    }
}

// Modell rendern
led_clip_flat_sichtfeld();

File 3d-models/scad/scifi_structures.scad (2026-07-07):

// --- LumenTrace Sci-Fi-Strukturen: Kraftwerke & Strommasten ---
// Erweiterung der Skyline: Kuehltuerme, Reaktorkuppel, Tanks, ein
// kompletter Kraftwerks-Komplex, Hochspannungsmasten und ein
// auskragendes Sci-Fi-Hochhaus. Diese duerfen Stuetzen brauchen.
// Alle Masse in Millimetern (mm).

$fn = 48;
wall = 1.6;

// Ausgabe-Auswahl:
// "all" | "cooling_tower" | "reactor" | "chimney" | "tank"
// | "power_plant" | "pylon" | "cantilever_tower" | "reactor_spire"
show = "all";

// ============================ HELFER ==============================

// Strebe (Zylinder) zwischen zwei Punkten p1 und p2
module strut(p1, p2, d = 1.6) {
    v = [p2[0]-p1[0], p2[1]-p1[1], p2[2]-p1[2]];
    len = norm(v);
    if (len > 0.01) {
        translate(p1)
            // ausrichten entlang v
            rotate([0, acos(v[2]/len), atan2(v[1], v[0])])
                cylinder(h = len, d = d, $fn = 6);
    }
}

// Umlaufende Nut (Deko-Band) auf einem Zylinder
module ring_groove(z, r, depth = 1.0, h = 2.5) {
    translate([0, 0, z])
        rotate_extrude($fn = 64)
            translate([r - depth, 0]) square([depth + 0.1, h]);
}

// ============================ KUEHLTURM ===========================
// Hyperboloid-Schale (breit unten, Taille, leicht ausgestellt oben).
module cooling_tower(h = 90, r_base = 30, r_waist = 19, r_top = 24) {
    // Profil-Stuetzpunkte (radius, hoehe)
    pts_out = [
        [r_base,        0],
        [r_base*0.9,    h*0.12],
        [r_waist,       h*0.45],
        [r_waist*1.05,  h*0.7],
        [r_top,         h]
    ];
    pts_in = [ for (i = [len(pts_out)-1 : -1 : 0]) [max(pts_out[i][0]-wall, 0.5), pts_out[i][1]] ];
    rotate_extrude($fn = 80)
        polygon(concat(pts_out, pts_in));
}

// ============================ REAKTORKUPPEL =======================
module reactor_dome(r = 24, base_h = 20) {
    // Sockel-Zylinder + Halbkugel-Kuppel, hohl
    difference() {
        union() {
            cylinder(h = base_h, r = r);
            translate([0, 0, base_h]) sphere(r = r);
        }
        // aushoehlen
        translate([0, 0, -1]) cylinder(h = base_h + 1, r = r - wall);
        translate([0, 0, base_h]) sphere(r = r - wall);
        // unten offen bleibt durch die Bohrung
    }
    // Deko-Ringe am Sockel
    for (z = [6, 13]) ring_groove(z, r);
}

// Kuppel mit Antennenspitze (Variante)
module reactor_spire() {
    reactor_dome();
    translate([0, 0, 20 + 24]) cylinder(h = 22, d1 = 3, d2 = 0.6, $fn = 4);
}

// ============================ SCHORNSTEIN =========================
module chimney(h = 95, r1 = 9, r2 = 6) {
    difference() {
        cylinder(h = h, r1 = r1, r2 = r2);
        translate([0, 0, -1]) cylinder(h = h + 2, r1 = r1 - wall, r2 = r2 - wall);
    }
    // Warnstreifen als Ringe oben
    for (z = [h-8, h-16, h-24]) ring_groove(z, r2 + (r1-r2)*(h-z)/h);
}

// ============================ TANK ================================
module tank(h = 30, r = 14) {
    difference() {
        union() {
            cylinder(h = h, r = r);
            translate([0, 0, h]) scale([1, 1, 0.4]) sphere(r = r); // gewoelbter Deckel
        }
        translate([0, 0, -1]) cylinder(h = h, r = r - wall);
    }
    for (z = [8, 18]) ring_groove(z, r);
}

// ============================ KRAFTWERK-KOMPLEX ===================
module power_plant() {
    // Grundplatte
    plate = [150, 90];
    translate([-plate[0]/2, -plate[1]/2, 0]) cube([plate[0], plate[1], 4]);

    // zwei Kuehltuerme
    translate([-42,  18, 4]) cooling_tower(h = 80, r_base = 26, r_waist = 16, r_top = 21);
    translate([-42, -22, 4]) cooling_tower(h = 80, r_base = 26, r_waist = 16, r_top = 21);
    // Reaktorkuppel
    translate([18, 0, 4]) reactor_dome(r = 22, base_h = 16);
    // Schornstein
    translate([55, 22, 4]) chimney(h = 90, r1 = 8, r2 = 5);
    // Tankgruppe
    translate([55, -18, 4]) tank(h = 26, r = 12);
    translate([55, -42, 4]) tank(h = 20, r = 9);
    // ein paar Verbindungsrohre (Streben)
    strut([18, 0, 14], [42, 22, 12], 2.5);
    strut([-16, 0, 12], [10, 0, 12], 2.5);
}

// ============================ STROMMAST (PYLON) ===================
// Stilisierter Gittermast: 4 verjuengte Beine, X-Streben in Ebenen,
// zwei Ausleger-Kreuze mit Isolator-Stummeln, Spitze.
module power_pylon(h = 120) {
    base = 22;   // halbe Fussbreite
    topw = 6;    // halbe Kopfbreite
    levels = 6;

    // Beinpositionen als Funktion der Hoehe (lineare Verjuengung)
    function half_at(z) = base + (topw - base) * (z/h);
    corners = [[1,1],[1,-1],[-1,-1],[-1,1]];

    // 4 Beine
    for (c = corners)
        for (i = [0 : levels-1]) {
            z0 = h * i/levels;   z1 = h * (i+1)/levels;
            p0 = [c[0]*half_at(z0), c[1]*half_at(z0), z0];
            p1 = [c[0]*half_at(z1), c[1]*half_at(z1), z1];
            strut(p0, p1, 2.4);
        }

    // X-Streben in jeder Ebene auf allen 4 Seiten
    for (i = [0 : levels-1]) {
        z0 = h * i/levels;   z1 = h * (i+1)/levels;
        for (s = [0:3]) {
            a = corners[s]; b = corners[(s+1)%4];
            pa0 = [a[0]*half_at(z0), a[1]*half_at(z0), z0];
            pa1 = [a[0]*half_at(z1), a[1]*half_at(z1), z1];
            pb0 = [b[0]*half_at(z0), b[1]*half_at(z0), z0];
            pb1 = [b[0]*half_at(z1), b[1]*half_at(z1), z1];
            strut(pa0, pb1, 1.5);
            strut(pb0, pa1, 1.5);
            strut(pa1, pb1, 1.5); // horizontale Verbindung oben
        }
    }

    // zwei Ausleger-Ebenen (Cross-Arms) mit Isolator-Stummeln
    for (z = [h*0.62, h*0.82]) {
        arm = (z < h*0.7) ? 34 : 26;
        hw = half_at(z);
        for (sgn = [-1, 1]) {
            tip = [sgn*arm, 0, z];
            strut([sgn*hw, hw, z], tip, 2.0);
            strut([sgn*hw, -hw, z], tip, 2.0);
            strut([sgn*hw, 0, z+5], tip, 2.0);
            // Isolator am Auslegerende (Stummel + haengende Kugel)
            translate([sgn*arm, 0, z]) cylinder(h = 5, d = 3, $fn = 6);
            translate([sgn*arm, 0, z-5]) sphere(d = 4);
        }
    }
    // Spitze
    translate([0, 0, h]) cylinder(h = 16, d1 = 5, d2 = 0.6, $fn = 4);
    translate([0, 0, h]) cube([2*topw+2, 1.5, 1.5], center = true);
}

// ============================ AUSKRAGENDES HOCHHAUS ===============
// Sci-Fi-Turm mit auskragendem Obergeschoss (braucht Stuetzen).
module cantilever_tower() {
    w = 34; d = 28;
    // Schaft
    difference() {
        cube([w, d, 90]);
        translate([wall, wall, -1]) cube([w-2*wall, d-2*wall, 90]);
    }
    // auskragendes Obergeschoss (ragt seitlich heraus -> Support)
    translate([-14, -6, 70])
        difference() {
            cube([w+28, d+12, 22]);
            translate([wall, wall, -1]) cube([w+28-2*wall, d+12-2*wall, 22]);
        }
    // Dachaufbau + schraege Antenne
    translate([0, 0, 92]) cube([w, d, 8]);
    translate([w/2, d/2, 100]) rotate([0, 20, 0]) cylinder(h = 30, d1 = 3, d2 = 0.5, $fn = 4);
}

// ============================ AUSGABE =============================
if (show == "cooling_tower")      cooling_tower();
else if (show == "reactor")       reactor_dome();
else if (show == "reactor_spire") reactor_spire();
else if (show == "chimney")       chimney();
else if (show == "tank")          tank();
else if (show == "power_plant")   power_plant();
else if (show == "pylon")         power_pylon();
else if (show == "cantilever_tower") cantilever_tower();
else {
    cooling_tower();
    translate([75, 0, 0])  reactor_spire();
    translate([130, 0, 0]) chimney();
    translate([165, 0, 0]) tank();
    translate([240, 0, 0]) power_pylon();
    translate([320, 0, 0]) cantilever_tower();
}

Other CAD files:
3d-models/stl/subcover_q3.stl
3d-models/stl/building_t9.stl
3d-models/stl/sf_chimney.stl
3d-models/stl/lamp_b.stl
3d-models/scad/skyline_buildings.scad
3d-models/scad/speaker_enclosures.scad
3d-models/scad/subwoofer_cover.scad
3d-models/stl/LED_Clip_CarreraGo.stl
3d-models/stl/building_t10.stl
3d-models/stl/building_t2.stl
3d-models/stl/lamp_c.stl
3d-models/stl/satellite_baseplate.stl
3d-models/stl/satellite_lower.stl
3d-models/stl/satellite_upper.stl
3d-models/stl/sf_pylon.stl
3d-models/stl/subcover_q2.stl
3d-models/stl/subcover_q4.stl
3d-models/stl/subwoofer_baseplate.stl
3d-models/stl/subwoofer_lower.stl
3d-models/stl/subwoofer_upper.stl

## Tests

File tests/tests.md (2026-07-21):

# Unit Tests Overview

This document provides an overview of the test suite for the LumenTrace project. The tests validate core functionality across the game engine, display system, input handling, and audio components.

These tests were instrumental during the development phase for validating physics behavior, LED rendering logic, and controller integration. While some tests may require maintenance due to code evolution, they remain a valuable reference for understanding the intended behavior of core systems.

## Test Structure

The test suite is organized by module, mirroring the source code architecture:

### Controller Tests (`controller_test/`)

Tests for the input signal handling and controller interface:

- **Signal receiver initialization and data structure validation**
- Controller state management and signal payload formats
- Mock controller behavior for deterministic testing

### Display Tests (`display_test/`)

Tests for LED display rendering and visual effects:

- **Display hierarchy validation** - Verifies correct layering of track modules, vehicles, and visual effects
- Virtual LED strip buffer management and color mapping
- Vehicle position rendering with speed-based color indicators
- Round advance animations and lane change visual feedback
- Intersection lane rendering

### Game Tests (`game_test/`)

High-fidelity physics and game logic validation:

- **Lane change mechanics** - Multi-hop changes, position conversion proportionality, end-window blocking
- **Vehicle kinematics** - Friction, acceleration, speed updates, and position wrapping
- **Driving profile enforcement** - Speed and acceleration boundary checking across module transitions
- **Lane gap detection** - Fall triggering when crossing missing lanes between modules
- **Collision detection** - Same-lane rear-end collision handling
- **Respawn behavior** - Lane occupation checks, round preservation, and spawn position selection

These tests provide high-signal validation of core game rules described in the project README.

### Display Manager Tests (`display_test/`)

Integration tests for game state to visual representation:

- Vehicle active state and respawn ticking color blending
- Track module boundary visualization
- Round advance cycle animations with timing verification

### Sound Tests (`sound_test/`)

Audio system validation:

- Sound manager initialization and audio stream setup
- Master volume clamping and control
- Active sound tracking and playback management

### Simulation Tests (`simulation_test/`)

*Note: Most simulation tests are currently commented out. They were used during development for local terminal visualization and deterministic behavior validation but may require updates due to API changes.*

## Running the Tests

Execute tests using pytest [krekel:2026pytest]:

```bash
pytest tests/
```

To run tests for a specific module:

```bash
pytest tests/game_test/
pytest tests/display_test/
pytest tests/controller_test/
```

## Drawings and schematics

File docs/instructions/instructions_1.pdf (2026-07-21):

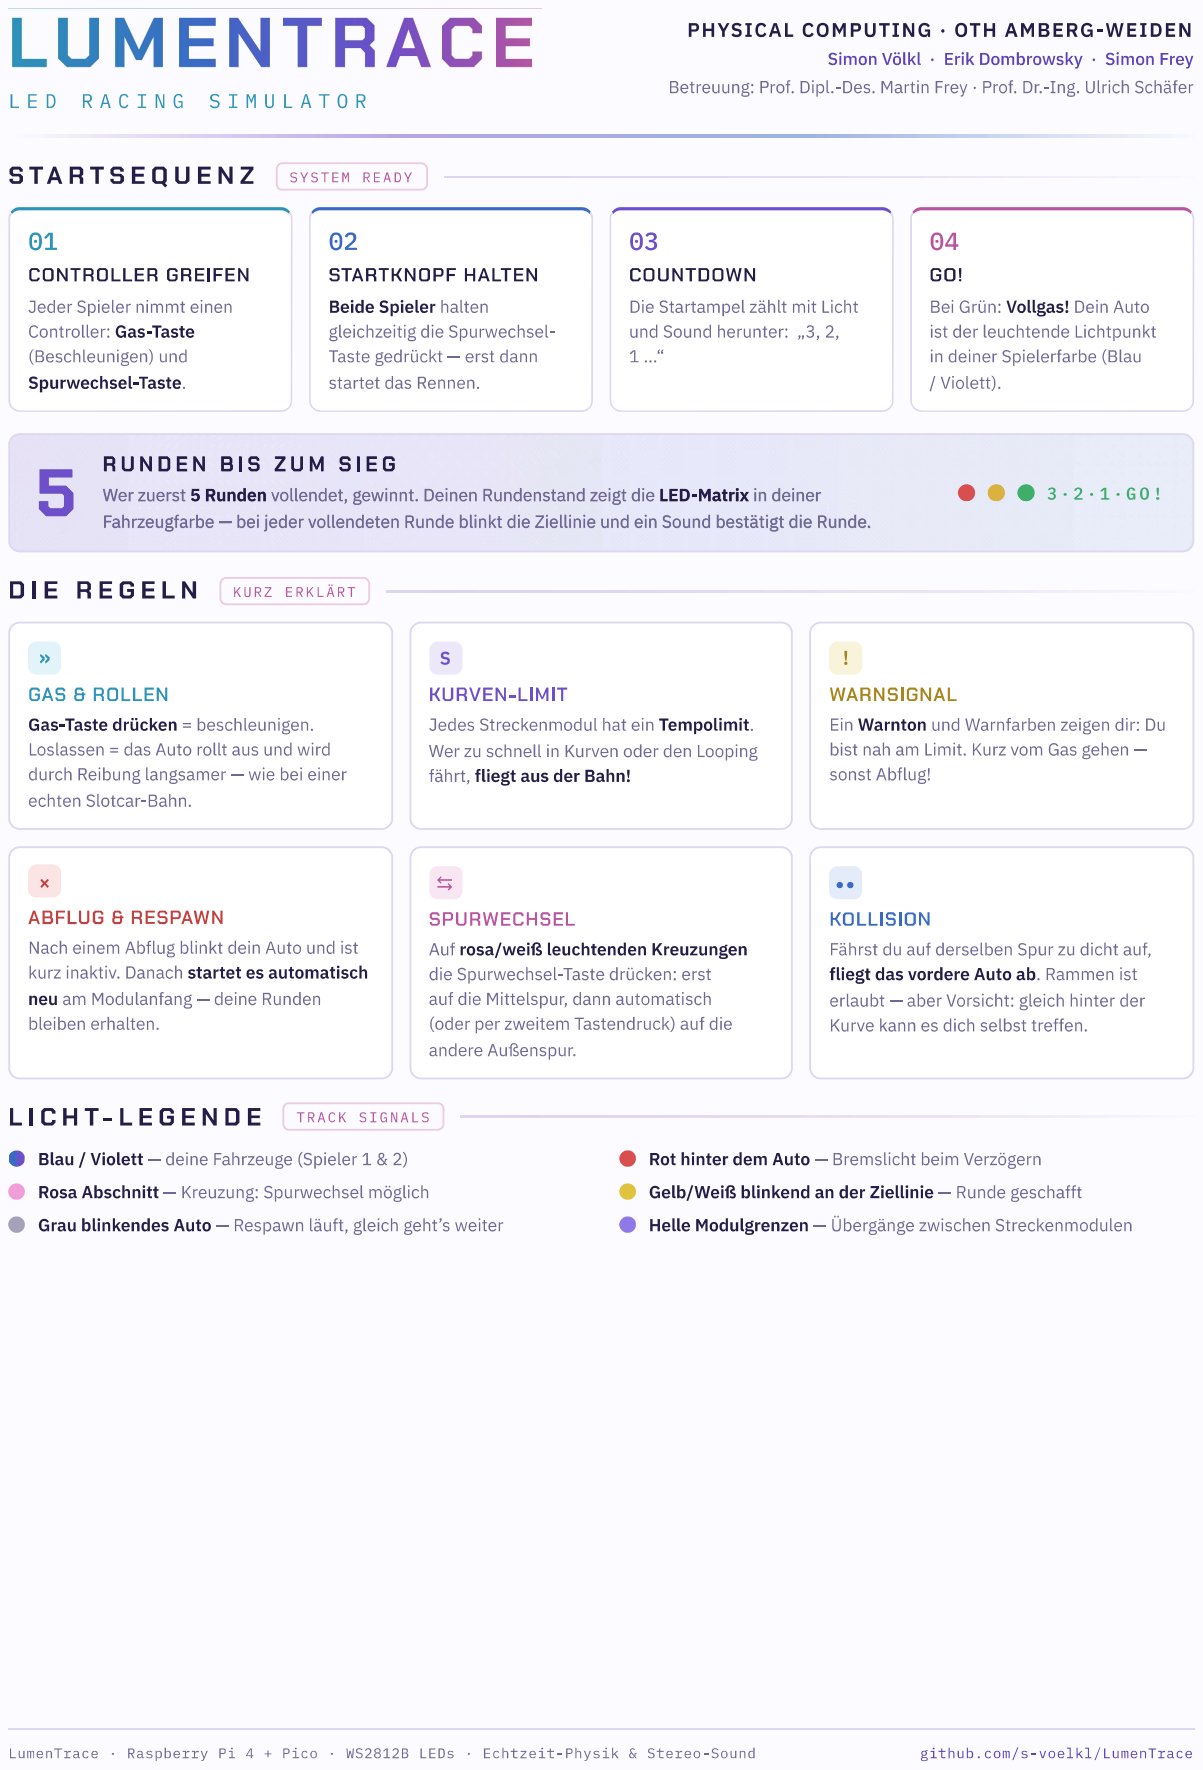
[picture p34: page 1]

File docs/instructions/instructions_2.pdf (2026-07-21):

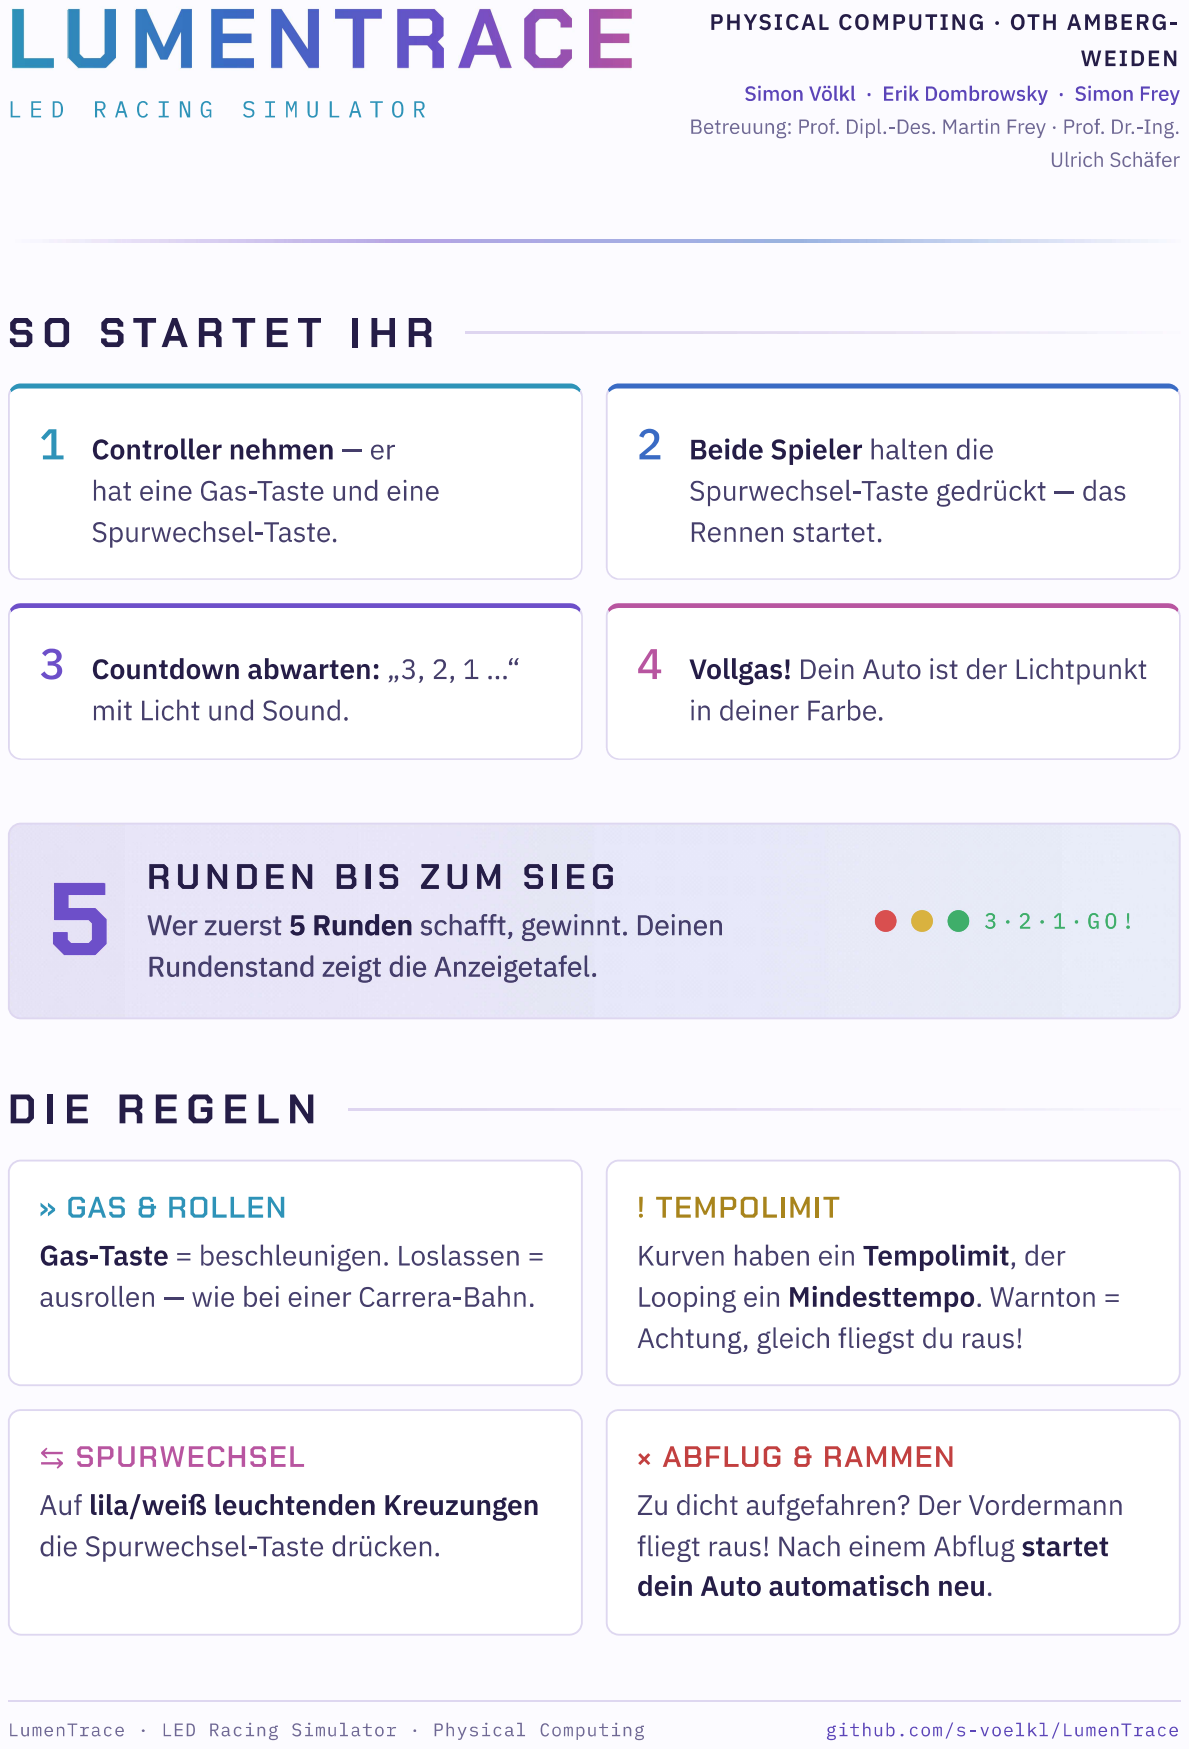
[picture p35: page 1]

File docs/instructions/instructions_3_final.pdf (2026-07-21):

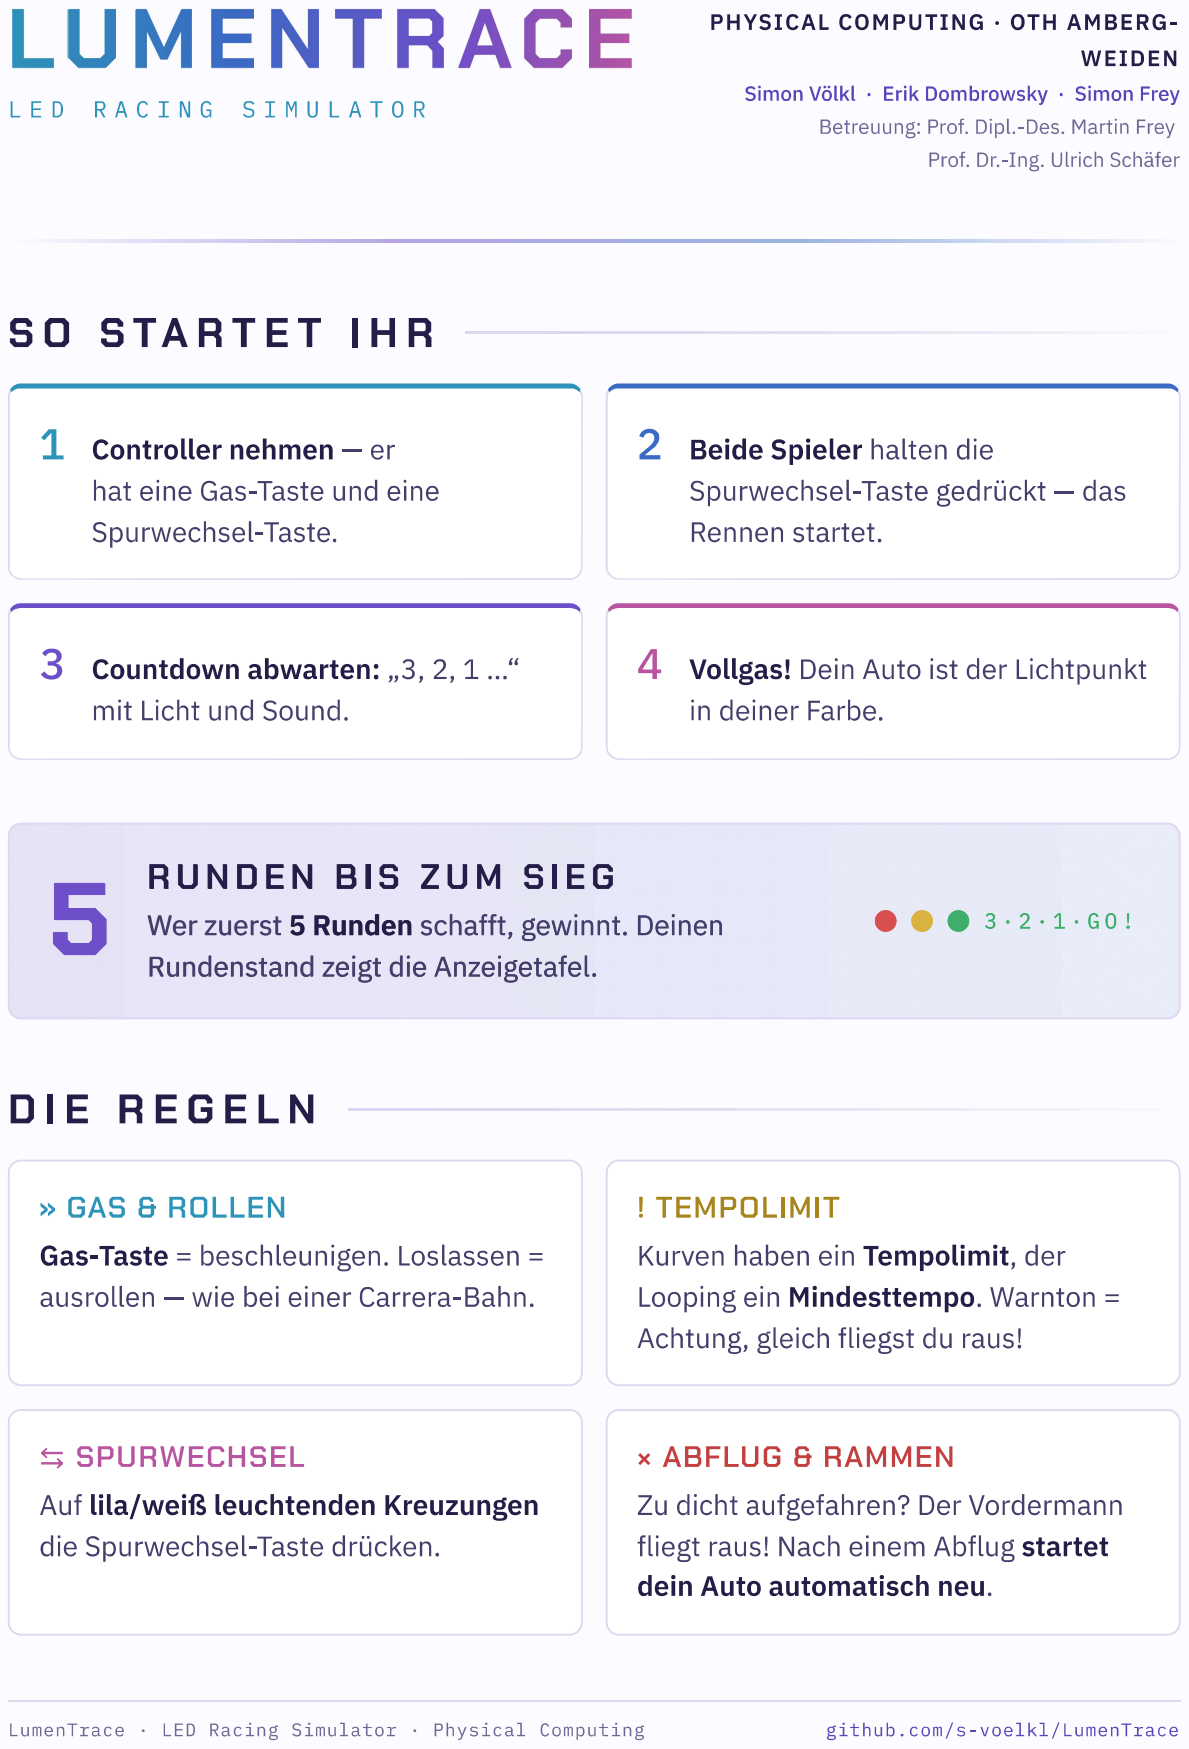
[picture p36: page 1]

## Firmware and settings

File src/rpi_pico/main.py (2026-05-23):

import time
import json
import machine as ma

def main():
    physical_controllers = [
        PhysicalController(adc_pins=[26], digital_pins=[21]),
        PhysicalController(adc_pins=[27], digital_pins=[20])
    ]
    signal_transmitter = SignalTransmitter(controllers=physical_controllers)
    while True:
        # print("Transmitting signal...")
        # time.sleep(0.05)
        signal_transmitter.transmit_signal()


class SignalTransmitter:
    '''Handles the outgoing UART-signal as the transmitter for further processing.'''

    __BAUD_RATE = 115200

    def __init__(self,
        tx_pin=0,
        rx_pin=1,
        baud_rate=__BAUD_RATE,
        bits=8,
        parity=None,
        stop=1,
        controllers = None):
        '''Initializes the SignalTransmitter with the specified UART configuration and a list of physical controllers to read values from.

        Args:
            tx_pin (int, optional): The GPIO pin number for the UART transmit pin. Defaults to 0.
            rx_pin (int, optional): The GPIO pin number for the UART receive pin. Defaults to 1.
            baud_rate (_type_, optional): The baud rate for the UART communication. Defaults to __BAUD_RATE.
            bits (int, optional): The number of data bits for the UART communication. Defaults to 8.
            parity (_type_, optional): The parity setting for the UART communication. Defaults to None.
            stop (int, optional): The number of stop bits for the UART communication. Defaults to 1.
            controllers (list[PhysicalController], optional): A list of physical controllers to read values from. Defaults to [].
        '''

        self.serial = ma.UART(0, baudrate=baud_rate, tx=ma.Pin(tx_pin), rx=ma.Pin(rx_pin),
            bits=bits, parity=parity, stop=stop)
        self.controllers = controllers if controllers is not None else []

    def transmit_signal(self, sleep_s = 0.05):
        '''Transmits the current values of the physical controllers as a JSON object via UART.
        Even if no change in the values of the physical controllers is detected, 
        the current values will be transmitted at regular intervals.

        Args:
            sleep_s (float, optional): The time to sleep between transmissions, in seconds. Defaults to 0.05.
        '''

        # read value(s) from ADCs of the physical controllers
        controllers_data = []
        
        for controller in self.controllers:
            values = controller.read_values()
            # Combine ID and data
            entry = {"controller_id": controller.controller_id}
            entry.update(values)
            controllers_data.append(entry)
            

        # build complete json
        data = {"controllers": controllers_data}
        
        # send via UART as JSON string
        self.serial.write((json.dumps(data) + "\n").encode('utf-8'))
        time.sleep(sleep_s)

class PhysicalController:
    '''
    Represents a physical controller with multiple ADC pins.
    Each controller can have multiple ADC pins, that can be read.
    
    Args:
        controller_id (int): The unique identifier for the controller.
        adc_pins (list[int]): A list of GPIO pin numbers for the ADC pins.
    '''
    
    # static controller count to generate default controller ids
    _controller_count = 0

    def __init__(self, adc_pins, digital_pins):
        '''Initializes the physical controller with a unique identifier and a list of ADC pins.

        Args:
            controller_id (int): The unique identifier for the controller.
            adc_pins (list[int]): A list of GPIO pin numbers for the ADC pins. 
                E.g., [26, 27] for ADC0 and ADC1 on Raspberry Pi Pico.
            digital_pins (list[int]): A list of GPIO pin numbers for the digital input pins.
        '''
        
        PhysicalController._controller_count += 1
        self.controller_id = PhysicalController._controller_count
        self.adc_controllers = []
        
        # multiple pins allowed per controller, e.g. for multiple sensors
        for pin in adc_pins:
            self.adc_controllers.append(ma.ADC(pin))
            
        self.dig_inputs = []
        for pin in digital_pins:
            self.dig_inputs.append(ma.Pin(pin, ma.Pin.IN))
            
    def __del__(self):
        # decrement controller count when a controller instance is deleted
        PhysicalController._controller_count -= 1
                    
    def read_values(self):
        """Read all ADC values from the controller's pins.
        
        Returns:
            dict[str, int]: Dictionary with ADC values keyed by pin index (e.g., "adc_0", "adc_1").
        """
        # read values of adc_0..n and save in self.data
        data = {}
        
        for i, adc_controller in enumerate(self.adc_controllers):
            data["adc_{}".format(i)] = adc_controller.read_u16()
            
        for i, dig in enumerate(self.dig_inputs):
            data["dig_" + str(i)] = dig.value()
            
        return data
    
if __name__ == "__main__":
    main()

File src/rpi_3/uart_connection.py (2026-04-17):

# Aufbau: Pico 
# - UART0-TX (1) mit UART1-RX (12)
# - UART0-RX (2) mit UART1-TX (11)

# Baudrate: typischerweise 9600
# Anzahl der Datenbits: typischerweise 8
# Anzahl der Stopbits: Typischerweise 1
# Parität: Typischerweise None oder 0

# Bibliotheken laden
from machine import UART, Pin
from time import sleep

# adc
adc_controller = machine.ADC(26)

# UART0 initialisieren
uart0 = UART(0, baudrate=9600, tx=Pin(0), rx=Pin(1), bits=8, parity=None, stop=1)
print('UART0:', uart0)
print()

# UART1 initialisieren
uart1 = UART(1, baudrate=9600, tx=Pin(8), rx=Pin(9), bits=8, parity=None, stop=1)
print('UART1:', uart1)
print()

# Hauptprogramm
while True:
    gas_wert = adc_controller.read_u16()
    
    # Daten senden
    print('Gaswert:', gas_wert)
    uart0.write(str(gas_wert).encode('utf-8'))
    sleep(0.001)
    
    # Daten empfangen und ausgeben
    rxData = uart1.readline()
    try:
        print('Daten empfangen:', rxData.decode('utf-8'))
    except (AttributeError):
        print('Verbindung prüfen')
    sleep(0.001)
    print()

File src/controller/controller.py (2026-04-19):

class Controller:
    '''Virtual player controller with multiple inputs (e.g. forward, backward, left, right, special_1, special_2).
    These inputs get updated by the signal receiver based on the received UART signal 
    of the original physical controller via the signal transmitter. 

    Returns:
        Controller: A virtual player controller.
    '''
    
    INPUT_MAPPING: dict[str, str] = {
        "adc_0": "forward_press",
        "adc_1": "backward_press",
        "adc_2": "left_press",
        "adc_3": "right_press"
    }
    
    def __init__(self, controller_id: int):
        '''Initializes the controller with a unique identifier and an empty dictionary for inputs.

        Args:
            controller_id (int): The unique identifier for the controller.
        '''
        self.__controller_id = controller_id
        self.__forward_press: float = 0
        self.__backward_press: float = 0
        self.__left_press: float = 0
        self.__right_press: float = 0
        self.__special_1: float = 0
        self.__special_2: float = 0

        
    def update_input(self, input_name: str, value):
        '''Updates the corresponding input value based on the received signal.
        
        Args:
            input_name (str): The name of the input to be updated (e.g., "adc_0").
            value: The value to update the input with.
        '''
        
        # mapping of keys (e.g. adc_0) to internal names (e.g. forward_press)
        internal_name = self.INPUT_MAPPING.get(input_name)
        if internal_name and value is not None and value != getattr(self, f"__{internal_name}"):
            # TODO: log info for received signal update
            setattr(self, f"__{internal_name}", value)
            print(f"Info: Received signal update for controller {self.__controller_id}: {input_name} -> {internal_name}")
        else:
            # TODO: log warning for unmapped input name
            print(f"Warning: Received unmapped input name '{input_name}' for controller {self.__controller_id}.")
            
    # Getters
    @property
    def controller_id(self) -> int:
        '''Returns the unique identifier for the controller.'''
        return self.__controller_id
    
    @property
    def forward_press(self) -> float:
        '''Returns the forward press value.'''
        return self.__forward_press

    @property
    def backward_press(self) -> float:
        '''Returns the backward press value.'''
        return self.__backward_press

    @property
    def left_press(self) -> float:
        '''Returns the left press value.'''
        return self.__left_press

    @property
    def right_press(self) -> float:
        '''Returns the right press value.'''
        return self.__right_press

    @property
    def special_1(self) -> float:
        '''Returns the special 1 value.'''
        return self.__special_1
    
    @property
    def special_2(self) -> float:
        '''Returns the special 2 value.'''
        return self.__special_2

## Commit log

2026-04-17 pico config and raspy 3 uart connection
2026-04-19 extended drawio with Raspberry Pico, Controller, fixed mistakes
2026-04-19 set up and moved src folders/files, rename of doc files
    basic repo structure:
    src with rpi_pico, rpi_3 and dev folders for development based of hardware unit (rpi=raspberry pi abbreviation).
    setup of other folders (e.g. display) with __init__.py for package detection, correating to the architecture (see docs/architecture.drawio.
2026-04-19 Added Controller Logic
    Updated Drawio Architecture.
    Added transmitter and receiver for uart serial connection.
    Added physical and virtual controller classes. JSON data transmission. For each controller, the inputs (e.g. "uart_0": 1) get transmitted and received. In the (virtual) controller class, the inputs g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
2026-04-19 added launch.json for easier startup in rpi 3/pico main-classes. also guarantees error-freeness
2026-04-19 broad enhancement: fixed file issues, added logging services, added main instances, added testing
    [main.py, player_controller.py]
2026-04-19 updated architecture, small fixes, added logging into classes
    [player_controller.py, signal_receiver.py]
2026-04-20 pico signal transmitter test
2026-04-20 added simple test for driving an led
2026-04-20 better controller_id handling, updated mains rpi 3/pico
2026-05-01 feat: add Raspberry Pi 4 configuration documentation
2026-05-01 fix: pylogger error message, rpi4 main.py enhanced
    [main.py]
2026-05-04 fixed rpi pico type hint problems
    refactor: simplify type hints and improve readability in controller classes
    [main.py, physical_controller.py, signal_transmitter.py]
2026-05-04 testing refactor: signal receiver serial gpio pin deletion
2026-05-04 fixed signal receiver: ttyACM0 instead of ttyS0
    [signal_receiver.py]
2026-05-04 fix: controller work now, also lane change button
    [main.py, player_controller.py, signal_receiver.py]
2026-05-13 feat: implement Display class for WS2812 LED strip output
    - Add LaneStripConfig dataclass to map lanes to strip segments
    - Add Display class with update(game) for live vehicle rendering
    - Only vehicle positions lit, background stays dark (power safety)
    - Brightness hard-capped at 80/255 for safety
    - Graceful no-op when rpi_ws281x not available (dev machines)
    - Wire Display into Game via optional display= constructor param
    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
2026-05-27 fixing issues with display logic
    [main.py]
2026-05-27 refactor: replace Display with Displayer across the codebase
    [main.py]
2026-05-27 update controller files to match current pico state
2026-05-27 refactor: replace Displayer with LedDisplay across the codebase
    [main.py]
2026-05-27 update rpi_4_config.md to require sudo for code execution; add basic LED test script
2026-05-27 Adding a working example of the led test on the game. Simplifying main method
2026-05-27 Enhance LED display functionality and improve vehicle state management
    - Updated README.md to include detailed LED implementation information.
    - Refined color constants in color_constants.py with improved documentation.
    - Enhanced display logic in display_logic.txt for better vehicle color indication.
    - Improved display_manager.py with clearer rendering hierarchy and vehicle pixel handling.
    - Updated led_display.py to support relative position handling for pixel updates.
    - Modified game.py to include vehicle speed and acceleration in round change events.
    - Adjusted settings.py to allow configurable vehicle crash distance.
    - Expanded vehicle.py documentation for clarity on vehicle attributes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
    [main.py]
2026-05-27 Prepare release for basic led implementation with readme update
2026-06-03 feat: Add engine sound generation and playback functionality
    - Implemented EngineSoundPlayer class for real-time audio playback with dynamic pitch and speed control.
    - Created engine_sound_generator.py to generate synthetic engine sounds and save them as WAV files. (nutzlos)
    - Developed entchen_test.py to play a melody using the engine sound with pitch modulation. (funny)
    - Added sound_test.py to simulate car acceleration and deceleration with stereo panning.
    - Introduced unit tests for EngineSoundPlayer to ensure proper initialization, speed setting, and audio callback logic.
2026-06-15 Fix docker start issues, adjust logging
    [main.py]
2026-06-16 Measured track modules
2026-06-16 Set settings and min/max speed 🏝️
2026-06-16 led settings
2026-06-16 Adjust colors 🎨
2026-06-16 Fix sound problems 🔊
2026-06-16 led strip tests
2026-06-16 Vibration actor signal fix mapping 📳
2026-06-16 Dev and simulation add sound 🔉
2026-06-18 Add method to clear leds, fix led strip positioning.
    [main.py]
2026-06-18 Update lane change logic
    vehicle.py: Replaced old line change logic with lane_change_target and lane_change_start_position properties.
    Updated bounding methods, like trigger_respawn, to adequately clear/reset these properties upon vehicle resets.
    Added appropriate getter and setter methods (set_lane_change and clear_lane_change).
    game.py:
    Switched from caching __lane_change_start_positions and __lane_change_targets on the Game instance to directly utilizing the attributes from Player.vehicle.
    Replaced the specific properties during __fall_player to clean up the vehicle's state itself.
    The lane change logic now effectively acts based on these vehicle settings, letting players change back man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
    [main.py]
2026-06-18 3d modelle und scad
    [lamp_posts.scad, satellite_baseplate.stl, satellite_lower.stl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]
2026-06-19 Cut and enhanced audio samples for better quality and less startup delay.
2026-06-23 Fix auto startup sound
    [main.py]
2026-06-23 Color adjustments 🎨
2026-06-23 Added track module sound locations and fixed errors
    [main.py]
2026-07-03 Add round led display logic, game loop, fix second intersection handling.
    [main.py]
2026-07-03 Potential fix of sound manager audio callback problems.
    [main.py]
2026-07-03 led changed
2026-07-03 3D Models to Repo
    Added 3d Models to Repo
    [building_t1.stl, building_t10.stl, building_t2.stl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]
2026-07-03 Enable motor audio
2026-07-03 TODO: Problems with round counter!!!
    [main.py]
2026-07-07 Fix round counter problems potentially.
    TODO: Attach led matrizes at the end of the already existing strips.
    [main.py]
2026-07-08 Update led strip led counts.
2026-07-08 Adjust ordering of matrix and led strips.
2026-07-08 Fix led settings.
2026-07-08 Enhance performance: Fix threading issues.
    [main.py]
2026-07-08 Coin sound and lane change logic fix. Parameter adjustment.
    [main.py]
2026-07-08 Adjust led clear logic.
2026-07-08 Having issues with starting docker container led strip random colors
    [main.py]
2026-07-13 Startup problem fixes found and applied
    [main.py]
2026-07-14 Move 3d model files.
    [LED_Clip_CarreraGo.scad, LED_Clip_CarreraGo.stl, lamp_posts.scad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]
2026-07-15 Adjusting track modules.
2026-07-21 Add Open LED Race Project references and details to documentation
